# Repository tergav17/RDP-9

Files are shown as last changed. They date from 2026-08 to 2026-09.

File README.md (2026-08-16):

# RDP-9

## Project Description

This project aims to build an ISA-compatible clone of the DEC PDP-9 system using primarily technology from the late 1970s - early 1980s period. I did this to ensure my design followed the same constraints that later genuine minicomputer systems were built with, while being able to significantly reduce the size and complexity compared to an actual PDP-9. The specifics are as follows

- Use only 74-series logic and other similar TTL logic level parts that would be available around the later 1970s timeframe. The exception to this is RAM, which I plan to use more “modern” SRAM chips instead of torturing myself with dynamic RAM.
- No FPGAs, PALs, GALs, microcontrollers, etc in the main processor path. The only exception to this is using standard 27C style ROM chips to hold the microcode.
- Usage of a period correct microcontroller or microprocessor for the disk / drum subsystem. Using another simpler processor to control complex devices like disks was done frequently on other minicomputer designs, so I’ll be doing it here too.

My end goal is to build a system that is capable of running most of the interesting software of the period. This includes DECsys, ADSS, DOS-15, and UNIX V0. To do this, the system will need:

- Full compatibility with the PDP-9 instruction set. This includes EAE instructions and extended memory
- The ability to hook up to a real or emulated paper tape punch / reader.
- The ability to hook up to a real or emulated ASR-33 teletype or similar serial terminal
- 8" floppy drive interface in place of DECtape. Software will require patching but it's better than trying to emulate DECtape
- IDE hard drive support using RB09/RF09 interface 

## Theory of Operation

Due to the complexity involved with the architecture of the DEC PDP-9, the system is split into two subsystems:

The first subsystem is the processor itself. It has a full 18-bit datapath with 15-bit address bus, and is implemented entirely using TTL logic.

The second subsystem is the I/O bus. This is directly controlled by the processor itself and is capable of servicing the following operations:

- Device interrupts
- IOT transactions
- Add-to-memory operations
- Data channel transfers
- DMA transfers
- READ-IN operation

### Device Interrupts

Device interrupts simply tell the processor to begin an interrupt operation. When an interrupt is accepted, the I/O bus will be notified of the action
and is responsible for turning off the "Program Interrupt" flag. If this does not happen, interrupts will continuously loop. 

#### Steps:

1. Interrupt is accepted. MA is completely zeroed and the "INTERRUPT_DETECT" pulse is asserted for this clock cycle.

2. PC is stored in MB, OB

3. The logical OR of MB and OB is place in CORE at MA. The crossbar will add the LINK and MEMM flags

4. MA + 1 is placed in the PC. Extend is enabled to ensure that bank 0 is selected. The next fetch will ignore device requests

### IOT Transactions

IOT transactions allow data to be transferred to or from the accumulator. IOTs also allow for skips to be requested. Every IOT is treated by the CPU
as a Read-Modify-Write operation. By using the "EXTRN" signal, devices can notify the processor to read from the I/O bus instead of the writeback register.
When the I/O bus is being sampled, the "IOT_SKIP" signal can be asserted to tell the processor to perform an addition increment of the program counter.

A wait signal is sampled at the beginning of the IOT as well. This can be used to add cycles to the writeback phase of the IOT if the device needs it.

#### Steps:

1. IOT transaction begins. Device address is placed on the I/O address bus. AC (or 0 if the flag is set) is written to the WRTBK register.

2. Signal "IOT_PULSE" is asserted.

3. Signal "IOT_PULSE" remains asserted. External input is sampled into MB. Signal "EXTRN" must be asserted to take value from device bus.

4. IF "IOT_WAIT" is asserted, goto step 3 in place. No IOT signals are asserted. Interally, the CPU is performing the logical OR and writeback of potential provided data.

5. No IOT signals are asserted. Internally, the CPU will perform the skip here if it has been requested. The next fetch cycle will ignore interrupts and device requests.

### Device Requests

The final three transaction types (Add-to-memory, data-channels, and DMA transfers all share the "device request" pathway.

#### Steps:

1. Signal "REQ_ADDR_PHASE" and "DEV_REQ_GRANT" asserted and held. External value written to MA.

2. If DMA is selected, core is read at MA and written to WRTBK with next as step 8. Otherwise core is read at MA and written to MB, OB. "REQ_ADDR_PHASE" held

3. Value in MB, OB incremented and written back to core at MA and OB. "REQ_ADDR_PHASE" held

4. Value in MA incremented. If add to memory selected, Jump to fetch without device request logic. "INCREMENT_ZERO_PUSLE" will be generated if needed. "REQ_ADDR_PHASE" held

5. Core is read at MA and written to MB, OB.

6. Value in MB, OB incremented and written back to core at MA and MA

7. Core is read at MA and written to WRTBK

8. External value written to core at MA. "DEV_REQ_GRANT" reset. Jump to fetch without device request logic

### READ-IN Operation

The read-in is used to transfer a set series of words into memory from one of the I/O devices. Only one I/O device can be be allowed to respond to READ-IN
at any one time. When a READ-IN transaction is active, the CPU will stall until the designated device signals that it is ready. The device will either signal
the CPU to commence another READ-IN cycle, or to terminate the READ-IN after any given transfer.

#### Steps:

1. SWR is moved into PC

2. "READ_IN_PULSE" is asserted, step will loop till either "IOT_WAIT" or "IOT_SKIP" are asserted.

3. "READ_IN_PULSE" remains asserted. EXTRN is moved into core at PC. Continue having the constant value asserted.

4. "READ_IN_PULSE" reset. If "IOT_SKIP" is asserted, jump to CONT logic. Otherwise move PC + 1 into PC

5. Null phase, "READ_IN_PULSE" remains reset.

6. Null phase, "READ_IN_PULSE" remains reset. Jump to step 2 on completion

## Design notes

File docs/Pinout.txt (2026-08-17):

/* Front Panel */

RDP-9A-FPR-0	Register Front Panel Segment (MB, AC, MQ, SWR)
PRD-9A-FPA-0	Address Front Panel Segment (Flags, MA, PC, CTRL Switches)

/* Backplane */

RDP-9A-BKP-0	CPU + I/O Backplane

/* CPU Cards */

RDP-9A-CTL-0	Microcode Control Card
RDP-9A-REG-0	Register File Card
RDP-9A-ALU-0	ALU Card
RDP-9A-MEM-0	Memory / Addressing Card

/* I/O Cards */

RDP-9A-TTC-0	TTY / Clock / Flags Card
RDP-9A-PRB-0	Paper tape / RB Emulator Card

/* CPU Backplane Pinout */

SIGNAL			COUNT	DESCRIPTION				PULL_UP		SOURCE	DONE
D				18		Data Bus							N/A		X
A				15		Address Bus							N/A		X
STEP_ZERO		1		STEP Register Zero					REG		X
*PI_ENABLE		1		Interrupt Enable		X			BKP		X
*MEMM_ENABLE	1		Ext Memory Enable		X			BKP		X
*PROT_ENABLE	1		Protection Enable 		X			BKP		X
*DMA_REQ		1		DMA Request				X			BKP		X
*CHAN_REQ		1		Data Channel Request	X			BKP		X
*DEV_REQ		1		Device request			X			BKP		X
*INT_REQ		1		Interrupt request		X			BKP		X
*IOT_SKIP		1		IOT Skip				X			BKP		X
*IOT_WAIT		1		IOT Wait				X			BKP		X
*REST_PEND		1		Restore Pending			X			BKP		X
*IOT_SKIP_L		1		IOT Skip Latched					ALU		X
FLAG_ZERO		1		OB Zero Flag						ALU		X
FLAG_SIGN		1		OB Sign Flag						ALU		X
FLAG_LINK		1		Link Flag							ALU		X
FLAG_LINK_INIT	1		Link Init Flag						ALU		X
FLAG_AC_SIGN	1		AC Sign Flag						ALU		X
BUS_SELECT		3		Data Bus Selector					CTL		X
*SELECT_AC		1		Bus Select AC						CTL		X
*SELECT_STEP	1		Bus Select STEP						CTL		X
*SELECT_MQ		1		Bus Select MQ						CTL		X
*SELECT_CROSS	1		Bus Select Crossbar					CTL		X
*SELECT_ALU		1		Bus Select ALU						CTL		X
*SELECT_CORE	1		Bus Select Core						CTL		X
*SELECT_SWR		1		Bus Select SWR						CTL		X
*SELECT_EXTRN	1		Bus Select External					CTL		X
*LATCH_IR		1		Latch IR Register					CTL		X
*LATCH_MA		1		Latch MA Register					CTL		X
*LATCH_PC		1		Latch PC Register					CTL		X
*LATCH_AC		1		Latch AC Register					CTL		X
*LATCH_STEP		1		Latch STEP Register					CTL		X
*LATCH_MQ		1		Latch MQ Register					CTL		X
*LATCH_MB		1		Latch MB Register					CTL		X
*LATCH_WRTBK	1		Latch WRTBK Register				CTL		X
*LATCH_OB		1		Latch OB Register					CTL		X
*WRITE_CORE		1		Write to Core						CTL		X
SELECT_PCMA		1		Select PC / MA						CTL		X
HALT			1		Halt Indicator						CTL		X
ADDR_MODE		2		Address Register Mode				CTL		X
CTL_CONST		1		Control Constant Value				CTL		X
*IOT_PULSE		1		IOT Pulse							CTL		X
*DRQ_GRANT		1		Device Request Grant				CTL		X
REQ_ADDR		1		IO Request Address					CTL		X
*JMP_I_DETECT	1		JMP I Detect						CTL		X
*INT_DETECT		1		Interrupt Detect					CTL		X
*READ_IN_PULSE	1		Read In Pulse						CTL		X
ALUO			3		ALU Operation						CTL		X
LINKS			2		Link Select							CTL		X
ALU_SHIFT		1		ALU Select Shifter					CTL		X
ALU_ONES		1		ALU Select Ones Comp				CTL		X
MA_AUTO_INX		1		MA Auto Index Flag					MEM		X
NEXT_BANK0		2		Next Memory Bank					MEM		X
CLK				1		Clock								BKP
FP				4		Front Panel Status					FTP
*CAF			1		Clear All Flags						BKP
*RESET			1		CPU RESET							BKP
 
			Control Connector

GND				A01 C01		+5V
N/C				A02 C02		N/C
*PI_ENABLE		A03 C03		STEP_ZERO
*MEMM_ENABLE	A04 C04		FLAG_ZERO
*PROT_ENABLE	A05 C05		FLAG_SIGN
*DMA_REQ		A06 C06		FLAG_LINK
*CHAN_REQ		A07 C07		FLAG_LINK_INIT
*DEV_REQ		A08 C08		FLAG_AC_SIGN
*INT_REQ		A09 C09		BUS_SELECT0
*IOT_SKIP		A10 C10		BUS_SELECT1
*IOT_WAIT		A11 C11		BUS_SELECT2
*IOT_SKIP_L		A12 C12		*SELECT_AC
*LATCH_IR		A13 C13		*SELECT_STEP
*LATCH_MA		A14 C14		*SELECT_MQ
*LATCH_PC		A15 C15		*SELECT_CROSS
*LATCH_AC		A16 C16		*SELECT_ALU
*LATCH_STEP		A17 C17		*SELECT_CORE
*LATCH_MQ		A18 C18		*SELECT_SWR
*LATCH_MB		A19 C19		*SELECT_EXTRN
*LATCH_WRTBK	A20 C20		*IOT_PULSE
*LATCH_OB		A21 C21		*DRQ_GRANT
*WRITE_CORE		A22 C22		REQ_ADDR
SELECT_PCMA		A23 C23		*JMP_I_DETECT
ALUO0			A24 C24		*INT_DETECT
ALUO1			A25 C25		*READ_IN_PULSE
ALUO2			A26 C26		HALT
LINKS0			A27 C27		ADDR_MODE0
LINKS1			A28 C28		ADDR_MODE1
ALU_SHIFT		A29 C29		CTL_CONST
ALU_ONES		A30 C30		EXTRA0
N/C				A31 C31		+12V
+5V				A32 C32		GND

			Data Connector
			
GND				A01 C01		+5V
N/C				A02 C02		N/C
D0				A03 C03		A0
D1				A04 C04		A1
D2				A05 C05		A2
D3				A06 C06		A3
D4				A07 C07		A4
D5				A08 C08		A5
D6				A09 C09		A6
D7				A10 C10		A7
D8				A11 C11		A8
D9				A12 C12		A9
D10				A13 C13		A10
D11				A14 C14		A11
D12				A15 C15		A12
D13				A16 C16		A13
D14				A17 C17		A14
D15				A18 C18		SC0
D16				A19 C19		SC1
D17				A20 C20		SC2
*RESET			A21 C21		SC3
*CAF			A22 C22		SC4
CLK				A23 C23		SC5
EXTRA1			A24 C24		EXTRA2
EXTRA3			A25 C25		EXTRA4
EXTRA5			A26 C26		EXTRA6
NEXT_BANK0		A27 C27		NEXT_BANK1
*REST_PEND		A28 C28		MA_AUTO_INX
FP0				A29 C29		FP1
FP2				A30 C30		FP3
N/C				A31 C31		+12V
+5V				A32 C32		GND

/* IO Backplane Pinout */

SIGNAL			COUNT	DESCRIPTION				PULL_UP		SOURCE	DONE
ID				18		I/O Data Bus						N/A		X
A_DEVICE		6		Device ID							BKP		X
A_SUBDEV		2		Sub-Device ID						BKP		X
A_PULSE			3		I/O Pulse							BKP		X
REQ_ADDR		1		Request Address						BKP		X
*IORS_FLAG		4		User-Defined IORS		X			N/A		X
*PTR_FLAG		1		Paper Tape Reader Flag	X			PRB		X
*PTP_FLAG		1		Paper Tape Punch Flag	X			PRB		X
*PTR_TAPE		1		Read Tape Detect		X			PRB		X
*PTP_TAPE		1		Punch Tape Detect		X			PRB		X
*PI_ENABLE		1		Interrupt Enabled		X			FLG		X
*MEMM_ENABLE	1		Ext Memory Enabled		X			FLG		X
*REST_PEND		1		Restore Pending			X			FLG		X
*INT_REQ		1		Interrupt Request		X			N/A		X
*DMA_REQ		1		DMA Request				X			N/A		X
*CHAN_REQ		1		Channel Request			X			N/A		X
*EXTERNAL		1		External Data			X			N/A		X
*IOT_SKIP		1		IOT Skip Request		X			N/A		X
*IOT_WAIT		1		IOT Wait Request		X			N/A		X
*DRQ_GRANT		1		Data Request Grant					BKP		X
*INT_DETECT		1		Interrupt Detect					BKP		X
*JMP_I_DETECT	1		JMP I Detect						BKP		X
*IOT_PULSE		1		IOT Pulse							BKP		X
*READ_IN_PULSE	1		Read In Pulse						BKP		X
*READ_IN_CLEAR	1		Read In Clear						BKP		X
*INCREMENT_ZERO	1		Increment Zero						BKP		X
CLK				1		Clock								BKP		X
*CAF			1		Clear All Flags						BKP		X
*CAF_REQ		1		Clear All Flags Request	X			N/A		X
*RESET			1		CPU Reset							BKP		X

			  I/O Connector

GND				A01 C01		+5V
N/C				A02 C02		*IOT_SKIP
ID0				A03 C03		A_DEVICE0
ID1				A04 C04		A_DEVICE1
ID2				A05 C05		A_DEVICE2
ID3				A06 C06		A_DEVICE3
ID4				A07 C07		A_DEVICE4
ID5				A08 C08		A_DEVICE5
ID6				A09 C09		A_SUBDEV0
ID7				A10 C10		A_SUBDEV1
ID8				A11 C11		A_PULSE0
ID9				A12 C12		A_PULSE1
ID10			A13 C13		A_PULSE2
ID11			A14 C14		*IORS_FLAG0
ID12			A15 C15		*IORS_FLAG1
ID13			A16 C16		*IORS_FLAG2
ID14			A17 C17		*IORS_FLAG3
ID15			A18 C18		*PTR_FLAG
ID16			A19 C19		*PTP_FLAG
ID17			A20 C20		*PTR_TAPE
*RESET			A21 C21		*PTP_TAPE
*CAF			A22 C22		*PI_ENABLE
CLK				A23 C23		*MEMM_ENABLE
REQ_ADDR		A24 C24		*REST_PEND
*DRQ_GRANT		A25 C25		*INT_REQ
*INT_DETECT		A26 C26		*DMA_REQ
*JMP_I_DETECT	A27 C27		*CHAN_REQ
*IOT_PULSE		A28 C28		*EXTERNAL
*READ_IN_PULSE	A29 C29		*CAF_REQ
*READ_IN_CLEAR	A30 C30		*INCREMENT_ZERO
*IOT_WAIT		A31 C31		+12V
+5V				A32 C32		GND

TODO:
DRQ_GRANT
IOT_PULSE
JMP_I_DETECT
INT_DETECT
READ_IN_PULSE

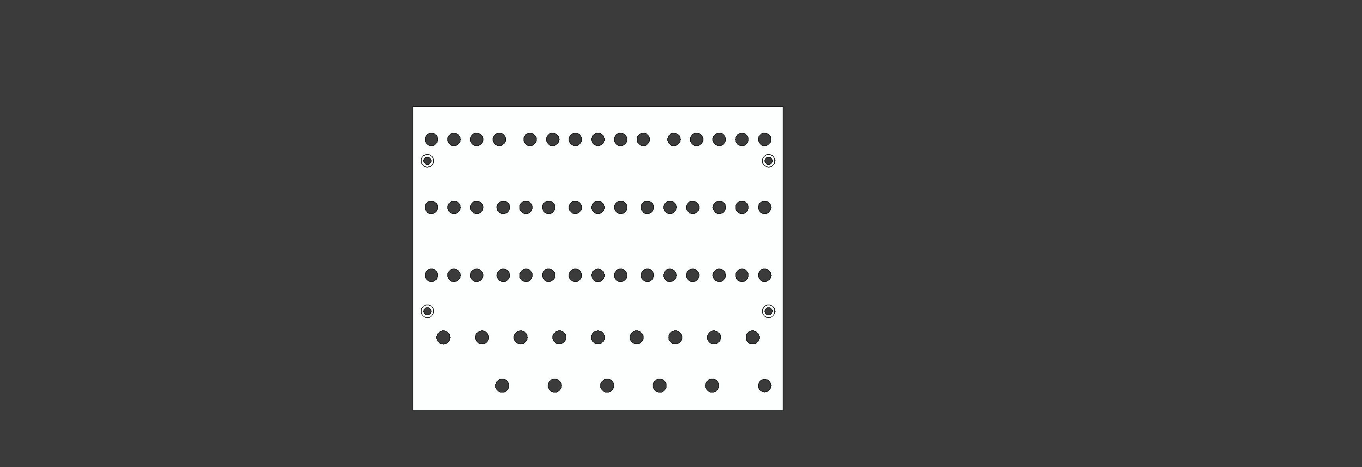
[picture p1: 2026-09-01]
freecad/Front Panels/Artwork/Address Panel.png

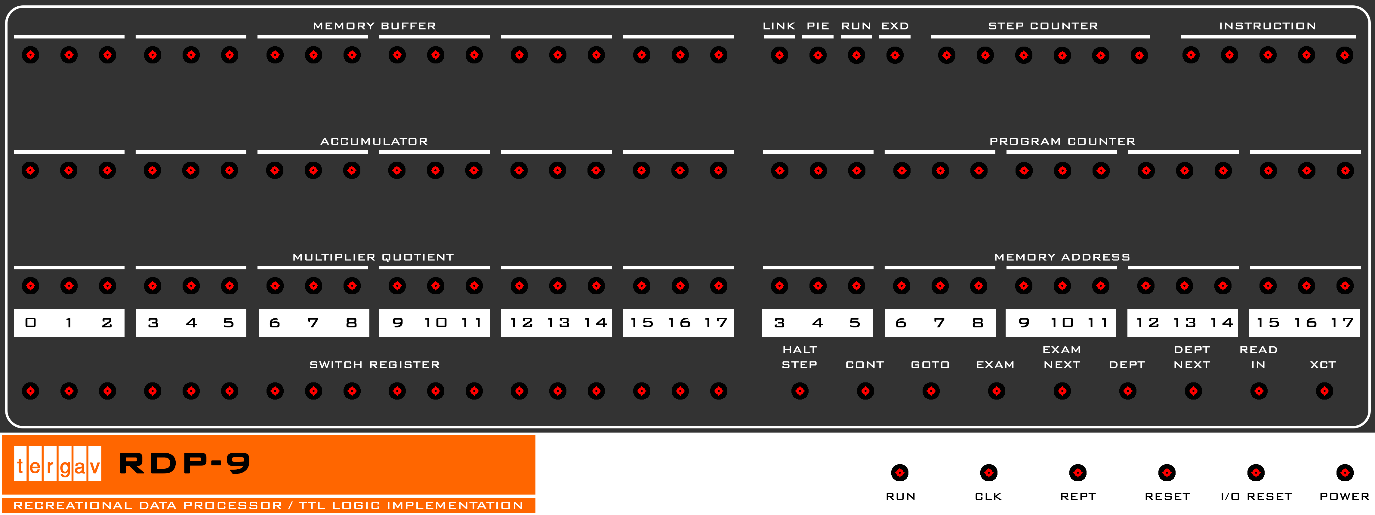
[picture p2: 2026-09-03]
freecad/Front Panels/Artwork/Front Panel Art.png

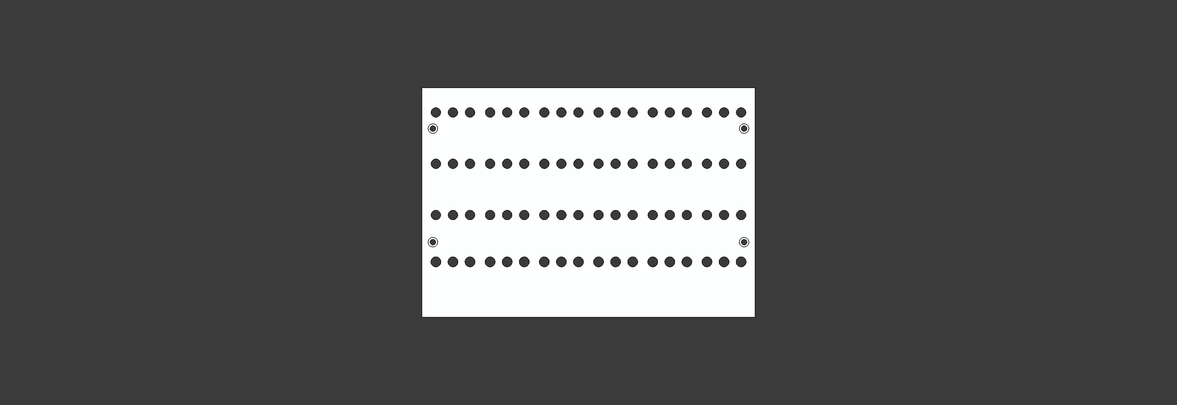
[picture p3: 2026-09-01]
freecad/Front Panels/Artwork/Data Panel.png

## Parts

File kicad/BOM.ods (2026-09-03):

Part | Quantity | Footprint | Link | Received?
Capacitor 10nf | 1 |  | https://www.aliexpress.us/item/3256804202811504.html | Yes
Capacitor 0.1uF | 188 |  | https://www.aliexpress.us/item/2251832762745366.html | Yes
Capacitor 1uF Polarized | 4 |  | https://www.aliexpress.us/item/3256811542313899.html | Yes
Capacitor 10uF | 1 |  | https://www.aliexpress.us/item/3256811448609794.html | Yes
Capacitor 100uf Polarized | 8 |  | https://www.aliexpress.us/item/3256811625053645.html | Yes
DIN41612 02x32 Male Horizontal | 14 |  | https://www.aliexpress.us/item/3256802176673542.html | Yes
DIN41612 02x32 Female Vertical | 14 |  | https://www.aliexpress.us/item/3256802176673542.html | Yes
IDC Header 02x05 Horizontal Male | 2 |  | https://www.aliexpress.us/item/3256810262867888.html
IDC Header 02x06 Horizontal Male | 1 |  | https://www.aliexpress.us/item/3256810262867888.html
IDC Header 02x25 Vertical Male | 4 |  | https://www.aliexpress.us/item/3256810262867888.html
IDC Ribbon 02x25 Female | 4 |  | https://www.aliexpress.us/item/3256810531981806.html | Yes
01x04 Horizontal Header 2.54mm Pitch | 1
01x06 Horizontal Header 2.54mm Pitch | 2
01x02 Vertical Header 2.54mm Pitch | 6
01x03 Vertical Header 2.54mm Pitch | 4
01x04 Vertical Header 2.54mm Pitch | 1
DIP Switch x8 | 4 |  | https://www.aliexpress.us/item/3256809280768040.html | Yes
MTS 102 SPDT Latching | 25 |  |  | Yes
MTS 112 SPDT Momentary | 9 |  | https://www.aliexpress.us/item/2255799991661437.html | Yes
Resistor Network 330R SIP6 | 20 |  | https://www.aliexpress.us/item/3256812262968478.html | Yes
Resistor Network 4.7K SIP9 | 4 |  | https://www.aliexpress.us/item/3256812262968478.html | Yes
Resistor 330R | 1 |  |  | Yes
Resistor 1K | 2 |  |  | Yes
Resistor 4.7K | 136 |  |  | Yes
LED 5mm | 100 |  |  | Yes
74LS273 | 1 | DIP-20 | https://www.aliexpress.us/item/2251832857965208.html | Yes
74LS377 | 42 | DIP-20 | https://www.aliexpress.us/item/3256802490446944.html | Yes
74LS253 | 28 | DIP-16 | https://www.aliexpress.us/item/3256805592998309.html | Yes
74F382 | 5 | DIP-20 | https://www.utsource.net/sch/74f382.html | Yes
74LS283 | 9 | DIP-16 | https://www.aliexpress.us/item/2251832835197311.html | Yes
74LS240 | 3 | DIP-20 | https://www.aliexpress.us/item/3256812092390454.html | Yes
74LS244 | 21 | DIP-20 | https://www.aliexpress.us/item/3256808917743982.html | Yes
74LS245 | 6 | DIP-20 | https://www.aliexpress.us/item/3256808917743982.html | Yes
74LS86 | 2 | DIP-14 | https://www.aliexpress.us/item/3256811913323978.html | Yes
74LS08 | 7 | DIP-14 | https://www.aliexpress.us/item/3256811913323978.html | Yes
74LS32 | 14 | DIP-14 | https://www.aliexpress.us/item/3256811913323978.html | Yes
74LS00 | 2 | DIP-14 | https://www.aliexpress.us/item/3256811913323978.html | Yes
74LS02 | 3 | DIP-14 | https://www.aliexpress.us/item/3256811913323978.html | Yes
74LS04 | 4 | DIP-14 | https://www.aliexpress.us/item/3256811913323978.html | Yes
74LS06 | 1 | DIP-14 | https://www.aliexpress.us/item/3256812083374376.html | Yes
74LS27 | 3 | DIP-14 | https://www.aliexpress.us/item/3256811913323978.html | Yes
74LS11 | 1 | DIP-14 | https://www.aliexpress.us/item/3256811913323978.html | Yes
74LS257 | 8 | DIP-16 | https://www.aliexpress.us/item/3256804429030947.html | Yes
74LS74 | 9 | DIP-14 | https://www.aliexpress.us/item/3256811913323978.html | Yes
74LS148 | 1 | DIP-16 | https://www.aliexpress.us/item/3256810311064991.html | Yes
74LS138 | 3 | DIP-16 | https://www.aliexpress.us/item/3256810311064991.html | Yes
74LS139 | 1 | DIP-16 | https://www.aliexpress.us/item/2255800643853462.html | Yes
74LS147 | 1 | DIP-16 | https://www.aliexpress.us/item/3256812087819825.html | Yes
74LS151 | 1 | DIP-16 | https://www.aliexpress.us/item/3256810311064991.html | Yes
74LS169 | 6 | DIP-16 | https://www.utsource.net/sch/74f169.html | Yes
27C64 | 5 | DIP-28 | https://www.aliexpress.us/item/3256807269022078.html | Yes
NE555P | 1 | DIP-8 | https://www.aliexpress.us/item/3256810224731924.html | Yes
CY62256 | 3 | DIP-28 | https://www.aliexpress.us/item/2251832811595122.html | Yes
TR1863 | 2 | DIP-40 | https://www.utsource.net/itm/p/9495420.html | Yes
MAX232 | 1 | DIP-16 | https://www.aliexpress.us/item/3256809295289757.html | Yes
2.4576 Mhz Oscillator | 1 | DIP-14 | https://www.aliexpress.us/item/3256809096220004.html | Yes
4 Mhz Oscillator | 1 | DIP-14 | https://www.aliexpress.us/item/2251832678775648.html | Yes
2 Mhz Oscillator | 1 | DIP-14 | https://www.aliexpress.us/item/3256807425018077.html | Yes
1 Mhz Oscillator | 1 | DIP-14 | https://www.aliexpress.us/item/3256807425018077.html | Yes
DIP-8 Socket | 1 |  |  | Yes
DIP-14 Socket | 50 |  |  | Yes
DIP-16 Socket | 59 |  |  | Yes
DIP-20 Socket | 78 |  |  | Yes
DIP-28 Socket | 6 |  |  | Yes
DIP-40 Socket | 2 |  |  | Yes

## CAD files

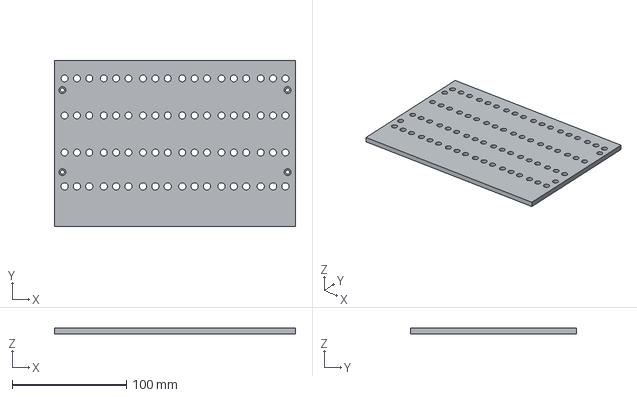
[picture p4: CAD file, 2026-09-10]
freecad/Front Panels/Data Front Panel Mount-Part.step
210.7 x 145.0 x 5.00 mm

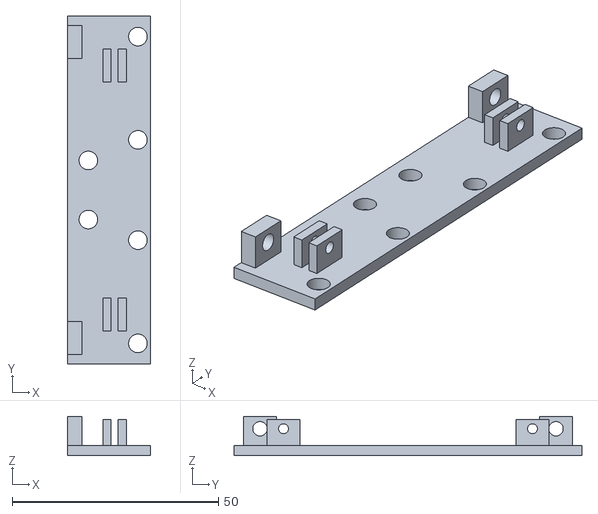
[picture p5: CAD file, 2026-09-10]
freecad/Front Panels/STL/Front Panel Bracket-Part.stl
20.0 x 84.3 x 9.50

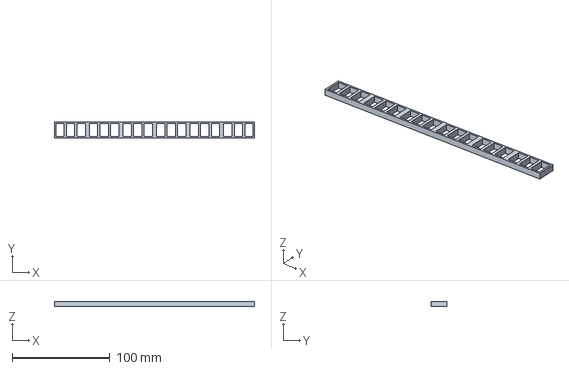
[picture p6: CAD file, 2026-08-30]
freecad/Switch Guides/DSG.FCStd
204.4 x 16.1 x 5.00 mm

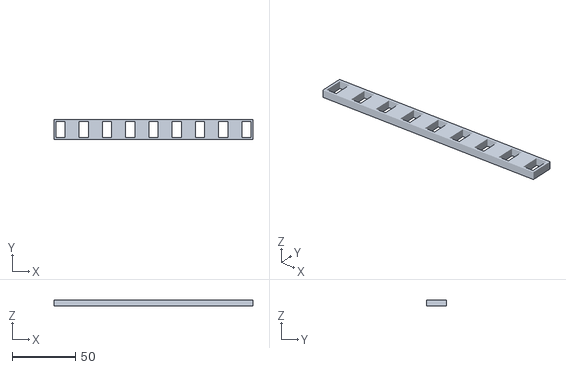
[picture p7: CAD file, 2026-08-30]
freecad/Switch Guides/STL/ASG-Part.stl
157.6 x 15.9 x 5.00

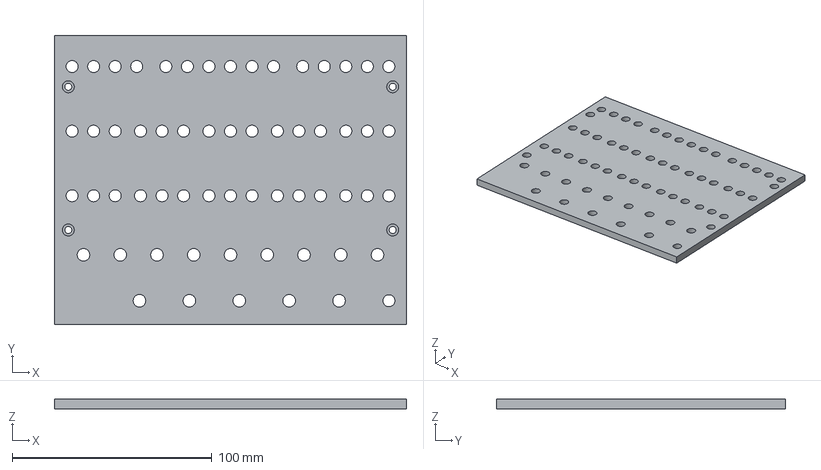
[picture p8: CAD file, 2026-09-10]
freecad/Front Panels/Address Front Panel Mount-Part.step
176.4 x 145.0 x 5.00 mm

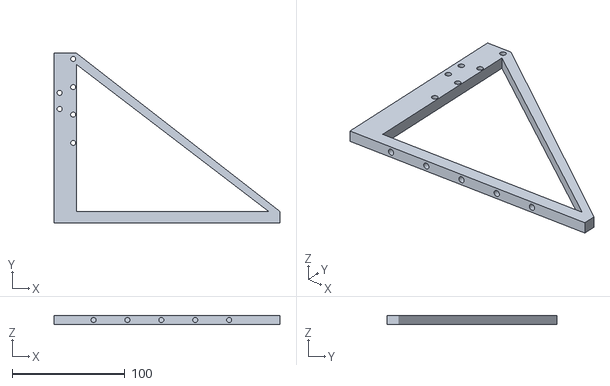
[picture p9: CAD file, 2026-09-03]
freecad/Front Panels/STL/Front Panel Holder-Part.stl
200.0 x 150.0 x 8.00

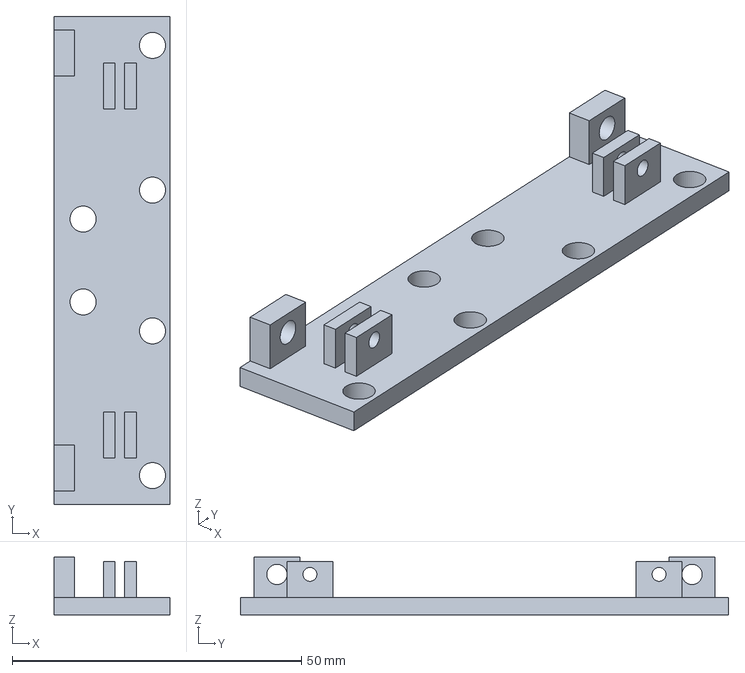
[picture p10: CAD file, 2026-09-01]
freecad/Front Panels/Front Panel Bracket.FCStd
20.0 x 84.3 x 10.0 mm

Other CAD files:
freecad/Switch Guides/ASG.FCStd
freecad/Switch Guides/STL/DSG-Part.stl
freecad/Front Panels/Address Front Panel Mount.FCStd
freecad/Front Panels/Front Panel Holder.FCStd
freecad/Front Panels/Data Front Panel Mount.FCStd
freecad/Front Panels/STL/Address Front Panel Mount-Part.stl
freecad/Front Panels/STL/Data Front Panel Mount-Part.stl

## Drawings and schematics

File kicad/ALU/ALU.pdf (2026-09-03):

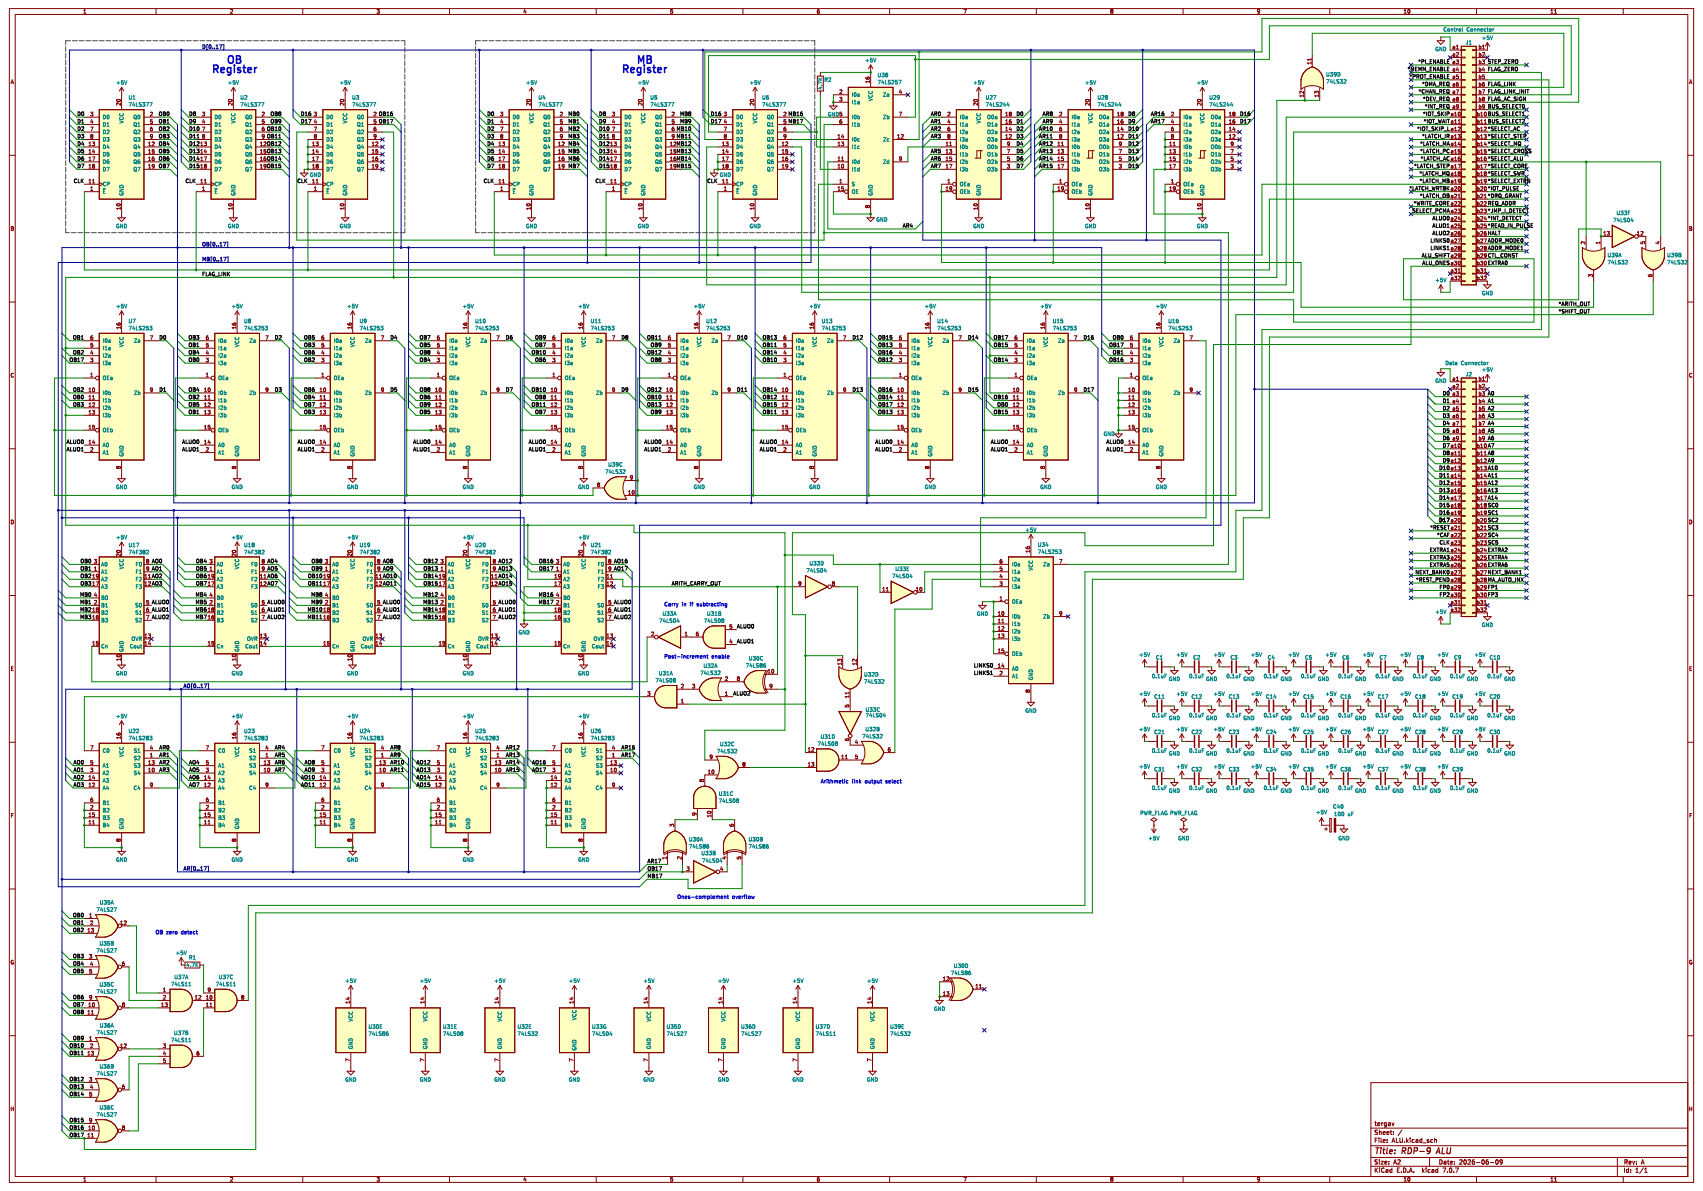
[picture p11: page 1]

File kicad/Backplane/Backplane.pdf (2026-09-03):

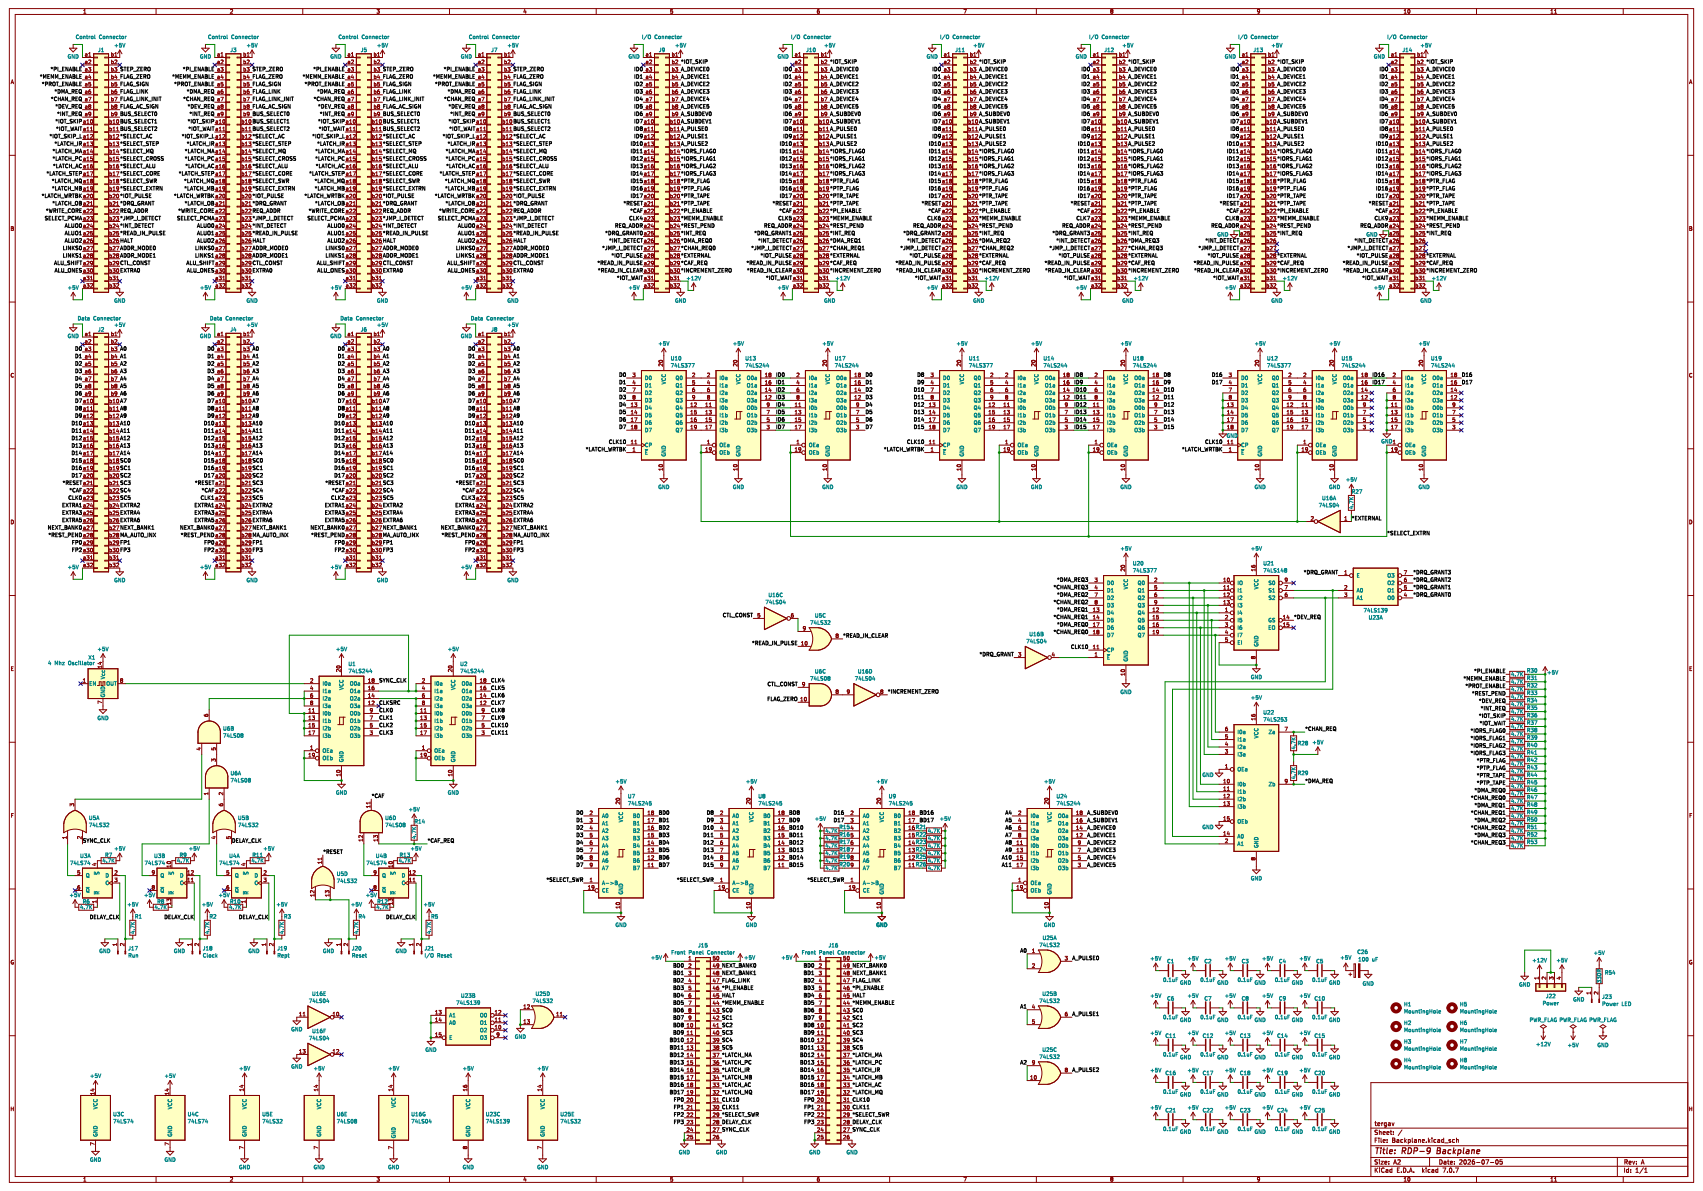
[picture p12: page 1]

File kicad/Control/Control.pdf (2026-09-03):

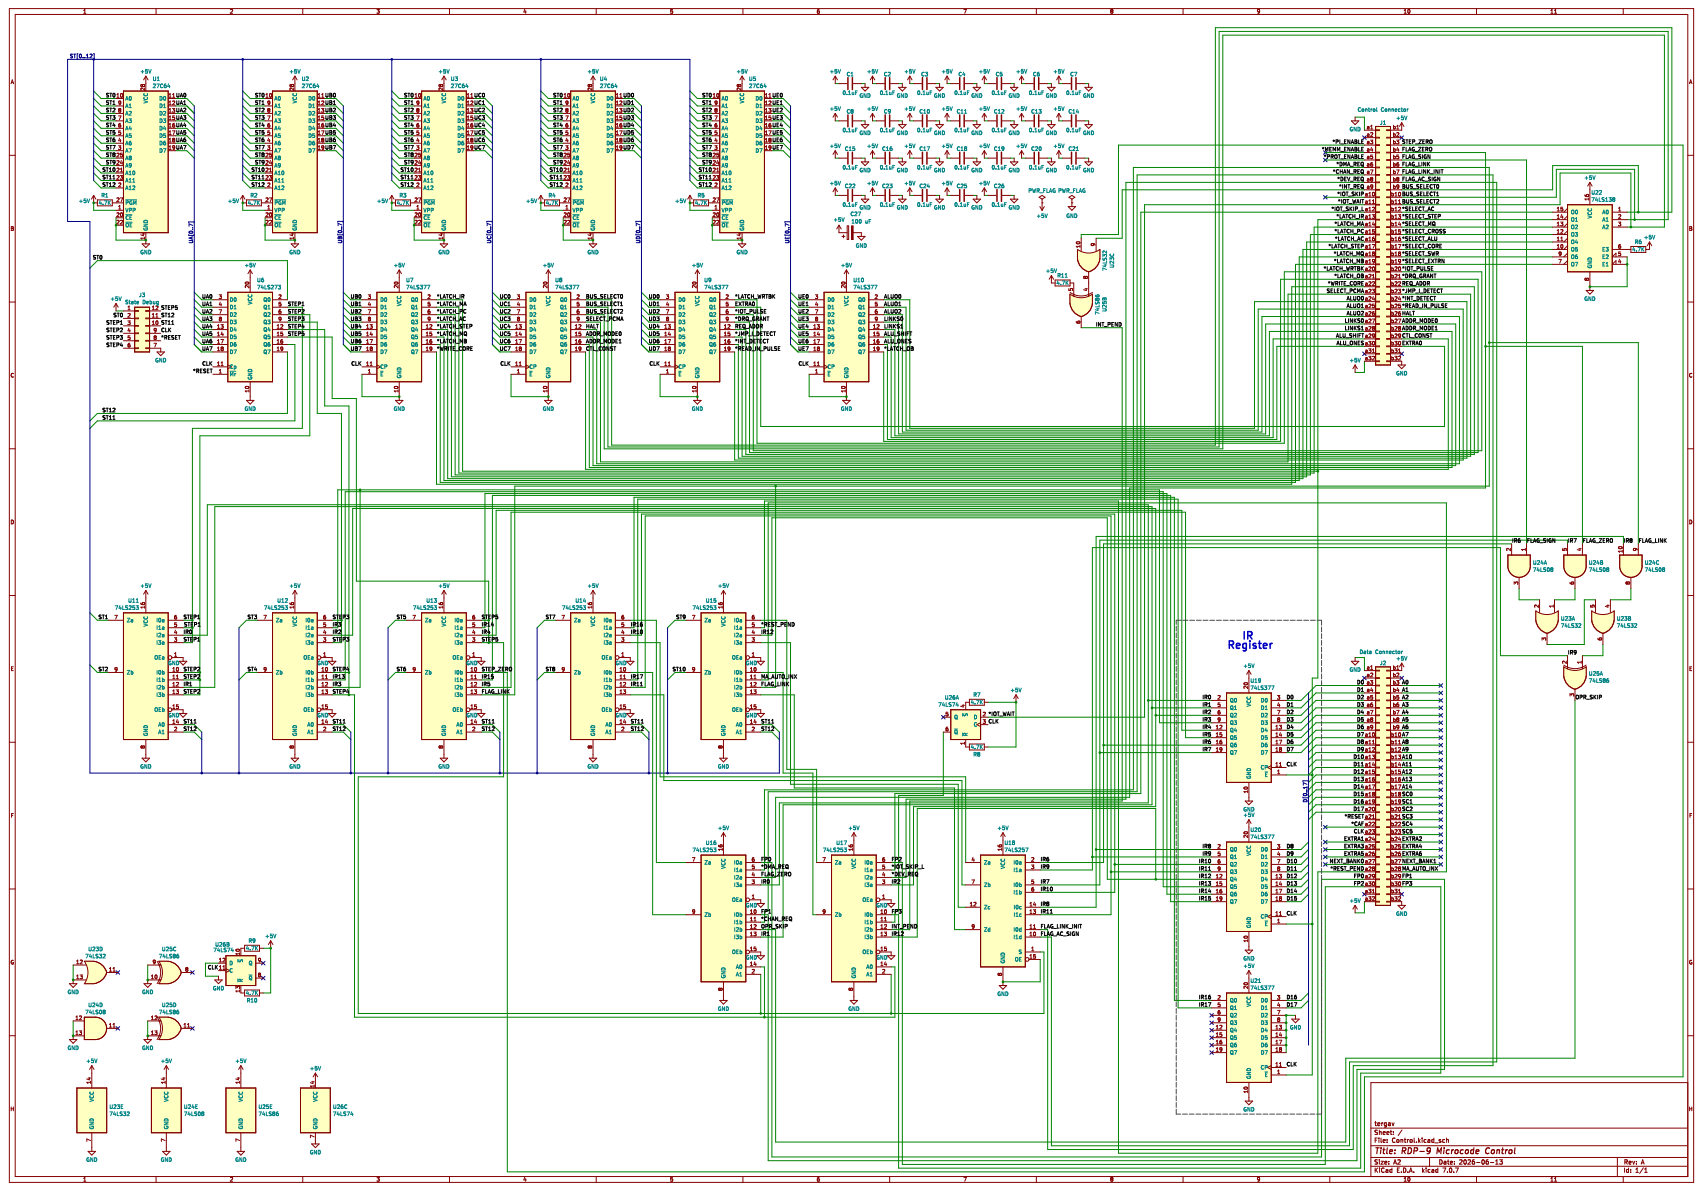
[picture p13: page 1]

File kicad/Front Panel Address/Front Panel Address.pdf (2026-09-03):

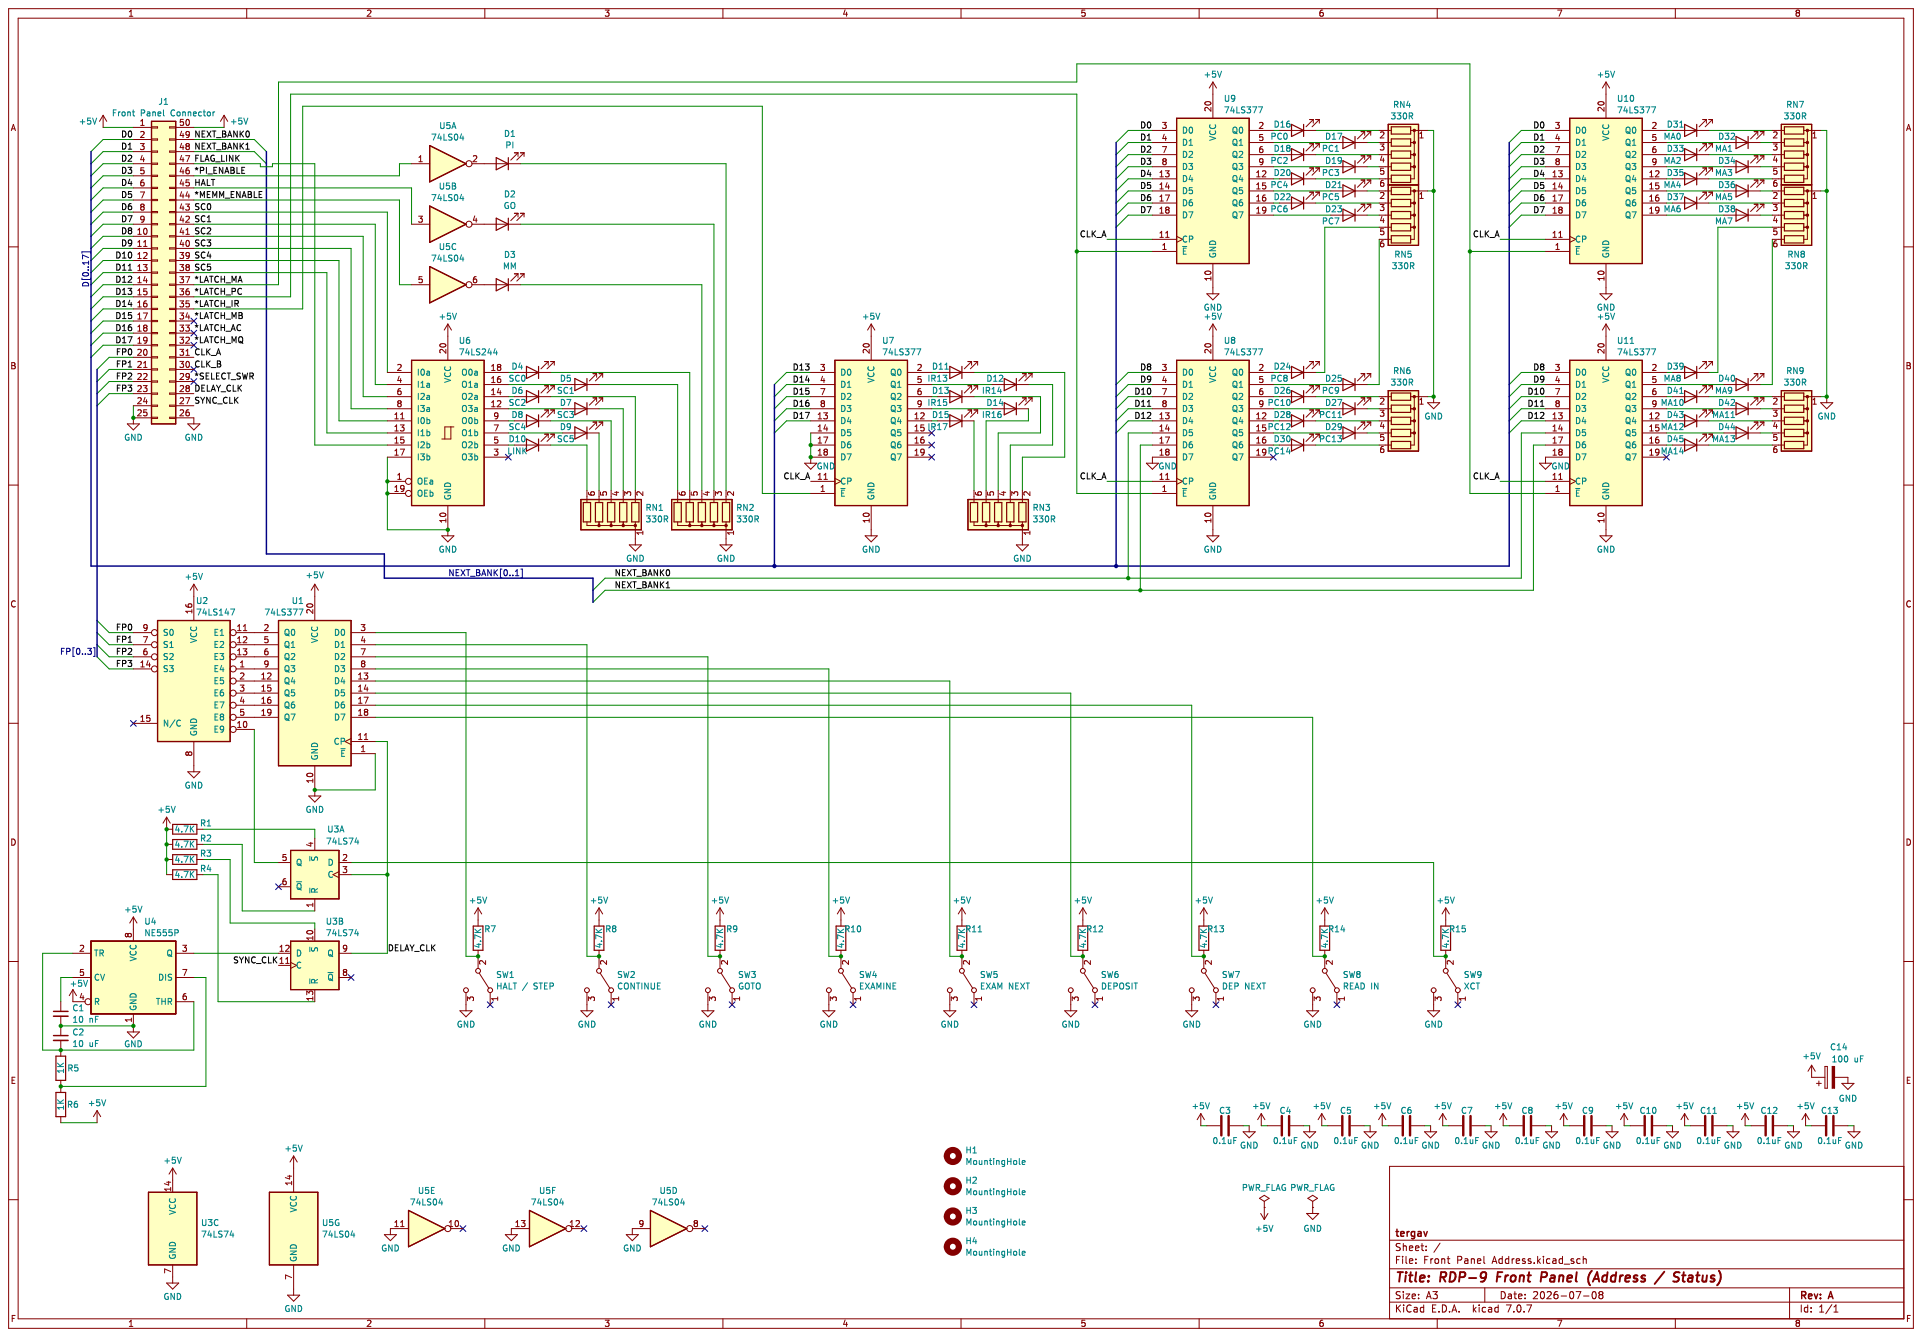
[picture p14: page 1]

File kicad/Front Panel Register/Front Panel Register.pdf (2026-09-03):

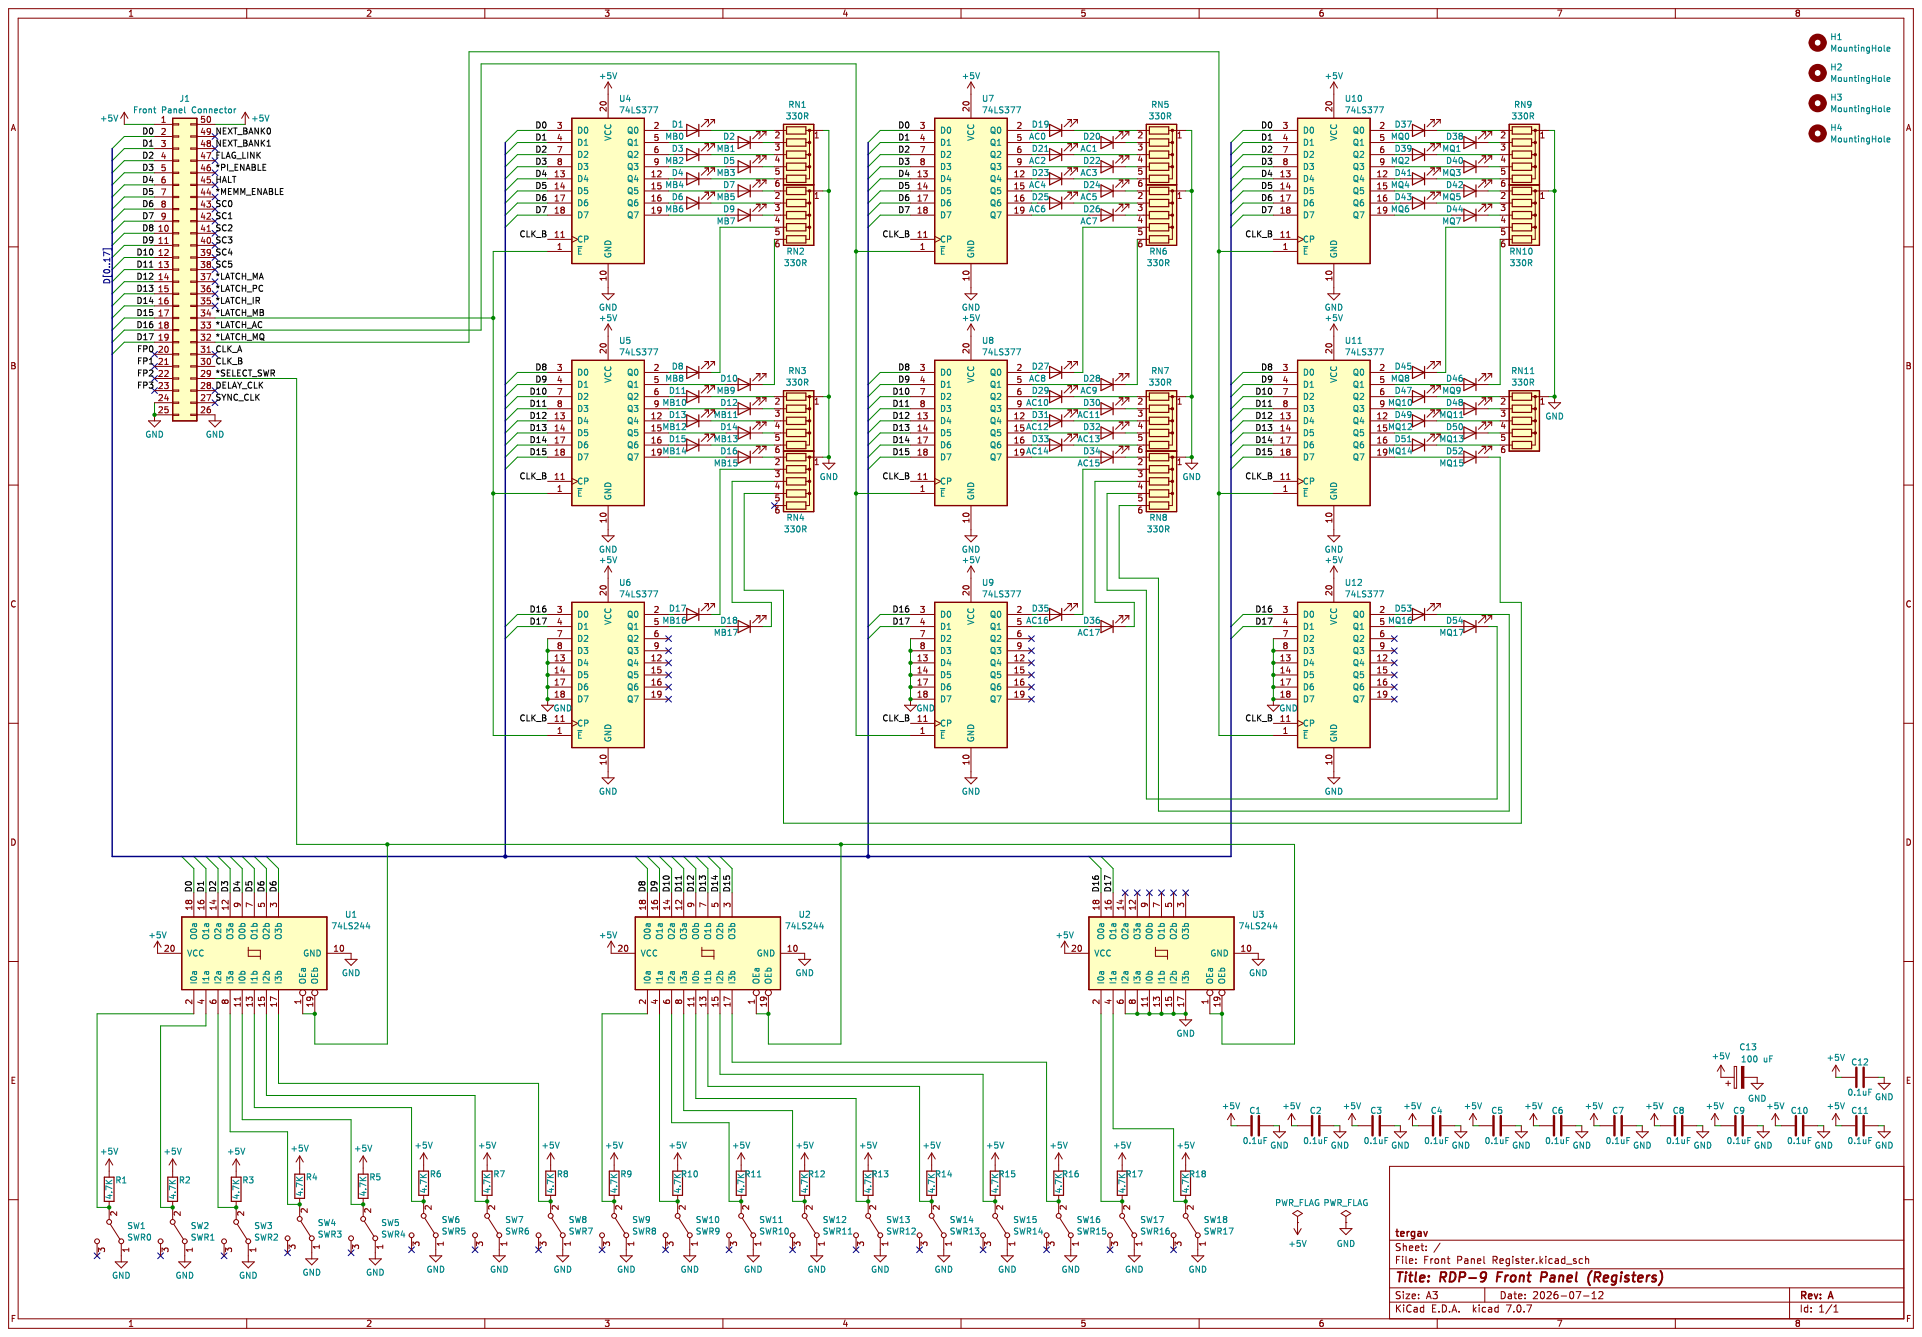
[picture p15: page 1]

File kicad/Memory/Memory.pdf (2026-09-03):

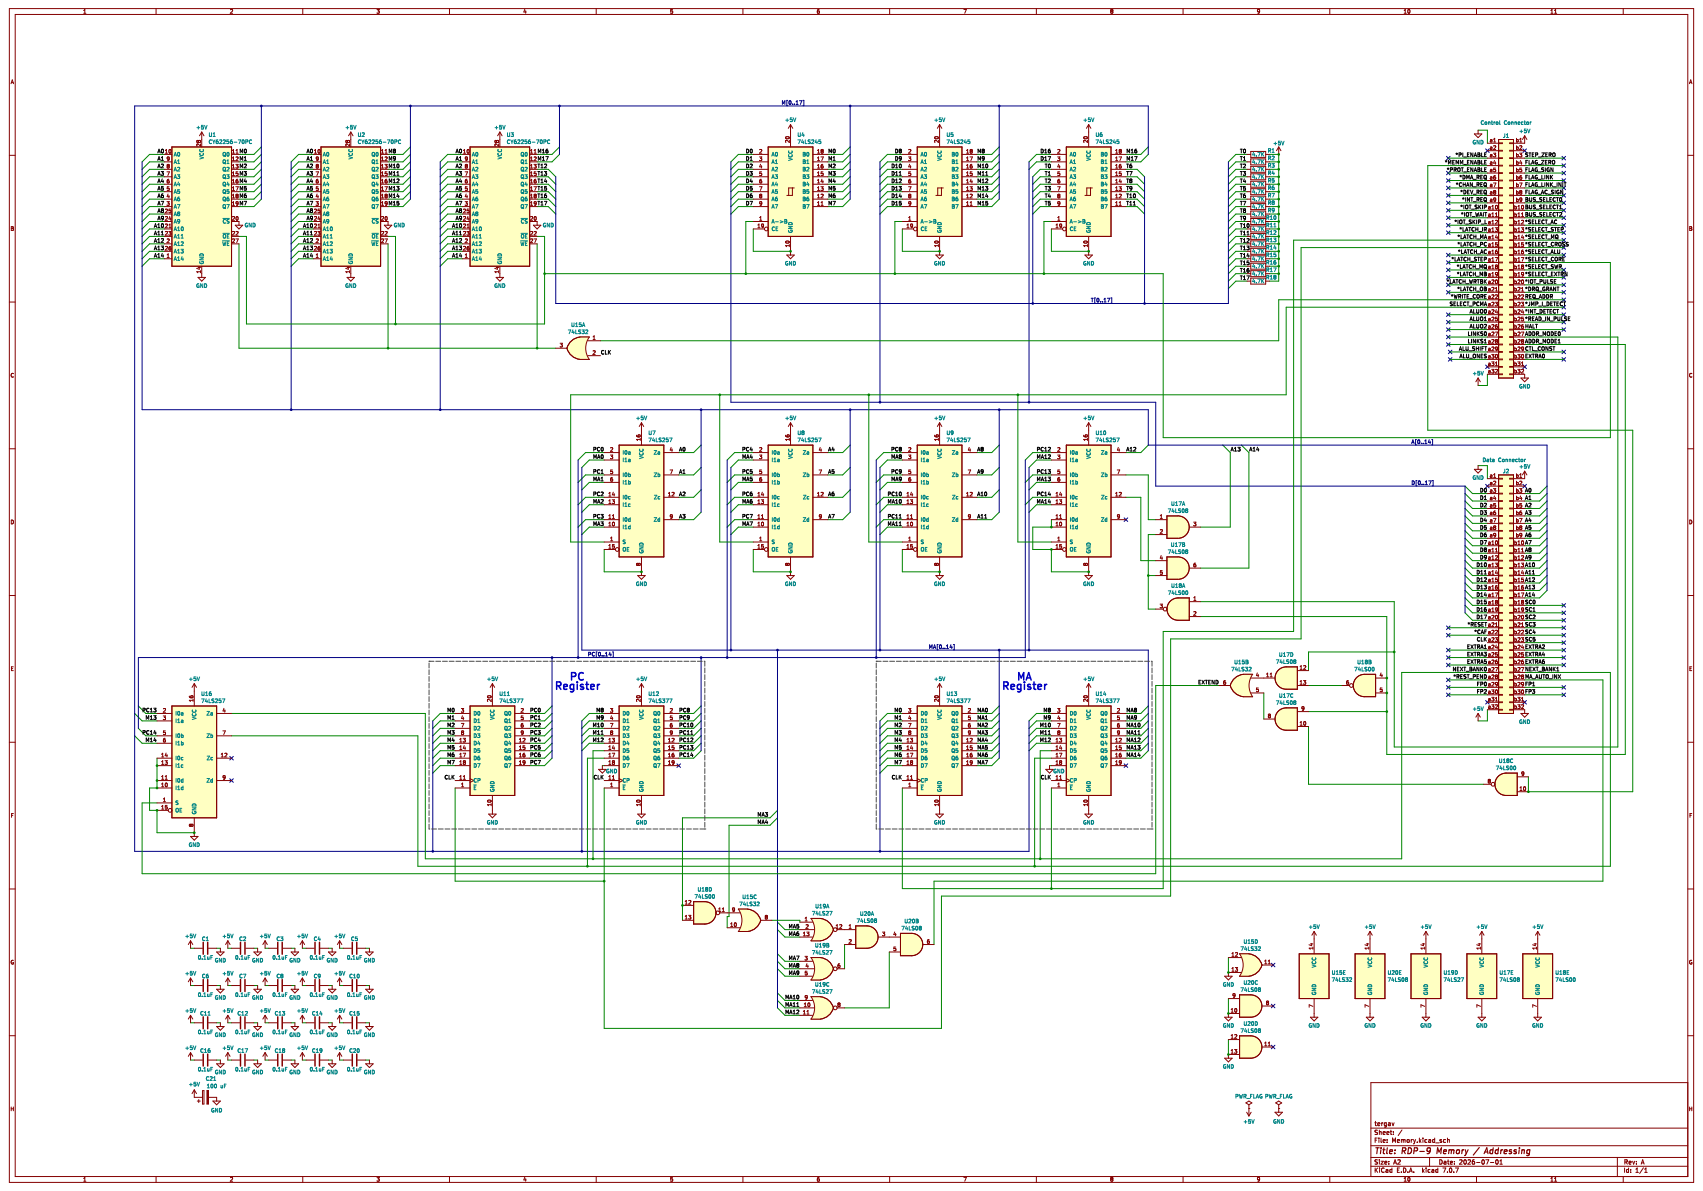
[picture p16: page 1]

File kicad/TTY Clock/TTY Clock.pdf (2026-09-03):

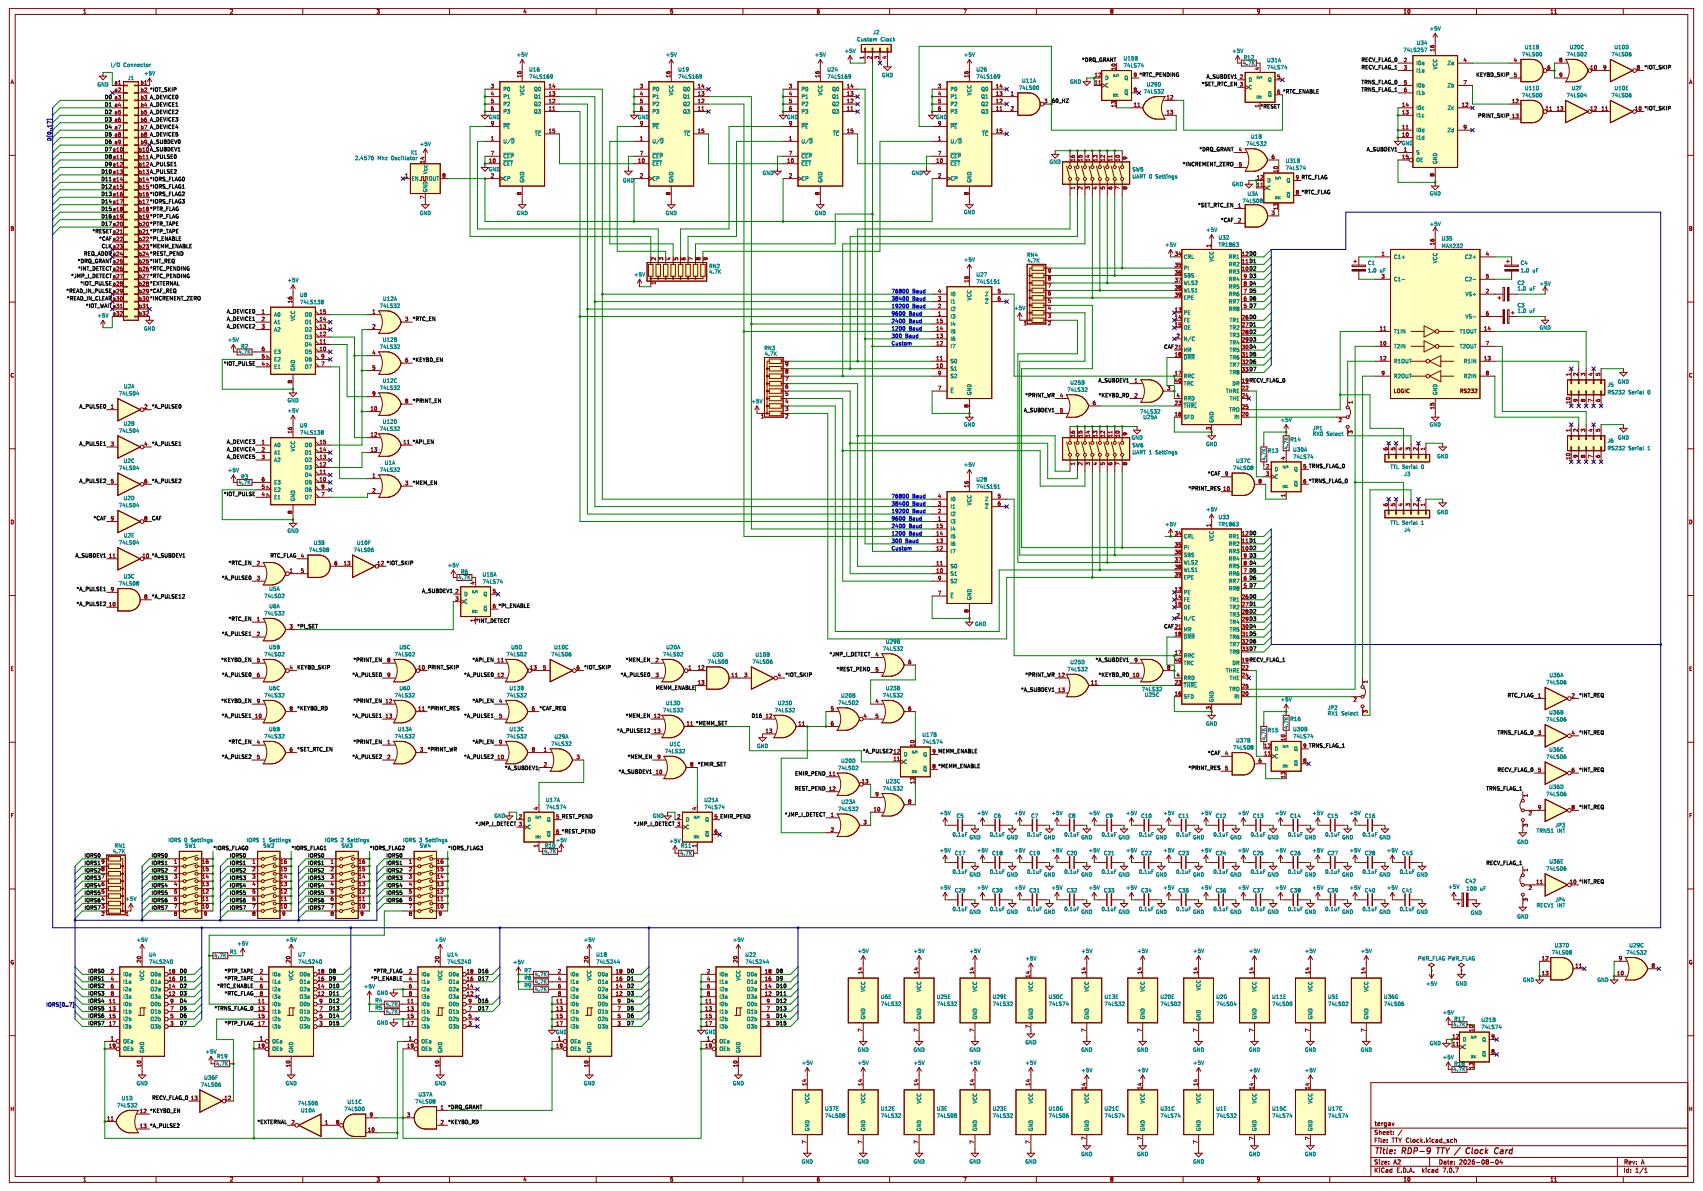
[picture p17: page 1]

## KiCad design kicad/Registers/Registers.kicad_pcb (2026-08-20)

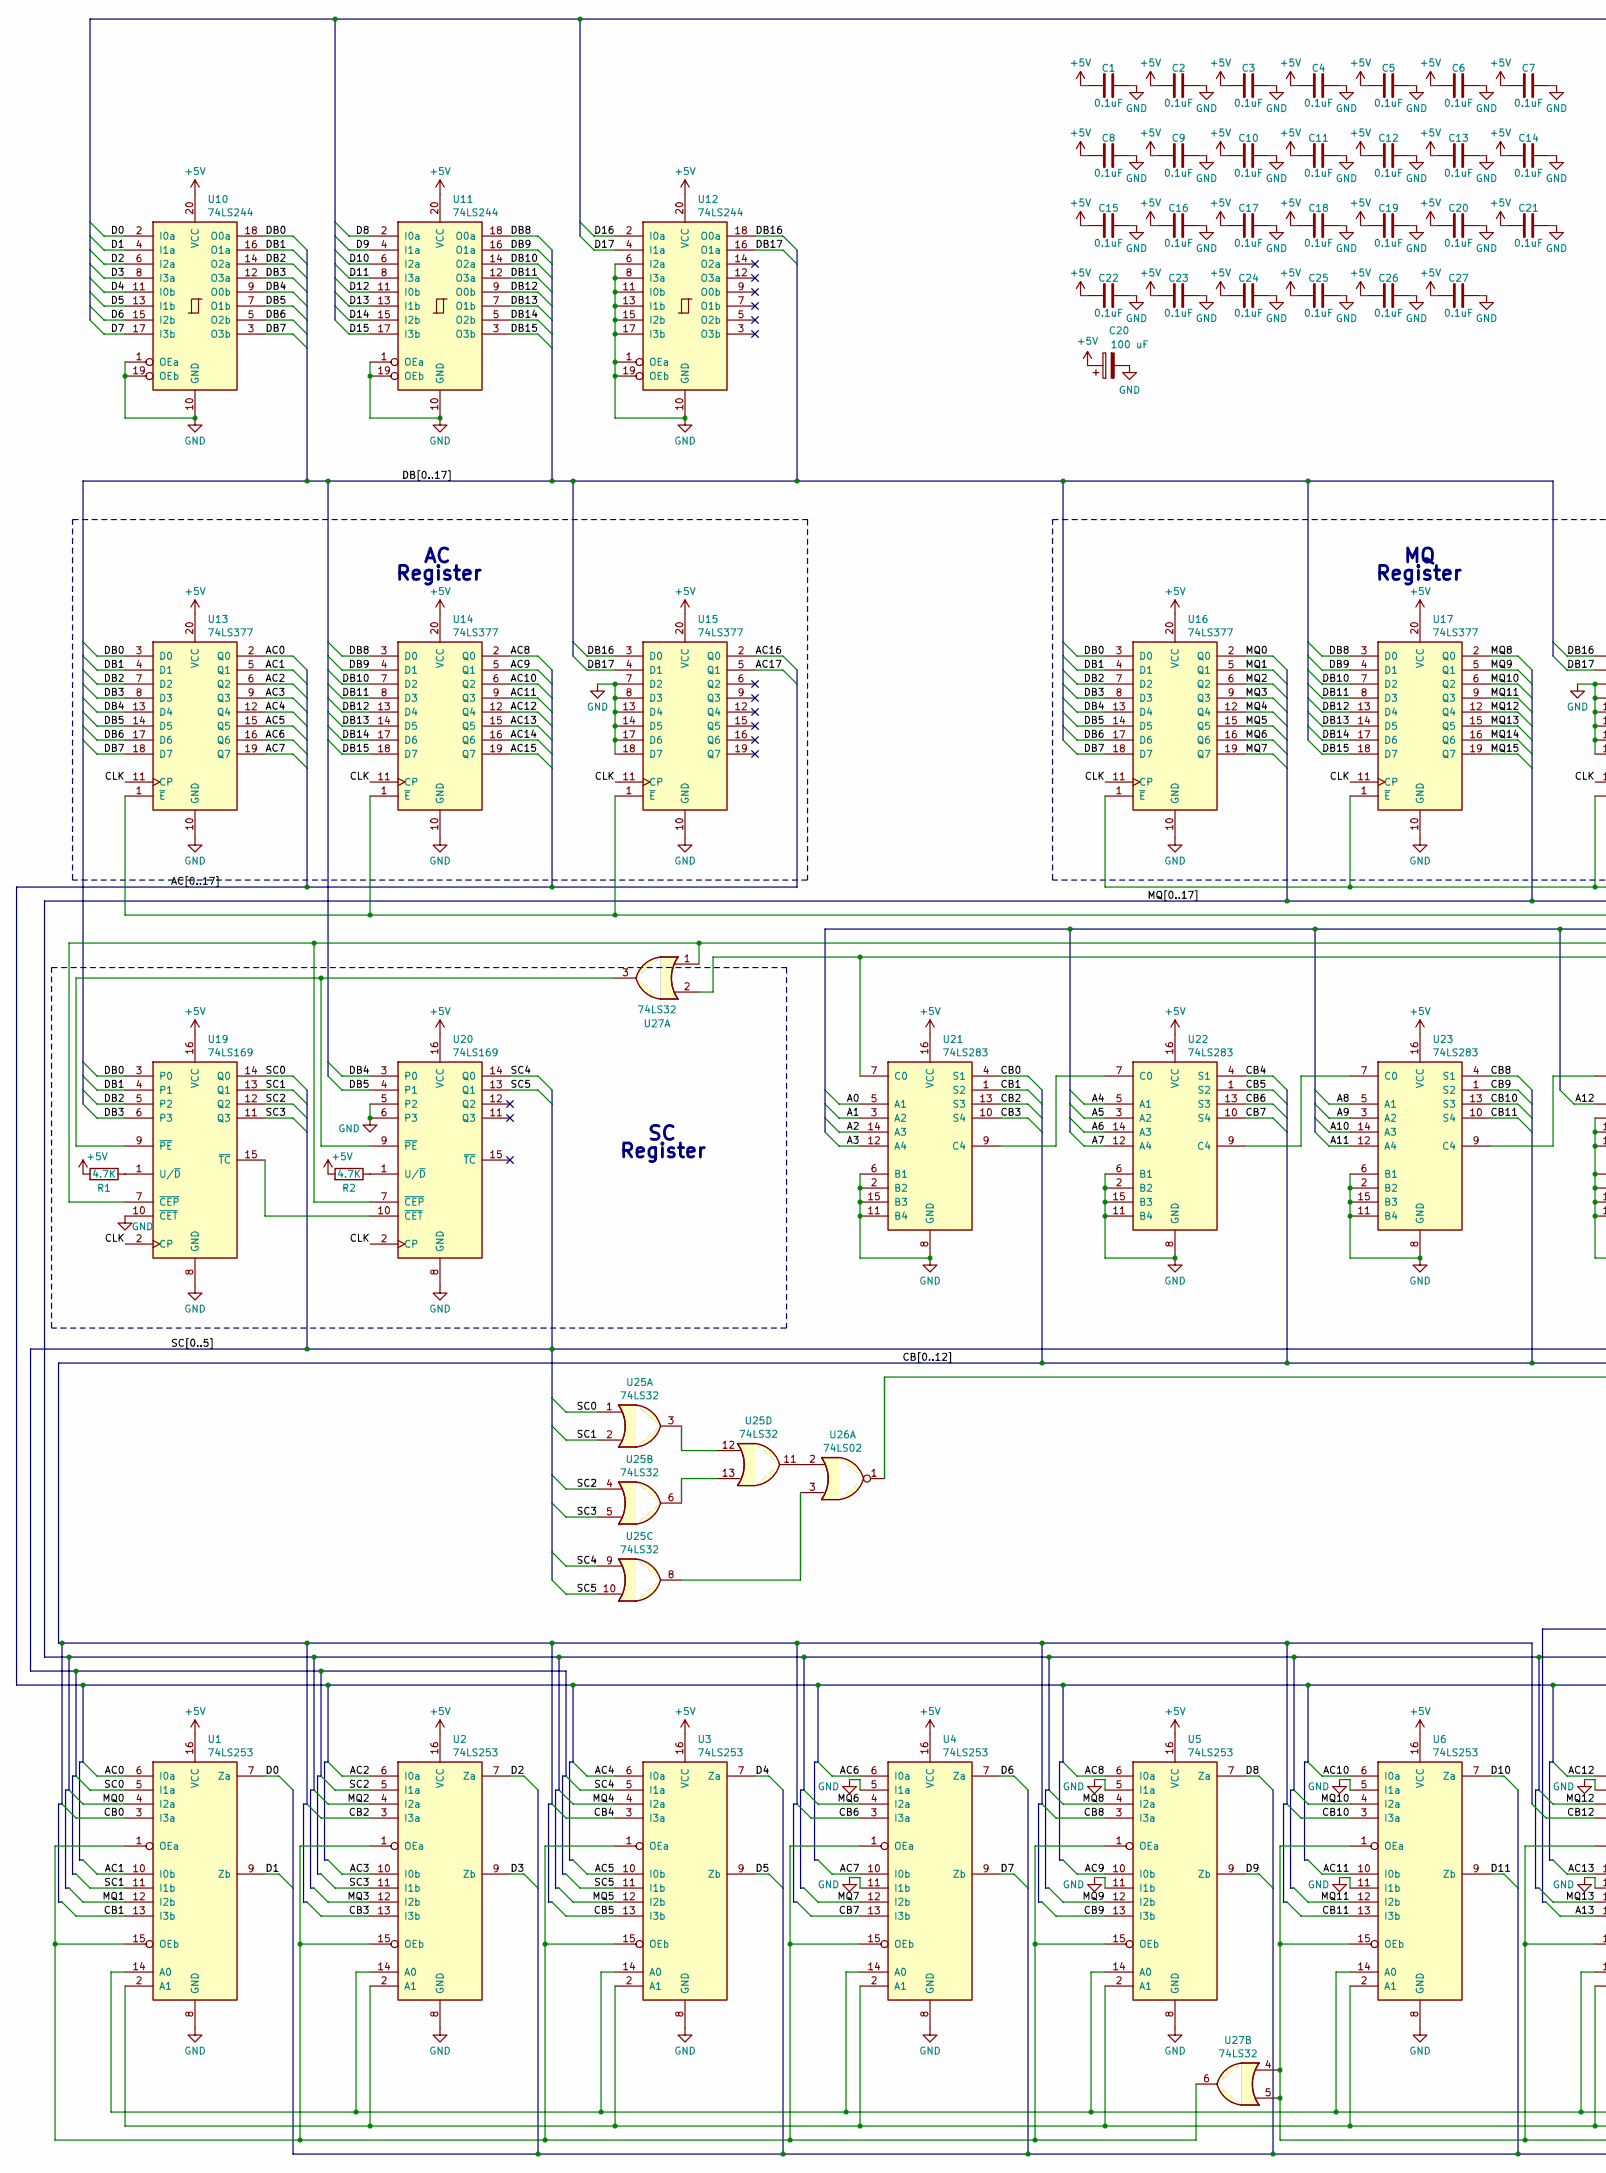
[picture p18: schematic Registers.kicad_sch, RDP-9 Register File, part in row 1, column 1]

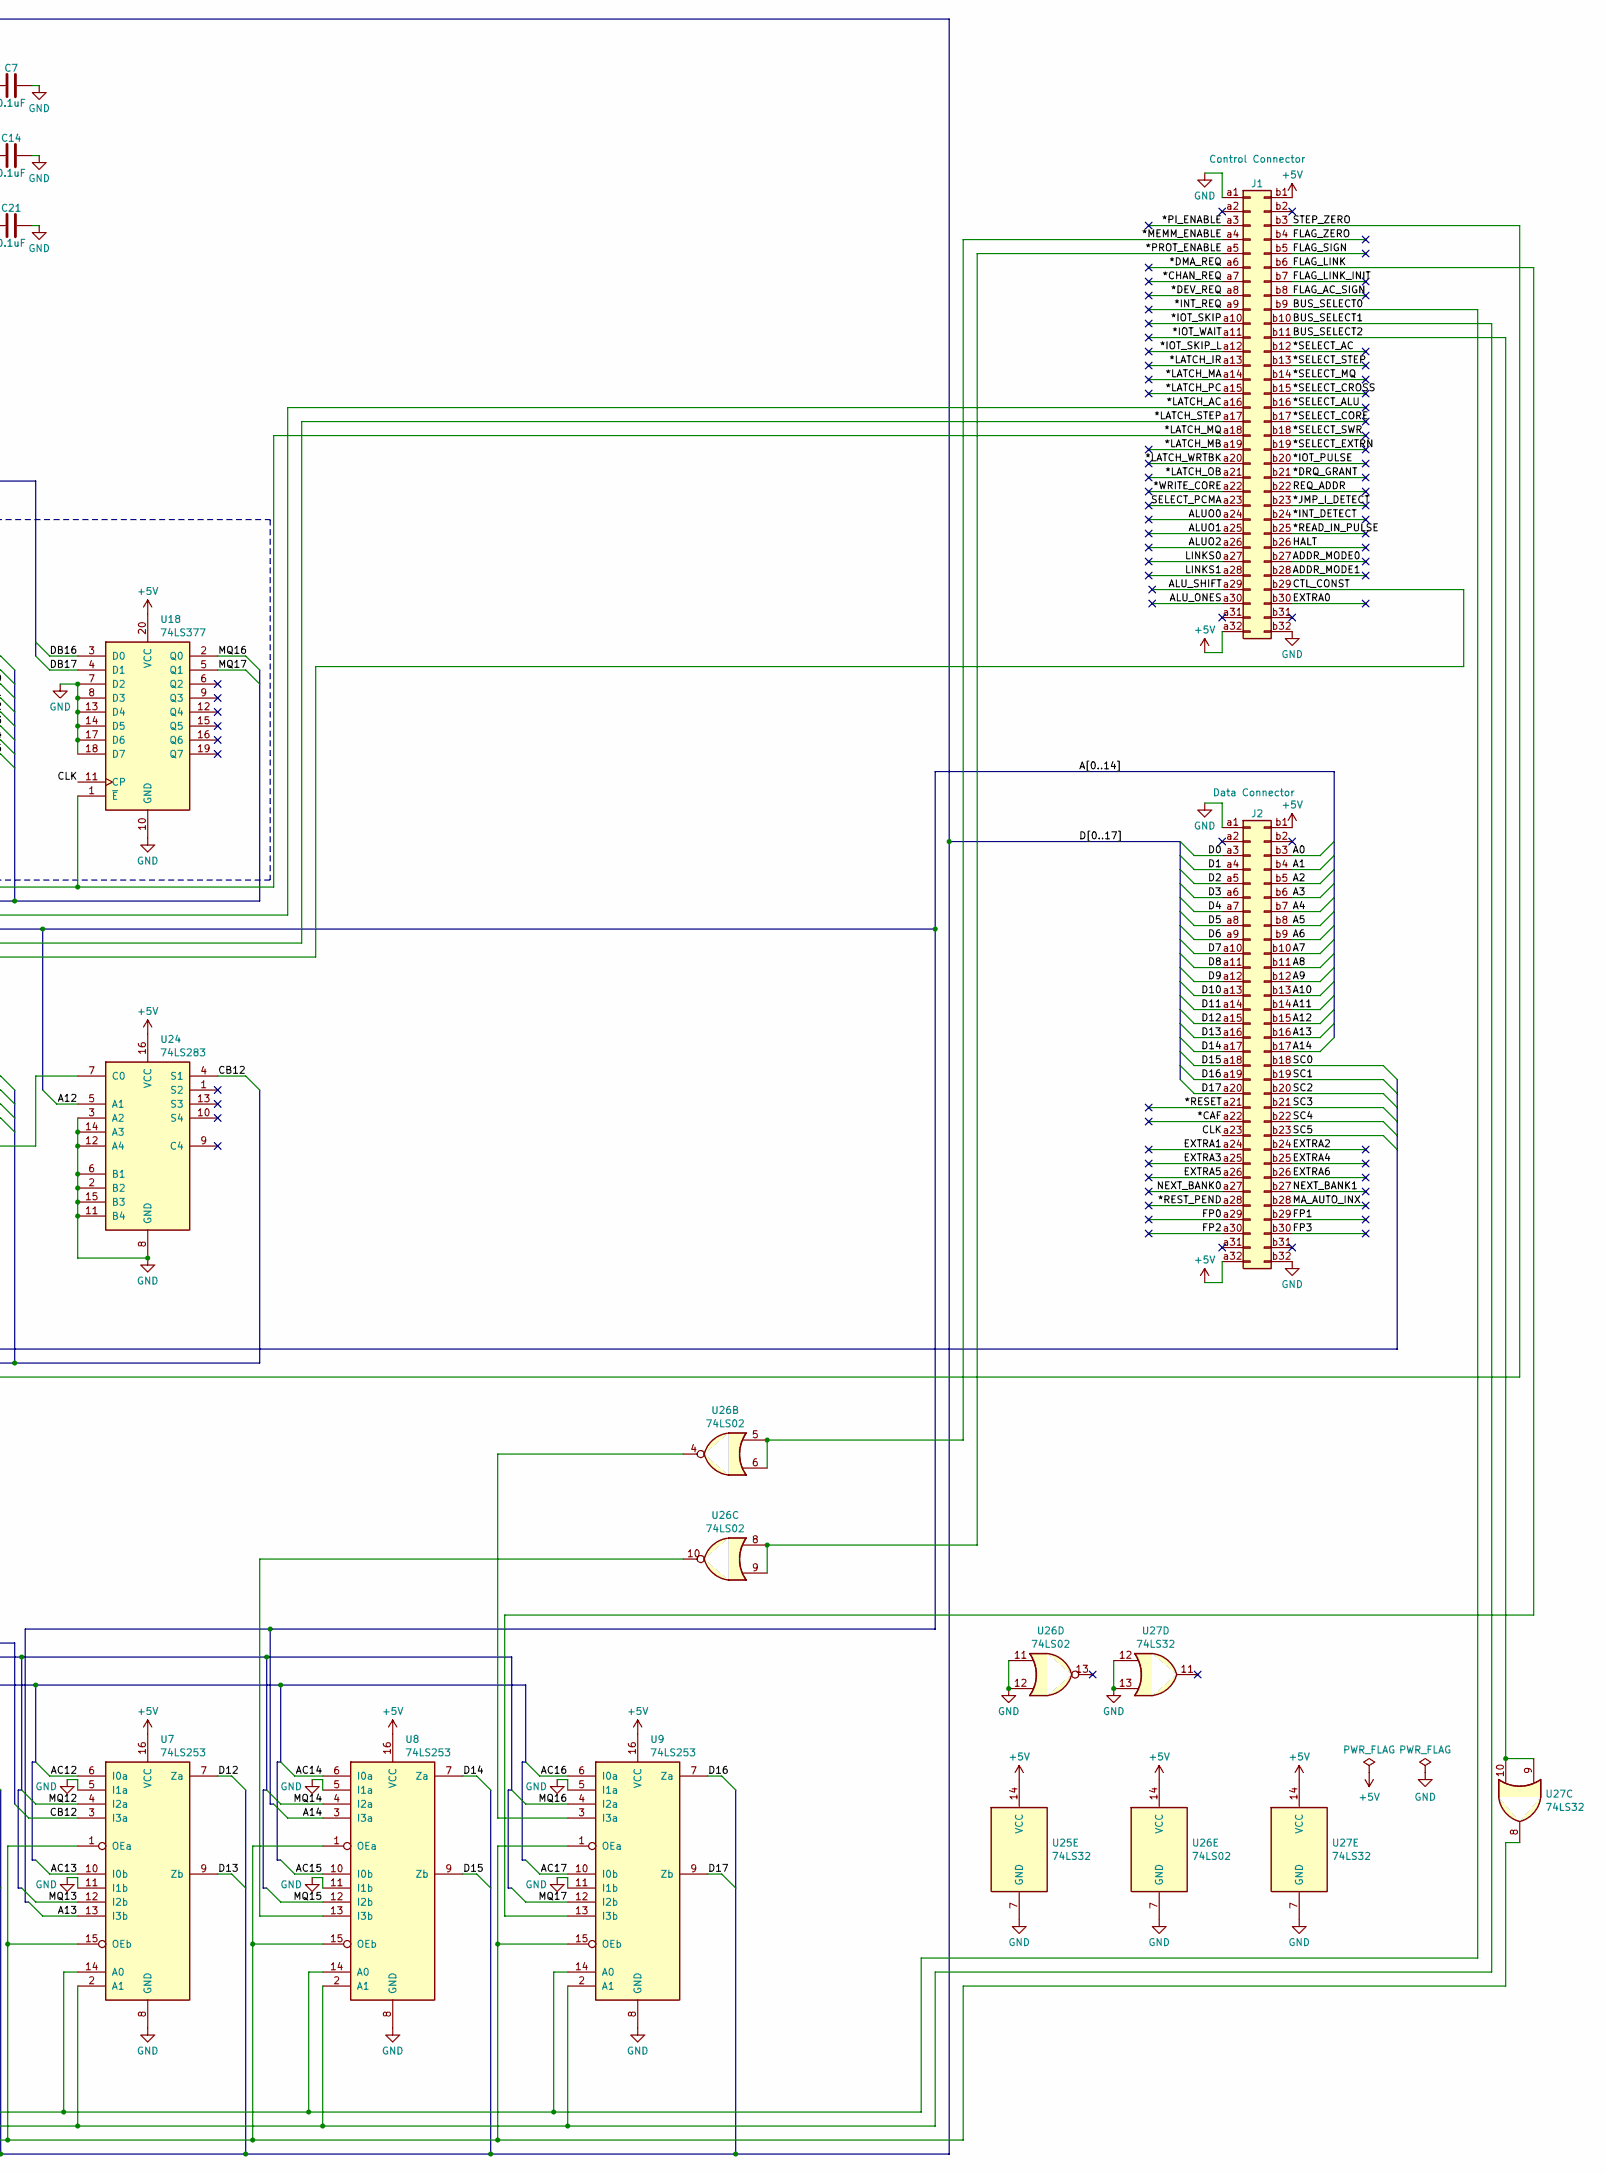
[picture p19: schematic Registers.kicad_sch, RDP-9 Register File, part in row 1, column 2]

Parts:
C1, C2, C3, C4, C5, C6, C7, C8, C9, C10, C11, C12, C13, C14, C15, C16, C17, C18, C19, C21, C22, C23, C24, C25, C26, C27: 0.1uF; C_Disc_D5.0mm_W2.5mm_P5.00mm
C20: 100 uF; CP_Radial_D6.3mm_P2.50mm
J1: Control Connector; DIN41612_B_2x32_Male_Horizontal_THT
J2: Data Connector; DIN41612_B_2x32_Male_Horizontal_THT
R1, R2: 4.7K; R_Axial_DIN0207_L6.3mm_D2.5mm_P7.62mm_Horizontal
U1, U2, U3, U4, U5, U6, U7, U8, U9: 74LS253; DIP-16_W7.62mm
U10, U11, U12: 74LS244; DIP-20_W7.62mm
U13, U14, U15, U16, U17, U18: 74LS377; DIP-20_W7.62mm
U19, U20: 74LS169; DIP-16_W7.62mm
U21, U22, U23, U24: 74LS283; DIP-16_W7.62mm
U25, U27: 74LS32; DIP-14_W7.62mm
U26: 74LS02; DIP-14_W7.62mm

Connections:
+5V: C1.1, C2.1, C3.1, C4.1, C5.1, C6.1, C7.1, C8.1, C9.1, C10.1, C11.1, C12.1, C13.1, C14.1, C15.1, C16.1, C17.1, C18.1, C19.1, C20.1, C21.1, C22.1, C23.1, C24.1, C25.1, C26.1, C27.1, J1.a32, J1.b1, J2.a32, J2.b1, R1.2, R2.2, U1.16 (VCC), U2.16 (VCC), U3.16 (VCC), U4.16 (VCC), U5.16 (VCC), U6.16 (VCC), U7.16 (VCC), U8.16 (VCC), U9.16 (VCC), U10.20 (VCC), U11.20 (VCC), U12.20 (VCC), U13.20 (VCC), U14.20 (VCC), U15.20 (VCC), U16.20 (VCC), U17.20 (VCC), U18.20 (VCC), U19.16 (VCC), U20.16 (VCC), U21.16 (VCC), U22.16 (VCC), U23.16 (VCC), U24.16 (VCC), U25.14 (VCC), U26.14 (VCC), U27.14 (VCC); also elsewhere on the board
/*CAF: J2.a22
/*CHAN_REQ: J1.a7
/*DEV_REQ: J1.a8
/*DMA_REQ: J1.a6
/*DRQ_GRANT: J1.b21
/*INT_DETECT: J1.b24
/*INT_REQ: J1.a9
/*IOT_PULSE: J1.b20
/*IOT_SKIP: J1.a10
/*IOT_SKIP_L: J1.a12
/*IOT_WAIT: J1.a11
/*JMP_I_DETECT: J1.b23
/*LATCH_AC: J1.a16, U13.1 (~E), U14.1 (~E), U15.1 (~E)
/*LATCH_IR: J1.a13
/*LATCH_MA: J1.a14
/*LATCH_MB: J1.a19
/*LATCH_MQ: J1.a18, U16.1 (~E), U17.1 (~E), U18.1 (~E)
/*LATCH_OB: J1.a21
/*LATCH_PC: J1.a15
/*LATCH_STEP: J1.a17, U19.7 (~CEP), U20.7 (~CEP), U27.1
/*LATCH_WRTBK: J1.a20
/*MEMM_ENABLE: J1.a4, U26.5, U26.6
/*PI_ENABLE: J1.a3
/*PROT_ENABLE: J1.a5, U26.8, U26.9
/*READ_IN_PULSE: J1.b25
/*RESET: J2.a21
/*REST_PEND: J2.a28
/*SELECT_AC: J1.b12
/*SELECT_ALU: J1.b16
/*SELECT_CORE: J1.b17
/*SELECT_CROSS: J1.b15
/*SELECT_EXTRN: J1.b19
/*SELECT_MQ: J1.b14
/*SELECT_STEP: J1.b13
/*SELECT_SWR: J1.b18
/*WRITE_CORE: J1.a22
/A0: J2.b3, U21.5 (A1)
/A1: J2.b4, U21.3 (A2)
/A2: J2.b5, U21.14 (A3)
/A3: J2.b6, U21.12 (A4)
/A4: J2.b7, U22.5 (A1)
/A5: J2.b8, U22.3 (A2)
/A6: J2.b9, U22.14 (A3)
/A7: J2.b10, U22.12 (A4)
/A8: J2.b11, U23.5 (A1)
/A9: J2.b12, U23.3 (A2)
/A10: J2.b13, U23.14 (A3)
/A11: J2.b14, U23.12 (A4)
/A12: J2.b15, U24.5 (A1)
/A13: J2.b16, U7.13 (I3b)
/A14: J2.b17, U8.3 (I3a)
/AC0: U1.6 (I0a), U13.2 (Q0)
/AC1: U1.10 (I0b), U13.5 (Q1)
/AC2: U2.6 (I0a), U13.6 (Q2)
/AC3: U2.10 (I0b), U13.9 (Q3)
/AC4: U3.6 (I0a), U13.12 (Q4)
/AC5: U3.10 (I0b), U13.15 (Q5)
/AC6: U4.6 (I0a), U13.16 (Q6)
/AC7: U4.10 (I0b), U13.19 (Q7)
/AC8: U5.6 (I0a), U14.2 (Q0)
/AC9: U5.10 (I0b), U14.5 (Q1)
/AC10: U6.6 (I0a), U14.6 (Q2)
/AC11: U6.10 (I0b), U14.9 (Q3)
/AC12: U7.6 (I0a), U14.12 (Q4)
/AC13: U7.10 (I0b), U14.15 (Q5)
/AC14: U8.6 (I0a), U14.16 (Q6)
/AC15: U8.10 (I0b), U14.19 (Q7)
/AC16: U9.6 (I0a), U15.2 (Q0)
/AC17: U9.10 (I0b), U15.5 (Q1)
/ADDR_MODE0: J1.b27
/ADDR_MODE1: J1.b28
/ALUO0: J1.a24
/ALUO1: J1.a25
/ALUO2: J1.a26
/ALU_ONES: J1.a30
/ALU_SHIFT: J1.a29
/BUS_SELECT0: J1.b9, U1.14 (A0), U2.14 (A0), U3.14 (A0), U4.14 (A0), U5.14 (A0), U6.14 (A0), U7.14 (A0), U8.14 (A0), U9.14 (A0)
/BUS_SELECT1: J1.b10, U1.2 (A1), U2.2 (A1), U3.2 (A1), U4.2 (A1), U5.2 (A1), U6.2 (A1), U7.2 (A1), U8.2 (A1), U9.2 (A1)
/BUS_SELECT2: J1.b11, U27.9, U27.10
/CB0: U1.3 (I3a), U21.4 (S1)
/CB1: U1.13 (I3b), U21.1 (S2)
/CB2: U2.3 (I3a), U21.13 (S3)
/CB3: U2.13 (I3b), U21.10 (S4)
/CB4: U3.3 (I3a), U22.4 (S1)
/CB5: U3.13 (I3b), U22.1 (S2)
/CB6: U4.3 (I3a), U22.13 (S3)
/CB7: U4.13 (I3b), U22.10 (S4)
/CB8: U5.3 (I3a), U23.4 (S1)
/CB9: U5.13 (I3b), U23.1 (S2)
/CB10: U6.3 (I3a), U23.13 (S3)
/CB11: U6.13 (I3b), U23.10 (S4)
/CB12: U7.3 (I3a), U24.4 (S1)
/CLK: J2.a23, U13.11 (CP), U14.11 (CP), U15.11 (CP), U16.11 (CP), U17.11 (CP), U18.11 (CP), U19.2 (CP), U20.2 (CP)
/CTL_CONST: J1.b29, U21.7 (C0), U27.2
/D0: J2.a3, U1.7 (Za), U10.2 (I0a)
/D1: J2.a4, U1.9 (Zb), U10.4 (I1a)
/D2: J2.a5, U2.7 (Za), U10.6 (I2a)
/D3: J2.a6, U2.9 (Zb), U10.8 (I3a)
/D4: J2.a7, U3.7 (Za), U10.11 (I0b)
/D5: J2.a8, U3.9 (Zb), U10.13 (I1b)
/D6: J2.a9, U4.7 (Za), U10.15 (I2b)
/D7: J2.a10, U4.9 (Zb), U10.17 (I3b)
/D8: J2.a11, U5.7 (Za), U11.2 (I0a)
/D9: J2.a12, U5.9 (Zb), U11.4 (I1a)
/D10: J2.a13, U6.7 (Za), U11.6 (I2a)
/D11: J2.a14, U6.9 (Zb), U11.8 (I3a)
/D12: J2.a15, U7.7 (Za), U11.11 (I0b)
/D13: J2.a16, U7.9 (Zb), U11.13 (I1b)
/D14: J2.a17, U8.7 (Za), U11.15 (I2b)
/D15: J2.a18, U8.9 (Zb), U11.17 (I3b)
/D16: J2.a19, U9.7 (Za), U12.2 (I0a)
/D17: J2.a20, U9.9 (Zb), U12.4 (I1a)
/DB0: U10.18 (O0a), U13.3 (D0), U16.3 (D0), U19.3 (P0)
/DB1: U10.16 (O1a), U13.4 (D1), U16.4 (D1), U19.4 (P1)
/DB2: U10.14 (O2a), U13.7 (D2), U16.7 (D2), U19.5 (P2)
/DB3: U10.12 (O3a), U13.8 (D3), U16.8 (D3), U19.6 (P3)
/DB4: U10.9 (O0b), U13.13 (D4), U16.13 (D4), U20.3 (P0)
/DB5: U10.7 (O1b), U13.14 (D5), U16.14 (D5), U20.4 (P1)
/DB6: U10.5 (O2b), U13.17 (D6), U16.17 (D6)
/DB7: U10.3 (O3b), U13.18 (D7), U16.18 (D7)
/DB8: U11.18 (O0a), U14.3 (D0), U17.3 (D0)
/DB9: U11.16 (O1a), U14.4 (D1), U17.4 (D1)
/DB10: U11.14 (O2a), U14.7 (D2), U17.7 (D2)
/DB11: U11.12 (O3a), U14.8 (D3), U17.8 (D3)
/DB12: U11.9 (O0b), U14.13 (D4), U17.13 (D4)
/DB13: U11.7 (O1b), U14.14 (D5), U17.14 (D5)
/DB14: U11.5 (O2b), U14.17 (D6), U17.17 (D6)
/DB15: U11.3 (O3b), U14.18 (D7), U17.18 (D7)
/DB16: U12.18 (O0a), U15.3 (D0), U18.3 (D0)
/DB17: U12.16 (O1a), U15.4 (D1), U18.4 (D1)
/EXTRA0: J1.b30
/EXTRA1: J2.a24
/EXTRA2: J2.b24
/EXTRA3: J2.a25
/EXTRA4: J2.b25
/EXTRA5: J2.a26
/EXTRA6: J2.b26
/FLAG_AC_SIGN: J1.b8
/FLAG_LINK: J1.b6, U9.13 (I3b)
/FLAG_LINK_INIT: J1.b7
/FLAG_SIGN: J1.b5
/FLAG_ZERO: J1.b4
/FP0: J2.a29
/FP1: J2.b29
/FP2: J2.a30
/FP3: J2.b30
/HALT: J1.b26
/LINKS0: J1.a27
/LINKS1: J1.a28
/MA_AUTO_INX: J2.b28
/MQ0: U1.4 (I2a), U16.2 (Q0)
/MQ1: U1.12 (I2b), U16.5 (Q1)
/MQ2: U2.4 (I2a), U16.6 (Q2)
/MQ3: U2.12 (I2b), U16.9 (Q3)
/MQ4: U3.4 (I2a), U16.12 (Q4)
/MQ5: U3.12 (I2b), U16.15 (Q5)
/MQ6: U4.4 (I2a), U16.16 (Q6)
/MQ7: U4.12 (I2b), U16.19 (Q7)
/MQ8: U5.4 (I2a), U17.2 (Q0)
/MQ9: U5.12 (I2b), U17.5 (Q1)
/MQ10: U6.4 (I2a), U17.6 (Q2)
/MQ11: U6.12 (I2b), U17.9 (Q3)
/MQ12: U7.4 (I2a), U17.12 (Q4)
/MQ13: U7.12 (I2b), U17.15 (Q5)
/MQ14: U8.4 (I2a), U17.16 (Q6)
/MQ15: U8.12 (I2b), U17.19 (Q7)
/MQ16: U9.4 (I2a), U18.2 (Q0)
/MQ17: U9.12 (I2b), U18.5 (Q1)
/NEXT_BANK0: J2.a27
/NEXT_BANK1: J2.b27
/REQ_ADDR: J1.b22
/SC0: J2.b18, U1.5 (I1a), U19.14 (Q0), U25.1
/SC1: J2.b19, U1.11 (I1b), U19.13 (Q1), U25.2
/SC2: J2.b20, U2.5 (I1a), U19.12 (Q2), U25.4
/SC3: J2.b21, U2.11 (I1b), U19.11 (Q3), U25.5
/SC4: J2.b22, U3.5 (I1a), U20.14 (Q0), U25.9
/SC5: J2.b23, U3.11 (I1b), U20.13 (Q1), U25.10
/SELECT_PCMA: J1.a23
/STEP_ZERO: J1.b3, U26.1
GND: C1.2, C2.2, C3.2, C4.2, C5.2, C6.2, C7.2, C8.2, C9.2, C10.2, C11.2, C12.2, C13.2, C14.2, C15.2, C16.2, C17.2, C18.2, C19.2, C20.2, C21.2, C22.2, C23.2, C24.2, C25.2, C26.2, C27.2, J1.a1, J1.b32, J2.a1, J2.b32, U1.8 (GND), U2.8 (GND), U3.8 (GND), U4.5 (I1a), U4.8 (GND), U4.11 (I1b), U5.5 (I1a), U5.8 (GND), U5.11 (I1b), U6.5 (I1a), U6.8 (GND), U6.11 (I1b), U7.5 (I1a), U7.8 (GND), U7.11 (I1b), U8.5 (I1a), U8.8 (GND), U8.11 (I1b), U9.5 (I1a), U9.8 (GND), U9.11 (I1b), U10.1 (OEa), U10.10 (GND), U10.19 (OEb), U11.1 (OEa), U11.10 (GND), U11.19 (OEb), U12.1 (OEa), U12.6 (I2a), U12.8 (I3a), U12.10 (GND), U12.11 (I0b), U12.13 (I1b), U12.15 (I2b), U12.17 (I3b), U12.19 (OEb), U13.10 (GND), U14.10 (GND), U15.7 (D2), U15.8 (D3), U15.10 (GND), U15.13 (D4), U15.14 (D5), U15.17 (D6), U15.18 (D7), U16.10 (GND), U17.10 (GND), U18.7 (D2), U18.8 (D3), U18.10 (GND), U18.13 (D4), U18.14 (D5), U18.17 (D6), U18.18 (D7), U19.8 (GND), U19.10 (~CET), U20.5 (P2), U20.6 (P3), U20.8 (GND), U21.2 (B2), U21.6 (B1), U21.8 (GND), U21.11 (B4), U21.15 (B3), U22.2 (B2), U22.6 (B1), U22.8 (GND), U22.11 (B4), U22.15 (B3), U23.2 (B2), U23.6 (B1), U23.8 (GND), U23.11 (B4), U23.15 (B3), U24.2 (B2), U24.3 (A2), U24.6 (B1), U24.8 (GND), U24.11 (B4), U24.12 (A4), U24.14 (A3), U24.15 (B3), U25.7 (GND), U26.7 (GND), U26.11, U26.12, U27.7 (GND), U27.12, U27.13; also elsewhere on the board
unnamed: U1.1 (OEa), U1.15 (OEb), U2.1 (OEa), U2.15 (OEb), U3.1 (OEa), U3.15 (OEb), U4.1 (OEa), U4.15 (OEb), U5.1 (OEa), U5.15 (OEb), U27.6
unnamed: U6.1 (OEa), U6.15 (OEb), U7.1 (OEa), U7.15 (OEb), U8.1 (OEa), U8.15 (OEb), U9.1 (OEa), U9.15 (OEb), U27.4, U27.5, U27.8
unnamed: U8.13 (I3b), U26.10
unnamed: U9.3 (I3a), U26.4
unnamed: R1.1, U19.1 (U/~D)
unnamed: U19.9 (~PE), U20.9 (~PE), U27.3
unnamed: U19.15 (~TC), U20.10 (~CET)
unnamed: R2.1, U20.1 (U/~D)
unnamed: U21.9 (C4), U22.7 (C0)
unnamed: U22.9 (C4), U23.7 (C0)
unnamed: U23.9 (C4), U24.7 (C0)
unnamed: U25.8, U26.3
unnamed: U25.11, U26.2
unnamed: U25.3, U25.12
unnamed: U25.6, U25.13

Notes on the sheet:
Register

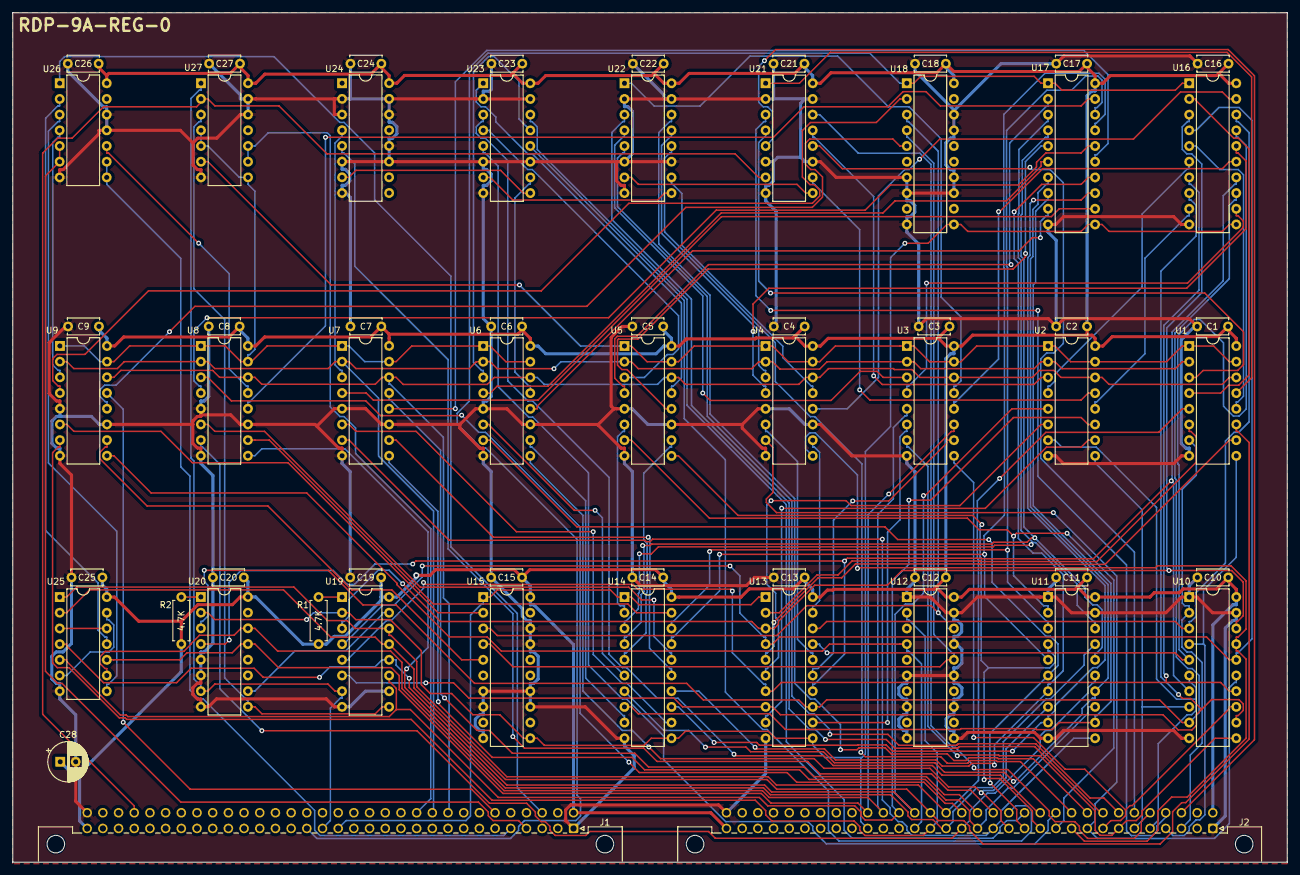
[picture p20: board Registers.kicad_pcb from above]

Board: 2 copper layers, 206.4 x 137.5 mm, 59 parts (0 on the bottom side), 135 nets.

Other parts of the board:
C28: 100 uF; CP_Radial_D6.3mm_P2.50mm

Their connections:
+5V: C28.1; also elsewhere on the board
GND: C28.2; also elsewhere on the board

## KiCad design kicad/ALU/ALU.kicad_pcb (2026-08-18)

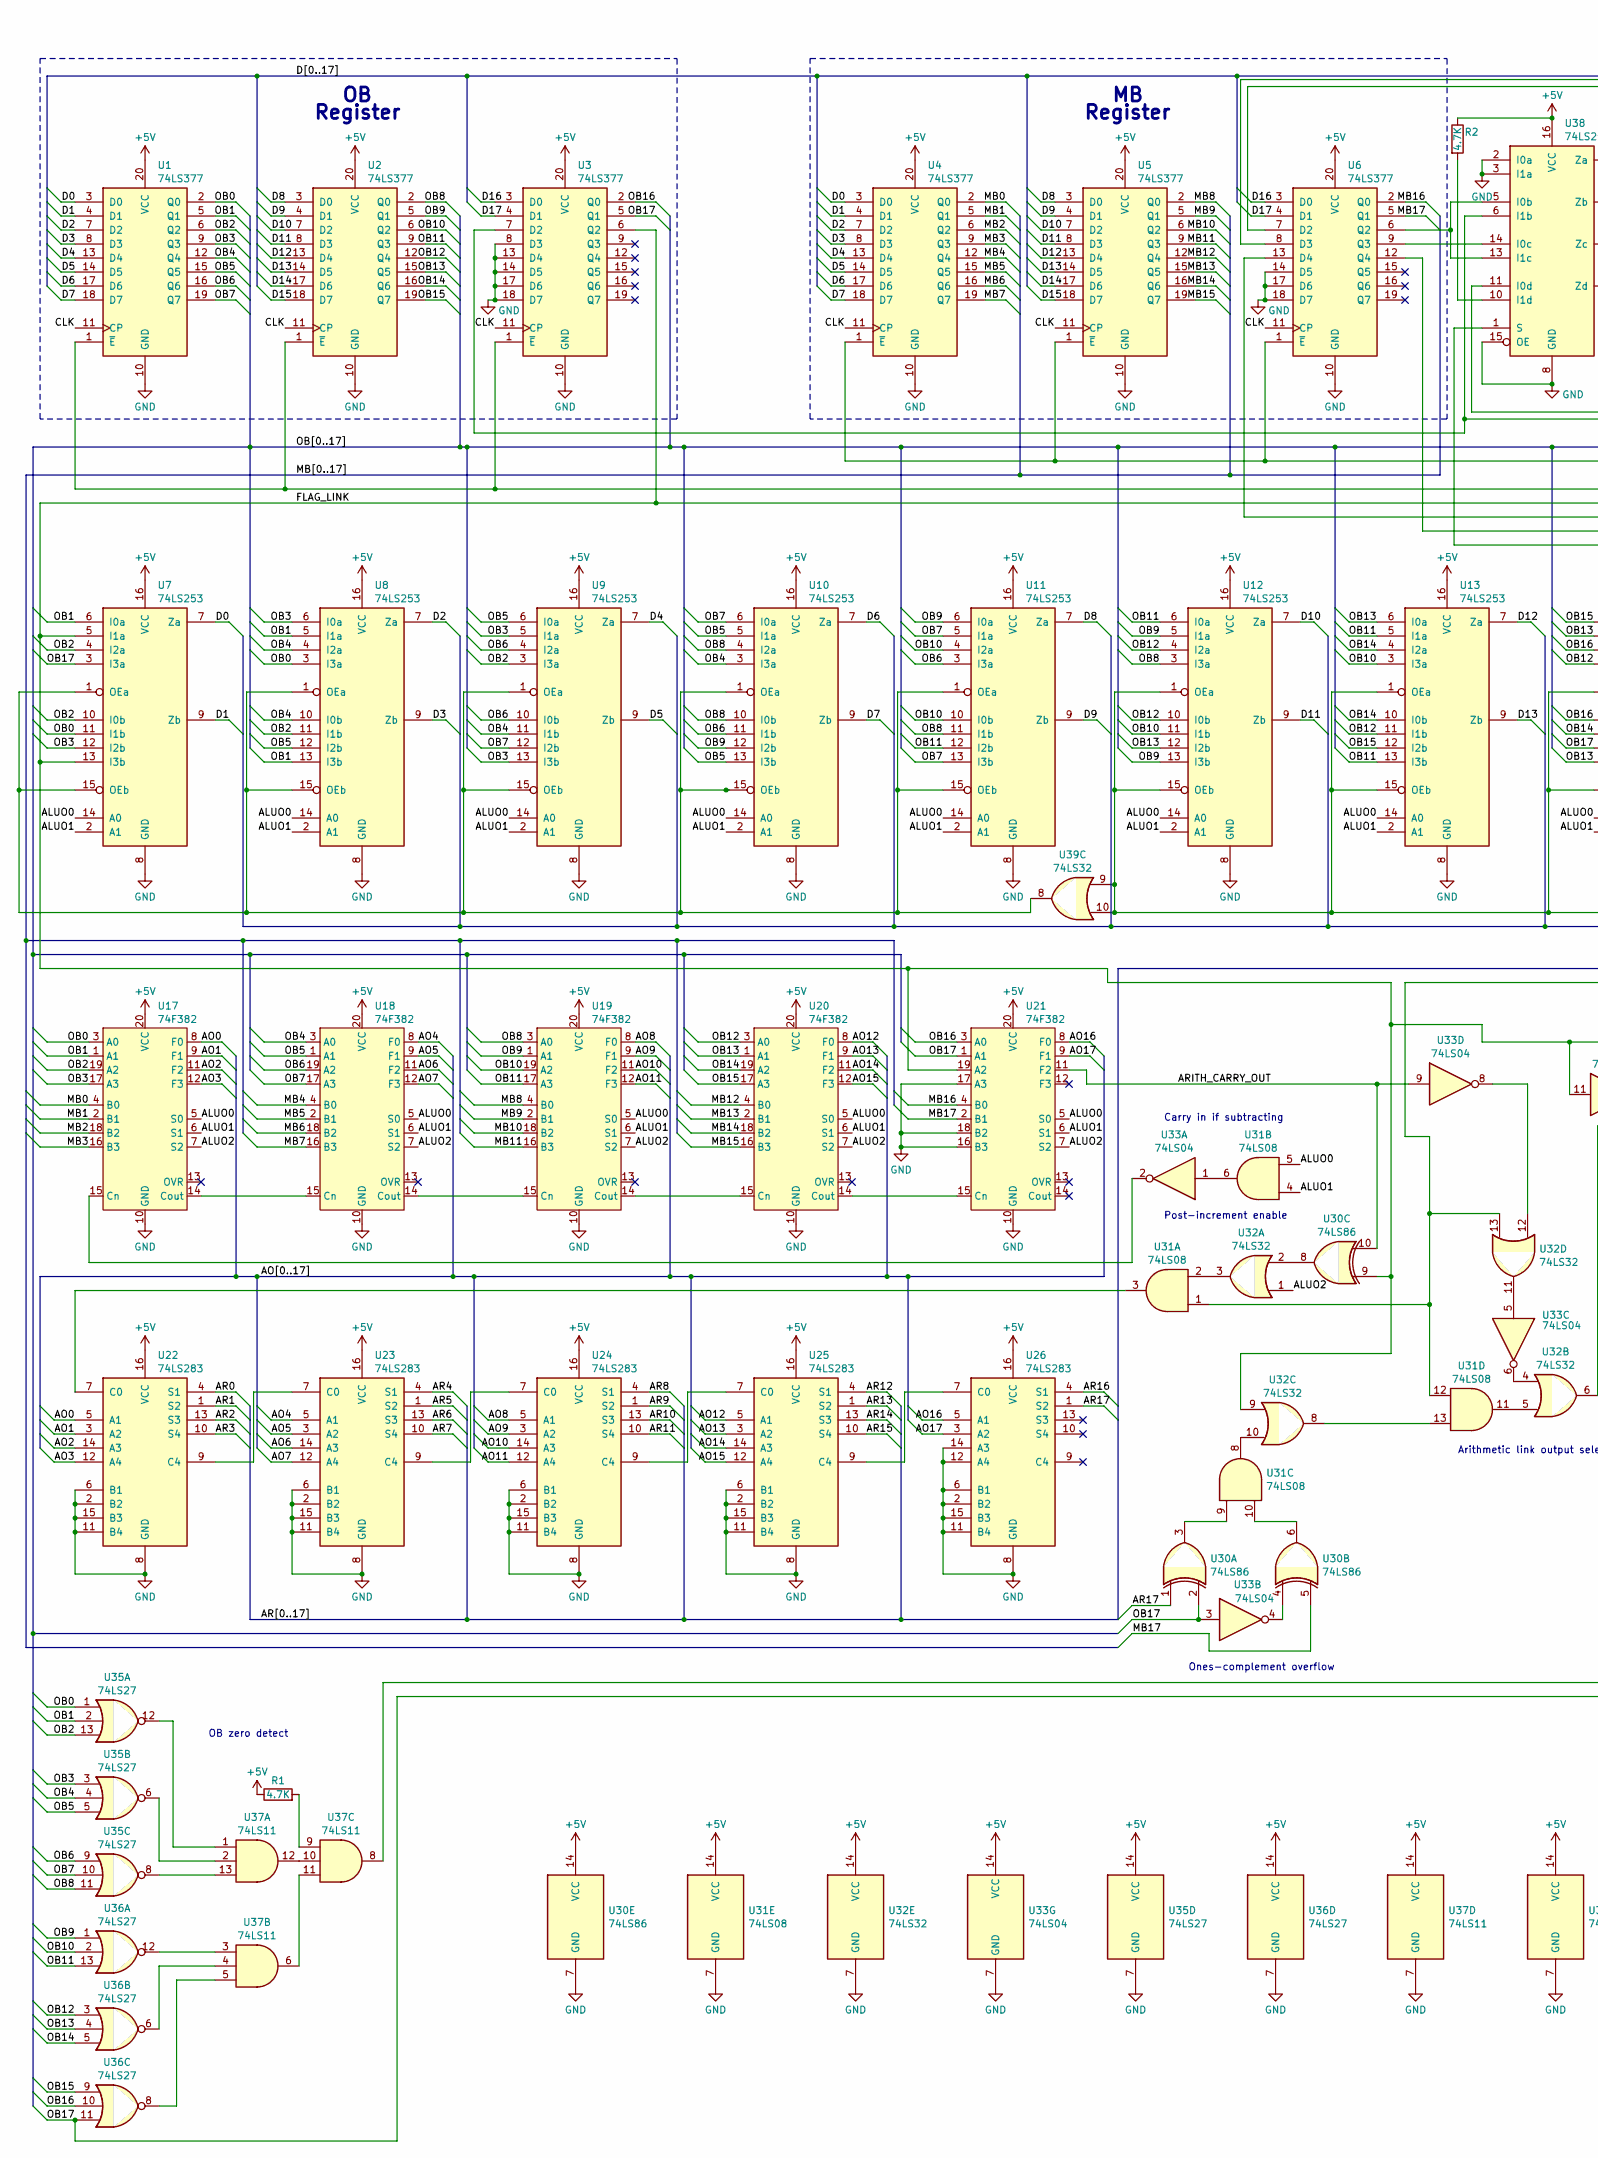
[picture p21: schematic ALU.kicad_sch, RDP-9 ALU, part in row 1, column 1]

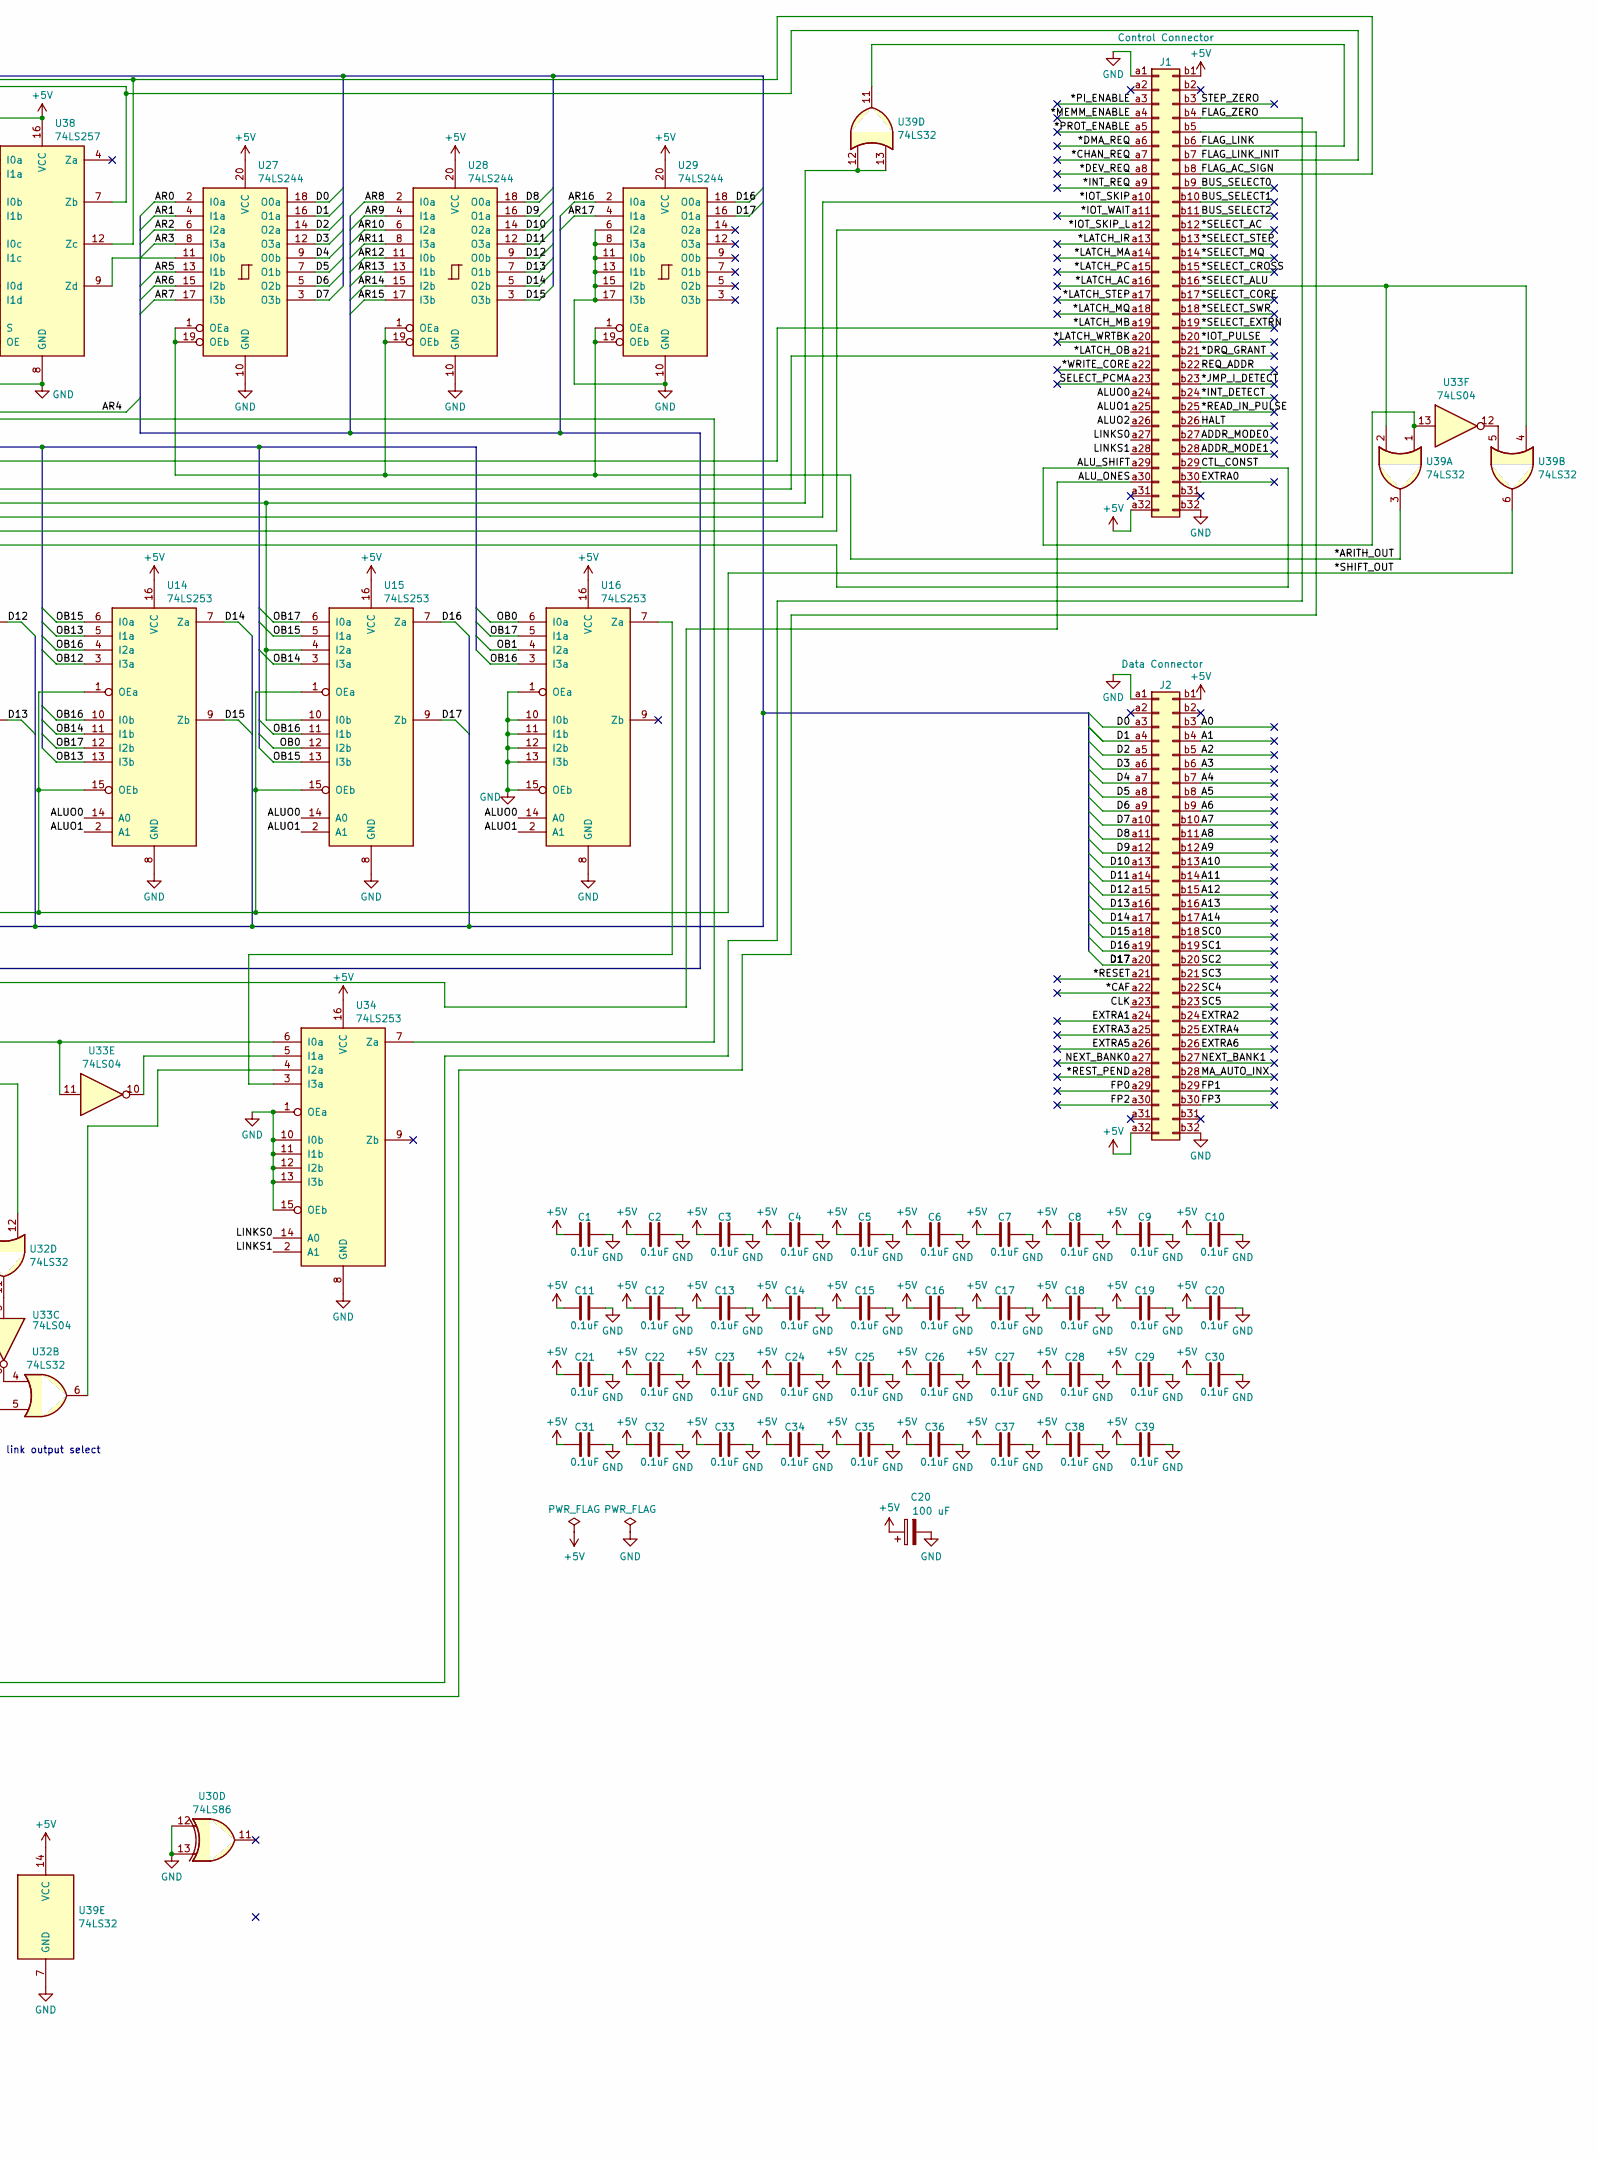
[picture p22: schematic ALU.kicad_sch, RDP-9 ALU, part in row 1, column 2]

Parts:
C1, C2, C3, C4, C5, C6, C7, C8, C9, C10, C11, C12, C13, C14, C15, C16, C17, C18, C19, C21, C22, C23, C24, C25, C26, C27, C28, C29, C30, C31, C32, C33, C34, C35, C36, C37, C38, C39: 0.1uF; C_Disc_D5.0mm_W2.5mm_P5.00mm
C20: 100 uF; CP_Radial_D6.3mm_P2.50mm
J1: Control Connector; DIN41612_B_2x32_Male_Horizontal_THT
J2: Data Connector; DIN41612_B_2x32_Male_Horizontal_THT
R1, R2: 4.7K; R_Axial_DIN0207_L6.3mm_D2.5mm_P7.62mm_Horizontal
U1, U2, U3, U4, U5, U6: 74LS377; DIP-20_W7.62mm
U7, U8, U9, U10, U11, U12, U13, U14, U15, U16, U34: 74LS253; DIP-16_W7.62mm
U17, U18, U19, U20, U21: 74F382; DIP-20_W7.62mm
U22, U23, U24, U25, U26: 74LS283; DIP-16_W7.62mm
U27, U28, U29: 74LS244; DIP-20_W7.62mm
U30: 74LS86; DIP-14_W7.62mm
U31: 74LS08; DIP-14_W7.62mm
U32, U39: 74LS32; DIP-14_W7.62mm
U33: 74LS04; DIP-14_W7.62mm
U35, U36: 74LS27; DIP-14_W7.62mm
U37: 74LS11; DIP-14_W7.62mm
U38: 74LS257; DIP-16_W7.62mm

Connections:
+5V: C1.1, C2.1, C3.1, C4.1, C5.1, C6.1, C7.1, C8.1, C9.1, C10.1, C11.1, C12.1, C13.1, C14.1, C15.1, C16.1, C17.1, C18.1, C19.1, C20.1, C21.1, C22.1, C23.1, C24.1, C25.1, C26.1, C27.1, C28.1, C29.1, C30.1, C31.1, C32.1, C33.1, C34.1, C35.1, C36.1, C37.1, C38.1, C39.1, J1.a32, J1.b1, J2.a32, J2.b1, R1.1, R2.1, U1.20 (VCC), U2.20 (VCC), U3.20 (VCC), U4.20 (VCC), U5.20 (VCC), U6.20 (VCC), U7.16 (VCC), U8.16 (VCC), U9.16 (VCC), U10.16 (VCC), U11.16 (VCC), U12.16 (VCC), U13.16 (VCC), U14.16 (VCC), U15.16 (VCC), U16.16 (VCC), U17.20 (VCC), U18.20 (VCC), U19.20 (VCC), U20.20 (VCC), U21.20 (VCC), U22.16 (VCC), U23.16 (VCC), U24.16 (VCC), U25.16 (VCC), U26.16 (VCC), U27.20 (VCC), U28.20 (VCC), U29.20 (VCC), U30.14 (VCC), U31.14 (VCC), U32.14 (VCC), U33.14 (VCC), U34.16 (VCC), U35.14 (VCC), U36.14 (VCC), U37.14 (VCC), U38.16 (VCC), U39.14 (VCC); also elsewhere on the board
/*ARITH_OUT: U27.1 (OEa), U27.19 (OEb), U28.1 (OEa), U28.19 (OEb), U29.1 (OEa), U29.19 (OEb), U39.3
/*CAF: J2.a22
/*CHAN_REQ: J1.a7
/*DEV_REQ: J1.a8
/*DMA_REQ: J1.a6
/*DRQ_GRANT: J1.b21
/*INT_DETECT: J1.b24
/*INT_REQ: J1.a9
/*IOT_PULSE: J1.b20
/*IOT_SKIP: J1.a10, U6.13 (D4)
/*IOT_SKIP_L: J1.a12, U6.12 (Q4)
/*IOT_WAIT: J1.a11
/*JMP_I_DETECT: J1.b23
/*LATCH_AC: J1.a16
/*LATCH_IR: J1.a13
/*LATCH_MA: J1.a14
/*LATCH_MB: J1.a19, U4.1 (~E), U5.1 (~E), U6.1 (~E)
/*LATCH_MQ: J1.a18
/*LATCH_OB: J1.a21, U1.1 (~E), U2.1 (~E), U3.1 (~E)
/*LATCH_PC: J1.a15
/*LATCH_STEP: J1.a17
/*LATCH_WRTBK: J1.a20
/*MEMM_ENABLE: J1.a4
/*PI_ENABLE: J1.a3
/*PROT_ENABLE: J1.a5
/*READ_IN_PULSE: J1.b25
/*RESET: J2.a21
/*REST_PEND: J2.a28
/*SELECT_AC: J1.b12
/*SELECT_ALU: J1.b16, U39.2, U39.4
/*SELECT_CORE: J1.b17
/*SELECT_CROSS: J1.b15
/*SELECT_EXTRN: J1.b19
/*SELECT_MQ: J1.b14
/*SELECT_STEP: J1.b13
/*SELECT_SWR: J1.b18
/*SHIFT_OUT: U12.1 (OEa), U12.15 (OEb), U13.1 (OEa), U13.15 (OEb), U14.1 (OEa), U14.15 (OEb), U15.1 (OEa), U15.15 (OEb), U39.6, U39.9, U39.10
/*WRITE_CORE: J1.a22
/A0: J2.b3
/A1: J2.b4
/A2: J2.b5
/A3: J2.b6
/A4: J2.b7
/A5: J2.b8
/A6: J2.b9
/A7: J2.b10
/A8: J2.b11
/A9: J2.b12
/A10: J2.b13
/A11: J2.b14
/A12: J2.b15
/A13: J2.b16
/A14: J2.b17
/ADDR_MODE0: J1.b27
/ADDR_MODE1: J1.b28
/ALUO0: J1.a24, U7.14 (A0), U8.14 (A0), U9.14 (A0), U10.14 (A0), U11.14 (A0), U12.14 (A0), U13.14 (A0), U14.14 (A0), U15.14 (A0), U16.14 (A0), U17.5 (S0), U18.5 (S0), U19.5 (S0), U20.5 (S0), U21.5 (S0), U31.5
/ALUO1: J1.a25, U7.2 (A1), U8.2 (A1), U9.2 (A1), U10.2 (A1), U11.2 (A1), U12.2 (A1), U13.2 (A1), U14.2 (A1), U15.2 (A1), U16.2 (A1), U17.6 (S1), U18.6 (S1), U19.6 (S1), U20.6 (S1), U21.6 (S1), U31.4
/ALUO2: J1.a26, U17.7 (S2), U18.7 (S2), U19.7 (S2), U20.7 (S2), U21.7 (S2), U32.1
/ALU_ONES: J1.a30, U31.1, U31.12, U32.13
/ALU_SHIFT: J1.a29, U33.13, U39.1
/AO0: U17.8 (F0), U22.5 (A1)
/AO1: U17.9 (F1), U22.3 (A2)
/AO2: U17.11 (F2), U22.14 (A3)
/AO3: U17.12 (F3), U22.12 (A4)
/AO4: U18.8 (F0), U23.5 (A1)
/AO5: U18.9 (F1), U23.3 (A2)
/AO6: U18.11 (F2), U23.14 (A3)
/AO7: U18.12 (F3), U23.12 (A4)
/AO8: U19.8 (F0), U24.5 (A1)
/AO9: U19.9 (F1), U24.3 (A2)
/AO10: U19.11 (F2), U24.14 (A3)
/AO11: U19.12 (F3), U24.12 (A4)
/AO12: U20.8 (F0), U25.5 (A1)
/AO13: U20.9 (F1), U25.3 (A2)
/AO14: U20.11 (F2), U25.14 (A3)
/AO15: U20.12 (F3), U25.12 (A4)
/AO16: U21.8 (F0), U26.5 (A1)
/AO17: U21.9 (F1), U26.3 (A2)
/AR0: U22.4 (S1), U27.2 (I0a)
/AR1: U22.1 (S2), U27.4 (I1a)
/AR2: U22.13 (S3), U27.6 (I2a)
/AR3: U22.10 (S4), U27.8 (I3a)
/AR4: U23.4 (S1), U38.11 (I0d)
/AR5: U23.1 (S2), U27.13 (I1b)
/AR6: U23.13 (S3), U27.15 (I2b)
/AR7: U23.10 (S4), U27.17 (I3b)
/AR8: U24.4 (S1), U28.2 (I0a)
/AR9: U24.1 (S2), U28.4 (I1a)
/AR10: U24.13 (S3), U28.6 (I2a)
/AR11: U24.10 (S4), U28.8 (I3a)
/AR12: U25.4 (S1), U28.11 (I0b)
/AR13: U25.1 (S2), U28.13 (I1b)
/AR14: U25.13 (S3), U28.15 (I2b)
/AR15: U25.10 (S4), U28.17 (I3b)
/AR16: U26.4 (S1), U29.2 (I0a)
/AR17: U26.1 (S2), U29.4 (I1a), U30.1
/ARITH_CARRY_OUT: U21.11 (F2), U30.10, U33.9
/BUS_SELECT0: J1.b9
/BUS_SELECT1: J1.b10
/BUS_SELECT2: J1.b11
/CLK: J2.a23, U1.11 (CP), U2.11 (CP), U3.11 (CP), U4.11 (CP), U5.11 (CP), U6.11 (CP)
/CTL_CONST: J1.b29, U38.1 (S)
/D0: J2.a3, U1.3 (D0), U4.3 (D0), U7.7 (Za), U27.18 (O0a)
/D1: J2.a4, U1.4 (D1), U4.4 (D1), U7.9 (Zb), U27.16 (O1a)
/D2: J2.a5, U1.7 (D2), U4.7 (D2), U8.7 (Za), U27.14 (O2a)
/D3: J2.a6, U1.8 (D3), U4.8 (D3), U8.9 (Zb), U27.12 (O3a)
/D4: J2.a7, U1.13 (D4), U4.13 (D4), U9.7 (Za), U27.9 (O0b)
/D5: J2.a8, U1.14 (D5), U4.14 (D5), U9.9 (Zb), U27.7 (O1b)
/D6: J2.a9, U1.17 (D6), U4.17 (D6), U10.7 (Za), U27.5 (O2b)
/D7: J2.a10, U1.18 (D7), U4.18 (D7), U10.9 (Zb), U27.3 (O3b)
/D8: J2.a11, U2.3 (D0), U5.3 (D0), U11.7 (Za), U28.18 (O0a)
/D9: J2.a12, U2.4 (D1), U5.4 (D1), U11.9 (Zb), U28.16 (O1a)
/D10: J2.a13, U2.7 (D2), U5.7 (D2), U12.7 (Za), U28.14 (O2a)
/D11: J2.a14, U2.8 (D3), U5.8 (D3), U12.9 (Zb), U28.12 (O3a)
/D12: J2.a15, U2.13 (D4), U5.13 (D4), U13.7 (Za), U28.9 (O0b)
/D13: J2.a16, U2.14 (D5), U5.14 (D5), U13.9 (Zb), U28.7 (O1b)
/D14: J2.a17, U2.17 (D6), U5.17 (D6), U14.7 (Za), U28.5 (O2b)
/D15: J2.a18, U2.18 (D7), U5.18 (D7), U14.9 (Zb), U28.3 (O3b)
/D16: J2.a19, U3.3 (D0), U6.3 (D0), U15.7 (Za), U29.18 (O0a)
/D17: J2.a20, U3.4 (D1), U6.4 (D1), U15.9 (Zb), U29.16 (O1a)
/EXTRA0: J1.b30
/EXTRA1: J2.a24
/EXTRA2: J2.b24
/EXTRA3: J2.a25
/EXTRA4: J2.b25
/EXTRA5: J2.a26
/EXTRA6: J2.b26
/FLAG_AC_SIGN: J1.b8, U6.8 (D3), U38.12 (Zc)
/FLAG_LINK: J1.b6, U3.6 (Q2), U7.5 (I1a), U7.13 (I3b), U15.4 (I2a), U15.10 (I0b), U21.19 (A2), U30.9, U32.9, U33.11, U34.6 (I0a), U39.11, U39.12, U39.13
/FLAG_LINK_INIT: J1.b7, U6.7 (D2), U38.7 (Zb)
/FLAG_ZERO: J1.b4, U37.8
/FP0: J2.a29
/FP1: J2.b29
/FP2: J2.a30
/FP3: J2.b30
/HALT: J1.b26
/LINKS0: J1.a27, U34.14 (A0)
/LINKS1: J1.a28, U34.2 (A1)
/MA_AUTO_INX: J2.b28
/MB0: U4.2 (Q0), U17.4 (B0)
/MB1: U4.5 (Q1), U17.2 (B1)
/MB2: U4.6 (Q2), U17.18 (B2)
/MB3: U4.9 (Q3), U17.16 (B3)
/MB4: U4.12 (Q4), U18.4 (B0)
/MB5: U4.15 (Q5), U18.2 (B1)
/MB6: U4.16 (Q6), U18.18 (B2)
/MB7: U4.19 (Q7), U18.16 (B3)
/MB8: U5.2 (Q0), U19.4 (B0)
/MB9: U5.5 (Q1), U19.2 (B1)
/MB10: U5.6 (Q2), U19.18 (B2)
/MB11: U5.9 (Q3), U19.16 (B3)
/MB12: U5.12 (Q4), U20.4 (B0)
/MB13: U5.15 (Q5), U20.2 (B1)
/MB14: U5.16 (Q6), U20.18 (B2)
/MB15: U5.19 (Q7), U20.16 (B3)
/MB16: U6.2 (Q0), U21.4 (B0)
/MB17: U6.5 (Q1), U21.2 (B1), U30.5
/NEXT_BANK0: J2.a27
/NEXT_BANK1: J2.b27
/OB0: U1.2 (Q0), U7.11 (I1b), U8.3 (I3a), U15.12 (I2b), U16.6 (I0a), U17.3 (A0), U35.1
/OB1: U1.5 (Q1), U7.6 (I0a), U8.5 (I1a), U8.13 (I3b), U16.4 (I2a), U17.1 (A1), U35.2
/OB2: U1.6 (Q2), U7.4 (I2a), U7.10 (I0b), U8.11 (I1b), U9.3 (I3a), U17.19 (A2), U35.13
/OB3: U1.9 (Q3), U7.12 (I2b), U8.6 (I0a), U9.5 (I1a), U9.13 (I3b), U17.17 (A3), U35.3
/OB4: U1.12 (Q4), U8.4 (I2a), U8.10 (I0b), U9.11 (I1b), U10.3 (I3a), U18.3 (A0), U35.4
/OB5: U1.15 (Q5), U8.12 (I2b), U9.6 (I0a), U10.5 (I1a), U10.13 (I3b), U18.1 (A1), U35.5
/OB6: U1.16 (Q6), U9.4 (I2a), U9.10 (I0b), U10.11 (I1b), U11.3 (I3a), U18.19 (A2), U35.9
/OB7: U1.19 (Q7), U9.12 (I2b), U10.6 (I0a), U11.5 (I1a), U11.13 (I3b), U18.17 (A3), U35.10
/OB8: U2.2 (Q0), U10.4 (I2a), U10.10 (I0b), U11.11 (I1b), U12.3 (I3a), U19.3 (A0), U35.11
/OB9: U2.5 (Q1), U10.12 (I2b), U11.6 (I0a), U12.5 (I1a), U12.13 (I3b), U19.1 (A1), U36.1
/OB10: U2.6 (Q2), U11.4 (I2a), U11.10 (I0b), U12.11 (I1b), U13.3 (I3a), U19.19 (A2), U36.2
/OB11: U2.9 (Q3), U11.12 (I2b), U12.6 (I0a), U13.5 (I1a), U13.13 (I3b), U19.17 (A3), U36.13
/OB12: U2.12 (Q4), U12.4 (I2a), U12.10 (I0b), U13.11 (I1b), U14.3 (I3a), U20.3 (A0), U36.3
/OB13: U2.15 (Q5), U12.12 (I2b), U13.6 (I0a), U14.5 (I1a), U14.13 (I3b), U20.1 (A1), U36.4
/OB14: U2.16 (Q6), U13.4 (I2a), U13.10 (I0b), U14.11 (I1b), U15.3 (I3a), U20.19 (A2), U36.5
/OB15: U2.19 (Q7), U13.12 (I2b), U14.6 (I0a), U15.5 (I1a), U15.13 (I3b), U20.17 (A3), U36.9
/OB16: U3.2 (Q0), U14.4 (I2a), U14.10 (I0b), U15.11 (I1b), U16.3 (I3a), U21.3 (A0), U36.10
/OB17: J1.b5, U3.5 (Q1), U7.3 (I3a), U14.12 (I2b), U15.6 (I0a), U16.5 (I1a), U21.1 (A1), U30.2, U33.3, U36.11
/REQ_ADDR: J1.b22
/SC0: J2.b18
/SC1: J2.b19
/SC2: J2.b20
/SC3: J2.b21
/SC4: J2.b22
/SC5: J2.b23
/SELECT_PCMA: J1.a23
/STEP_ZERO: J1.b3
GND: C1.2, C2.2, C3.2, C4.2, C5.2, C6.2, C7.2, C8.2, C9.2, C10.2, C11.2, C12.2, C13.2, C14.2, C15.2, C16.2, C17.2, C18.2, C19.2, C20.2, C21.2, C22.2, C23.2, C24.2, C25.2, C26.2, C27.2, C28.2, C29.2, C30.2, C31.2, C32.2, C33.2, C34.2, C35.2, C36.2, C37.2, C38.2, C39.2, J1.a1, J1.b32, J2.a1, J2.b32, U1.10 (GND), U2.10 (GND), U3.8 (D3), U3.10 (GND), U3.13 (D4), U3.14 (D5), U3.17 (D6), U3.18 (D7), U4.10 (GND), U5.10 (GND), U6.10 (GND), U6.14 (D5), U6.17 (D6), U6.18 (D7), U7.8 (GND), U8.8 (GND), U9.8 (GND), U10.8 (GND), U11.8 (GND), U12.8 (GND), U13.8 (GND), U14.8 (GND), U15.8 (GND), U16.1 (OEa), U16.8 (GND), U16.10 (I0b), U16.11 (I1b), U16.12 (I2b), U16.13 (I3b), U16.15 (OEb), U17.10 (GND), U18.10 (GND), U19.10 (GND), U20.10 (GND), U21.10 (GND), U21.16 (B3), U21.17 (A3), U21.18 (B2), U22.2 (B2), U22.6 (B1), U22.8 (GND), U22.11 (B4), U22.15 (B3), U23.2 (B2), U23.6 (B1), U23.8 (GND), U23.11 (B4), U23.15 (B3), U24.2 (B2), U24.6 (B1), U24.8 (GND), U24.11 (B4), U24.15 (B3), U25.2 (B2), U25.6 (B1), U25.8 (GND), U25.11 (B4), U25.15 (B3), U26.2 (B2), U26.6 (B1), U26.8 (GND), U26.11 (B4), U26.12 (A4), U26.14 (A3), U26.15 (B3), U27.10 (GND), U28.10 (GND), U29.6 (I2a), U29.8 (I3a), U29.10 (GND), U29.11 (I0b), U29.13 (I1b), U29.15 (I2b), U29.17 (I3b), U30.7 (GND), U30.12, U30.13, U31.7 (GND), U32.7 (GND), U33.7 (GND), U34.1 (OEa), U34.8 (GND), U34.10 (I0b), U34.11 (I1b), U34.12 (I2b), U34.13 (I3b), U34.15 (OEb), U35.7 (GND), U36.7 (GND), U37.7 (GND), U38.2 (I0a), U38.3 (I1a), U38.8 (GND), U38.15 (OE), U39.7 (GND); also elsewhere on the board
unnamed: R1.2, U37.9
unnamed: U3.7 (D2), U34.7 (Za), U38.6 (I1b)
unnamed: U7.1 (OEa), U7.15 (OEb), U8.1 (OEa), U8.15 (OEb), U9.1 (OEa), U9.15 (OEb), U10.1 (OEa), U10.15 (OEb), U11.1 (OEa), U11.15 (OEb), U39.8
unnamed: U16.7 (Za), U34.3 (I3a)
unnamed: U17.15 (Cn), U33.2
unnamed: U17.14 (Cout), U18.15 (Cn)
unnamed: U18.14 (Cout), U19.15 (Cn)
unnamed: U19.14 (Cout), U20.15 (Cn)
unnamed: U20.14 (Cout), U21.15 (Cn)
unnamed: U22.7 (C0), U31.3
unnamed: U22.9 (C4), U23.7 (C0)
unnamed: U23.9 (C4), U24.7 (C0)
unnamed: U24.9 (C4), U25.7 (C0)
unnamed: U25.9 (C4), U26.7 (C0)
unnamed: U27.11 (I0b), U38.9 (Zd)
unnamed: U30.3, U31.9
unnamed: U30.4, U33.4
unnamed: U30.6, U31.10
unnamed: U30.8, U32.2
unnamed: U31.2, U32.3
unnamed: U31.6, U33.1
unnamed: U31.8, U32.10
unnamed: U31.11, U32.5
unnamed: U31.13, U32.8
unnamed: U32.4, U33.6
unnamed: U32.11, U33.5
unnamed: U32.12, U33.8
unnamed: U33.12, U39.5
unnamed: U33.10, U34.5 (I1a)
unnamed: U32.6, U34.4 (I2a)
unnamed: U35.6, U37.2
unnamed: U35.8, U37.13
unnamed: U35.12, U37.1
unnamed: U36.6, U37.4
unnamed: U36.8, U37.5
unnamed: U36.12, U37.3
unnamed: U37.10, U37.12
unnamed: U37.6, U37.11
unnamed: U6.6 (Q2), U38.5 (I0b), U38.13 (I1c)
unnamed: U6.9 (Q3), U38.14 (I0c)
unnamed: R2.2, U38.10 (I1d)

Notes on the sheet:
Carry in if subtracting
Arithmetic link output select
Register
OB zero detect
Post-increment enable
Ones-complement overflow

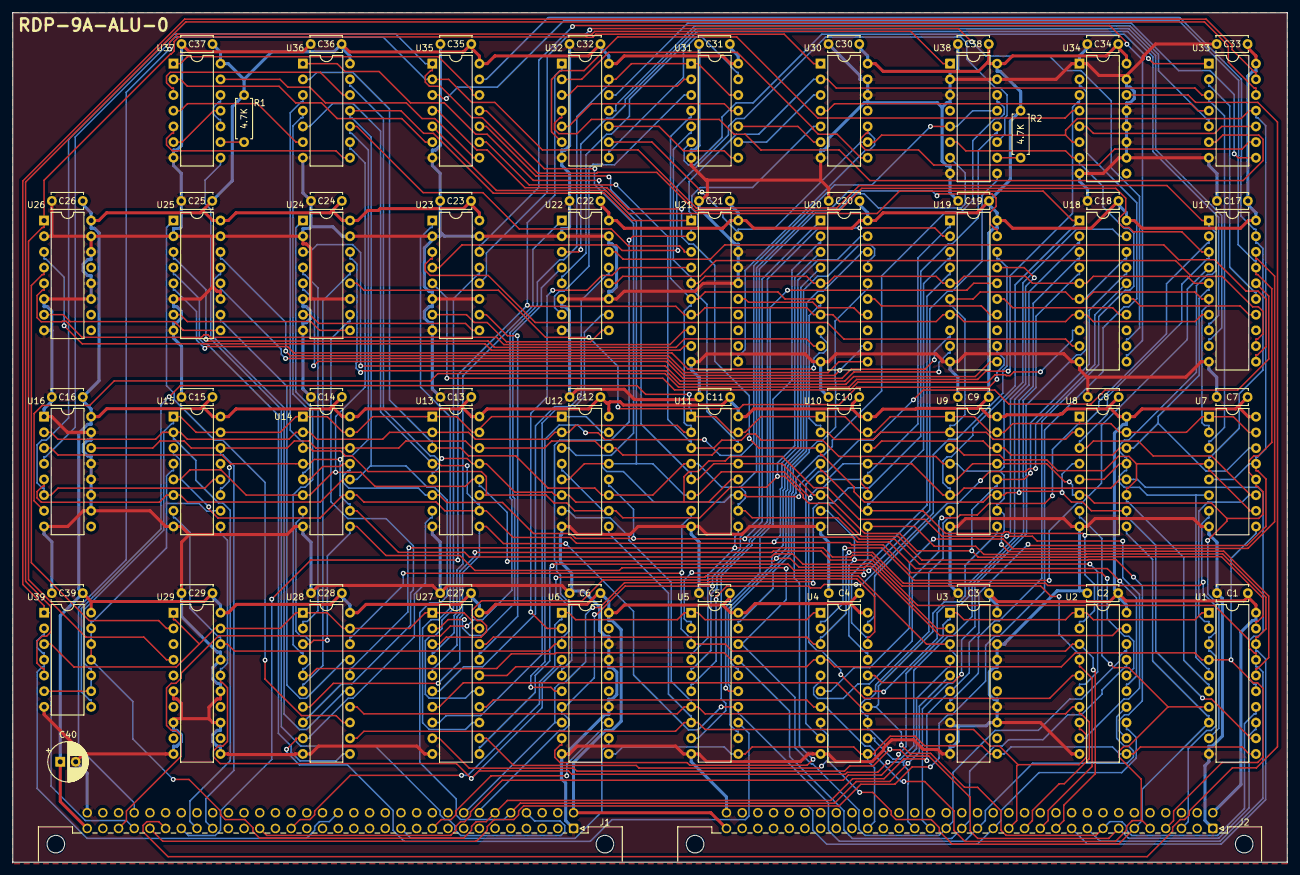
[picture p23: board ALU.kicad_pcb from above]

Board: 2 copper layers, 206.4 x 137.5 mm, 83 parts (0 on the bottom side), 154 nets.

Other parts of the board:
C40: 100 uF; CP_Radial_D6.3mm_P2.50mm

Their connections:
+5V: C40.1; also elsewhere on the board
GND: C40.2; also elsewhere on the board

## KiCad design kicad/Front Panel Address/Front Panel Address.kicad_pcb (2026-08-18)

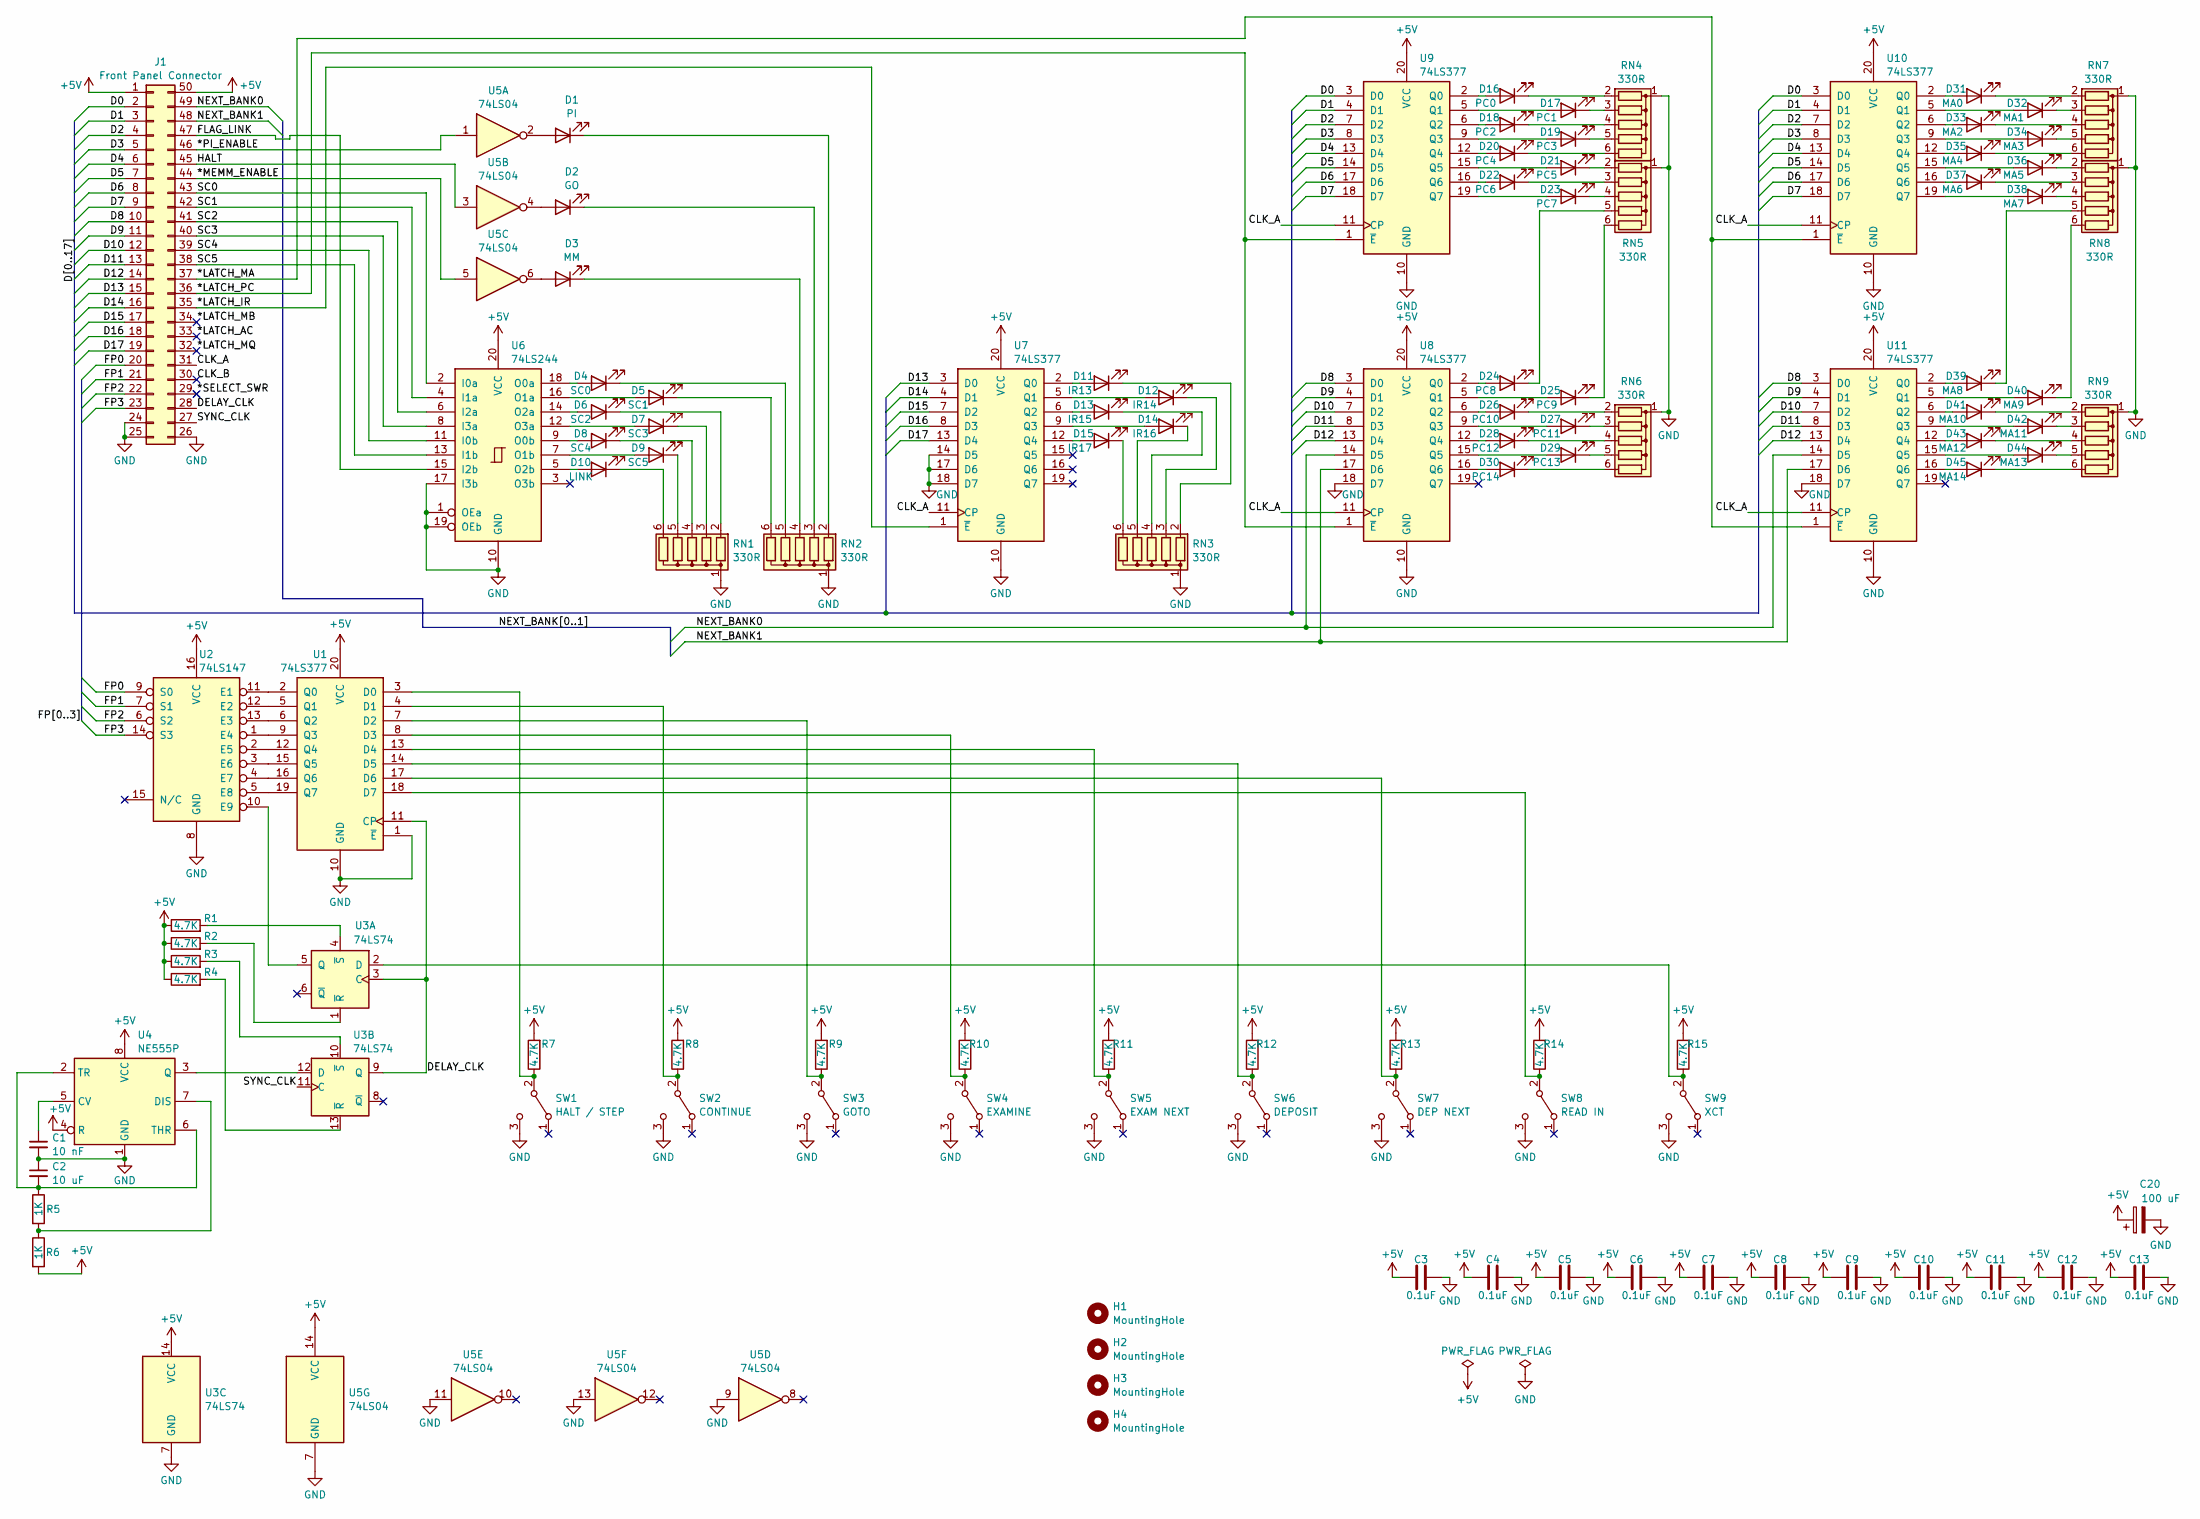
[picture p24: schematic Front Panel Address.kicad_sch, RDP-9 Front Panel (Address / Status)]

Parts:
C1: 10 nF; C_Disc_D5.0mm_W2.5mm_P5.00mm
C2: 10 uF; C_Disc_D5.0mm_W2.5mm_P5.00mm
C3, C4, C5, C6, C7, C8, C9, C10, C11, C12, C13: 0.1uF; C_Disc_D5.0mm_W2.5mm_P5.00mm
C20: 100 uF; CP_Radial_D6.3mm_P2.50mm
D1: PI; LED_D5.0mm
D2: GO; LED_D5.0mm
D3: MM; LED_D5.0mm
D4: SC0; LED_D5.0mm
D5: SC1; LED_D5.0mm
D6: SC2; LED_D5.0mm
D7: SC3; LED_D5.0mm
D8: SC4; LED_D5.0mm
D9: SC5; LED_D5.0mm
D10: LINK; LED_D5.0mm
D11: IR13; LED_D5.0mm
D12: IR14; LED_D5.0mm
D13: IR15; LED_D5.0mm
D14: IR16; LED_D5.0mm
D15: IR17; LED_D5.0mm
D16: PC0; LED_D5.0mm
D17: PC1; LED_D5.0mm
D18: PC2; LED_D5.0mm
D19: PC3; LED_D5.0mm
D20: PC4; LED_D5.0mm
D21: PC5; LED_D5.0mm
D22: PC6; LED_D5.0mm
D23: PC7; LED_D5.0mm
D24: PC8; LED_D5.0mm
D25: PC9; LED_D5.0mm
D26: PC10; LED_D5.0mm
D27: PC11; LED_D5.0mm
D28: PC12; LED_D5.0mm
D29: PC13; LED_D5.0mm
D30: PC14; LED_D5.0mm
D31: MA0; LED_D5.0mm
D32: MA1; LED_D5.0mm
D33: MA2; LED_D5.0mm
D34: MA3; LED_D5.0mm
D35: MA4; LED_D5.0mm
D36: MA5; LED_D5.0mm
D37: MA6; LED_D5.0mm
D38: MA7; LED_D5.0mm
D39: MA8; LED_D5.0mm
D40: MA9; LED_D5.0mm
D41: MA10; LED_D5.0mm
D42: MA11; LED_D5.0mm
D43: MA12; LED_D5.0mm
D44: MA13; LED_D5.0mm
D45: MA14; LED_D5.0mm
H1, H2, H3, H4: MountingHole; MountingHole_2.2mm_M2_Pad
J1: Front Panel Connector; IDC-Header_2x25_P2.54mm_Vertical
R1, R2, R3, R4, R7, R8, R9, R10, R11, R12, R13, R14, R15: 4.7K; R_Axial_DIN0207_L6.3mm_D2.5mm_P7.62mm_Horizontal
R5, R6: 1K; R_Axial_DIN0207_L6.3mm_D2.5mm_P7.62mm_Horizontal
RN1, RN2, RN3, RN4, RN5, RN6, RN7, RN8, RN9: 330R; R_Array_SIP6
SW1: HALT / STEP; MTS-102
SW2: CONTINUE; MTS-102
SW3: GOTO; MTS-102
SW4: EXAMINE; MTS-102
SW5: EXAM NEXT; MTS-102
SW6: DEPOSIT; MTS-102
SW7: DEP NEXT; MTS-102
SW8: READ IN; MTS-102
SW9: XCT; MTS-102
U1, U7, U8, U9, U10, U11: 74LS377; DIP-20_W7.62mm
U2: 74LS147; DIP-16_W7.62mm
U3: 74LS74; DIP-14_W7.62mm
U4: NE555P; DIP-8_W7.62mm
U5: 74LS04; DIP-14_W7.62mm
U6: 74LS244; DIP-20_W7.62mm

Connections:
+5V: C3.1, C4.1, C5.1, C6.1, C7.1, C8.1, C9.1, C10.1, C11.1, C12.1, C13.1, J1.1, J1.50, R1.1, R2.1, R3.1, R4.1, R6.2, R7.2, R8.2, R9.2, R10.2, R11.2, R12.2, R13.2, R14.2, R15.2, U1.20 (VCC), U2.16 (VCC), U3.14 (VCC), U4.4 (R), U4.8 (VCC), U5.14 (VCC), U6.20 (VCC), U7.20 (VCC), U8.20 (VCC), U9.20 (VCC), U10.20 (VCC), U11.20 (VCC); also elsewhere on the board
/*LATCH_AC: J1.33
/*LATCH_IR: J1.35, U7.1 (~E)
/*LATCH_MA: J1.37, U10.1 (~E), U11.1 (~E)
/*LATCH_MB: J1.34
/*LATCH_MQ: J1.32
/*LATCH_PC: J1.36, U8.1 (~E), U9.1 (~E)
/*MEMM_ENABLE: J1.44, U5.5
/*PI_ENABLE: J1.46, U5.1
/*SELECT_SWR: J1.29
/CLK_A: J1.31, U7.11 (CP), U8.11 (CP), U9.11 (CP), U10.11 (CP), U11.11 (CP)
/CLK_B: J1.30
/D0: J1.2, U9.3 (D0), U10.3 (D0)
/D1: J1.3, U9.4 (D1), U10.4 (D1)
/D2: J1.4, U9.7 (D2), U10.7 (D2)
/D3: J1.5, U9.8 (D3), U10.8 (D3)
/D4: J1.6, U9.13 (D4), U10.13 (D4)
/D5: J1.7, U9.14 (D5), U10.14 (D5)
/D6: J1.8, U9.17 (D6), U10.17 (D6)
/D7: J1.9, U9.18 (D7), U10.18 (D7)
/D8: J1.10, U8.3 (D0), U11.3 (D0)
/D9: J1.11, U8.4 (D1), U11.4 (D1)
/D10: J1.12, U8.7 (D2), U11.7 (D2)
/D11: J1.13, U8.8 (D3), U11.8 (D3)
/D12: J1.14, U8.13 (D4), U11.13 (D4)
/D13: J1.15, U7.3 (D0)
/D14: J1.16, U7.4 (D1)
/D15: J1.17, U7.7 (D2)
/D16: J1.18, U7.8 (D3)
/D17: J1.19, U7.13 (D4)
/DELAY_CLK: J1.28, U1.11 (CP), U3.3 (C), U3.9 (Q)
/FLAG_LINK: J1.47, U6.15 (I2b)
/FP0: J1.20, U2.9 (S0)
/FP1: J1.21, U2.7 (S1)
/FP2: J1.22, U2.6 (S2)
/FP3: J1.23, U2.14 (S3)
/HALT: J1.45, U5.3
/NEXT_BANK0: J1.49, U8.14 (D5), U11.14 (D5)
/NEXT_BANK1: J1.48, U8.17 (D6), U11.17 (D6)
/SC0: J1.43, U6.2 (I0a)
/SC1: J1.42, U6.4 (I1a)
/SC2: J1.41, U6.6 (I2a)
/SC3: J1.40, U6.8 (I3a)
/SC4: J1.39, U6.11 (I0b)
/SC5: J1.38, U6.13 (I1b)
/SYNC_CLK: J1.27, U3.11 (C)
GND: C1.2, C2.1, C3.2, C4.2, C5.2, C6.2, C7.2, C8.2, C9.2, C10.2, C11.2, C12.2, C13.2, J1.24, J1.25, J1.26, RN1.1 (common), RN2.1 (common), RN3.1 (common), RN4.1 (common), RN5.1 (common), RN6.1 (common), RN7.1 (common), RN8.1 (common), RN9.1 (common), SW1.3 (C), SW2.3 (C), SW3.3 (C), SW4.3 (C), SW5.3 (C), SW6.3 (C), SW7.3 (C), SW8.3 (C), SW9.3 (C), U1.1 (~E), U1.10 (GND), U2.8 (GND), U3.7 (GND), U4.1 (GND), U5.7 (GND), U5.9, U5.11, U5.13, U6.1 (OEa), U6.10 (GND), U6.17 (I3b), U6.19 (OEb), U7.10 (GND), U7.14 (D5), U7.17 (D6), U7.18 (D7), U8.10 (GND), U8.18 (D7), U9.10 (GND), U10.10 (GND), U11.10 (GND), U11.18 (D7); also elsewhere on the board
unnamed: D1.2 (A), U5.2
unnamed: D1.1 (K), RN2.2 (R1)
unnamed: D2.2 (A), U5.4
unnamed: D2.1 (K), RN2.3 (R2)
unnamed: D3.2 (A), U5.6
unnamed: D3.1 (K), RN2.4 (R3)
unnamed: D4.2 (A), U6.18 (O0a)
unnamed: D4.1 (K), RN2.5 (R4)
unnamed: D5.2 (A), U6.16 (O1a)
unnamed: D5.1 (K), RN2.6 (R5)
unnamed: D6.2 (A), U6.14 (O2a)
unnamed: D6.1 (K), RN1.2 (R1)
unnamed: D7.2 (A), U6.12 (O3a)
unnamed: D7.1 (K), RN1.3 (R2)
unnamed: D8.2 (A), U6.9 (O0b)
unnamed: D8.1 (K), RN1.4 (R3)
unnamed: D9.2 (A), U6.7 (O1b)
unnamed: D9.1 (K), RN1.5 (R4)
unnamed: D10.2 (A), U6.5 (O2b)
unnamed: D10.1 (K), RN1.6 (R5)
unnamed: D11.2 (A), U7.2 (Q0)
unnamed: D11.1 (K), RN3.2 (R1)
unnamed: D12.2 (A), U7.5 (Q1)
unnamed: D12.1 (K), RN3.3 (R2)
unnamed: D13.2 (A), U7.6 (Q2)
unnamed: D13.1 (K), RN3.4 (R3)
unnamed: D14.2 (A), U7.9 (Q3)
unnamed: D14.1 (K), RN3.5 (R4)
unnamed: D15.2 (A), U7.12 (Q4)
unnamed: D15.1 (K), RN3.6 (R5)
unnamed: D16.2 (A), U9.2 (Q0)
unnamed: D16.1 (K), RN4.2 (R1)
unnamed: D17.2 (A), U9.5 (Q1)
unnamed: D17.1 (K), RN4.3 (R2)
unnamed: D18.2 (A), U9.6 (Q2)
unnamed: D18.1 (K), RN4.4 (R3)
unnamed: D19.2 (A), U9.9 (Q3)
unnamed: D19.1 (K), RN4.5 (R4)
unnamed: D20.2 (A), U9.12 (Q4)
unnamed: D20.1 (K), RN4.6 (R5)
unnamed: D21.2 (A), U9.15 (Q5)
unnamed: D21.1 (K), RN5.2 (R1)
unnamed: D22.2 (A), U9.16 (Q6)
unnamed: D22.1 (K), RN5.3 (R2)
unnamed: D23.2 (A), U9.19 (Q7)
unnamed: D23.1 (K), RN5.4 (R3)
unnamed: D24.2 (A), U8.2 (Q0)
unnamed: D24.1 (K), RN5.5 (R4)
unnamed: D25.2 (A), U8.5 (Q1)
unnamed: D25.1 (K), RN5.6 (R5)
unnamed: D26.2 (A), U8.6 (Q2)
unnamed: D26.1 (K), RN6.2 (R1)
unnamed: D27.2 (A), U8.9 (Q3)
unnamed: D27.1 (K), RN6.3 (R2)
unnamed: D28.2 (A), U8.12 (Q4)
unnamed: D28.1 (K), RN6.4 (R3)
unnamed: D29.2 (A), U8.15 (Q5)
unnamed: D29.1 (K), RN6.5 (R4)
unnamed: D30.2 (A), U8.16 (Q6)
unnamed: D30.1 (K), RN6.6 (R5)
unnamed: D31.2 (A), U10.2 (Q0)
unnamed: D31.1 (K), RN7.2 (R1)
unnamed: D32.2 (A), U10.5 (Q1)
unnamed: D32.1 (K), RN7.3 (R2)
unnamed: D33.2 (A), U10.6 (Q2)
unnamed: D33.1 (K), RN7.4 (R3)
unnamed: D34.2 (A), U10.9 (Q3)
unnamed: D34.1 (K), RN7.5 (R4)
unnamed: D35.2 (A), U10.12 (Q4)
unnamed: D35.1 (K), RN7.6 (R5)
unnamed: D36.2 (A), U10.15 (Q5)
unnamed: D36.1 (K), RN8.2 (R1)
unnamed: D37.2 (A), U10.16 (Q6)
unnamed: D37.1 (K), RN8.3 (R2)
unnamed: D38.2 (A), U10.19 (Q7)
unnamed: D38.1 (K), RN8.4 (R3)
unnamed: D39.2 (A), U11.2 (Q0)
unnamed: D39.1 (K), RN8.5 (R4)
unnamed: D40.2 (A), U11.5 (Q1)
unnamed: D40.1 (K), RN8.6 (R5)
unnamed: D41.2 (A), U11.6 (Q2)
unnamed: D41.1 (K), RN9.2 (R1)
unnamed: D42.2 (A), U11.9 (Q3)
unnamed: D42.1 (K), RN9.3 (R2)
unnamed: D43.2 (A), U11.12 (Q4)
unnamed: D43.1 (K), RN9.4 (R3)
unnamed: D44.2 (A), U11.15 (Q5)
unnamed: D44.1 (K), RN9.5 (R4)
unnamed: D45.2 (A), U11.16 (Q6)
unnamed: D45.1 (K), RN9.6 (R5)
unnamed: R7.1, SW1.2 (B), U1.3 (D0)
unnamed: R8.1, SW2.2 (B), U1.4 (D1)
unnamed: R9.1, SW3.2 (B), U1.7 (D2)
unnamed: R10.1, SW4.2 (B), U1.8 (D3)
unnamed: R11.1, SW5.2 (B), U1.13 (D4)
unnamed: R12.1, SW6.2 (B), U1.14 (D5)
unnamed: R13.1, SW7.2 (B), U1.17 (D6)
unnamed: R14.1, SW8.2 (B), U1.18 (D7)
unnamed: R15.1, SW9.2 (B), U3.2 (D)
unnamed: U1.2 (Q0), U2.11 (E1)
unnamed: U1.5 (Q1), U2.12 (E2)
unnamed: U1.6 (Q2), U2.13 (E3)
unnamed: U1.9 (Q3), U2.1 (E4)
unnamed: U1.12 (Q4), U2.2 (E5)
unnamed: U1.15 (Q5), U2.3 (E6)
unnamed: U1.16 (Q6), U2.4 (E7)
unnamed: U1.19 (Q7), U2.5 (E8)
unnamed: U2.10 (E9), U3.5 (Q)
unnamed: R2.2, U3.1 (~R)
unnamed: R1.2, U3.4 (~S)
unnamed: U3.12 (D), U4.3 (Q)
unnamed: R4.2, U3.13 (~R)
unnamed: R3.2, U3.10 (~S)
unnamed: C1.1, U4.5 (CV)
unnamed: R5.2, R6.1, U4.7 (DIS)
unnamed: C2.2, R5.1, U4.2 (TR), U4.6 (THR)

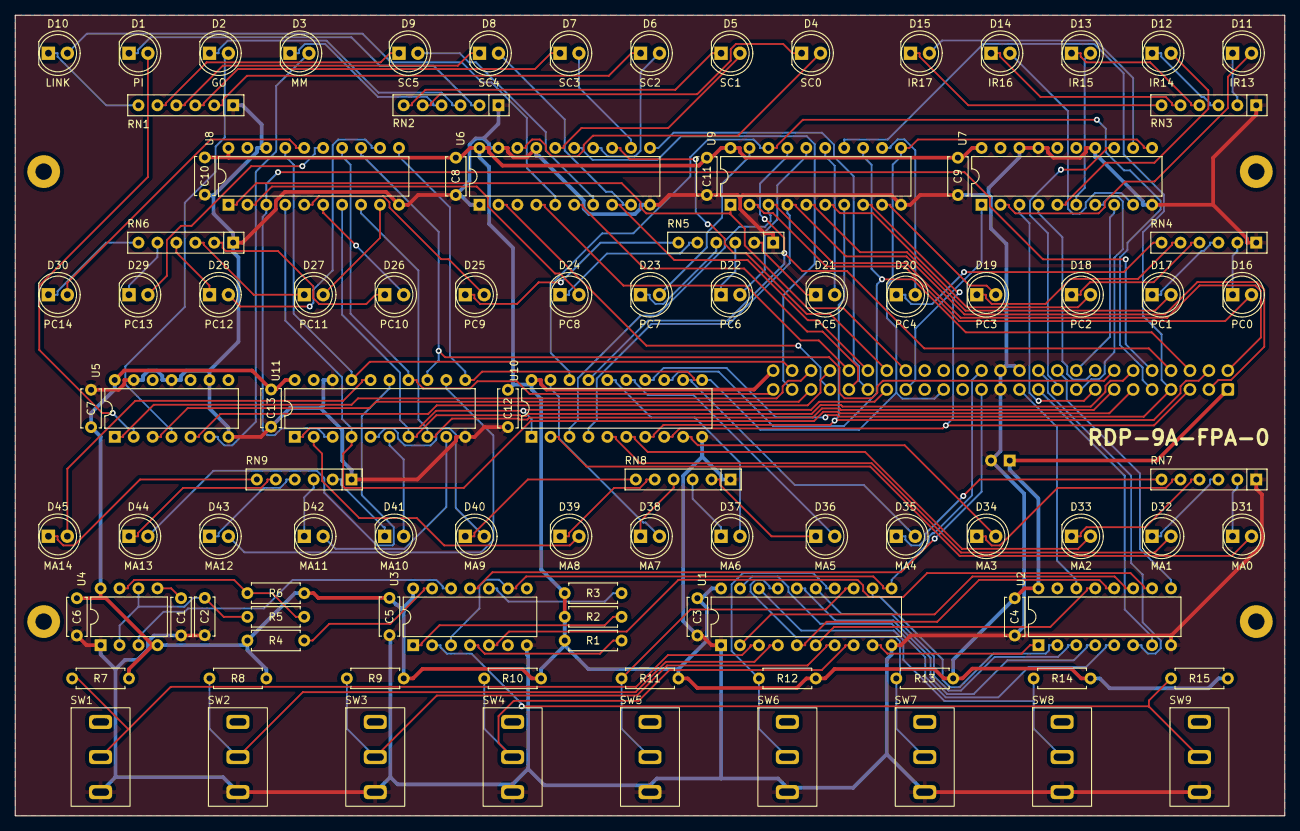
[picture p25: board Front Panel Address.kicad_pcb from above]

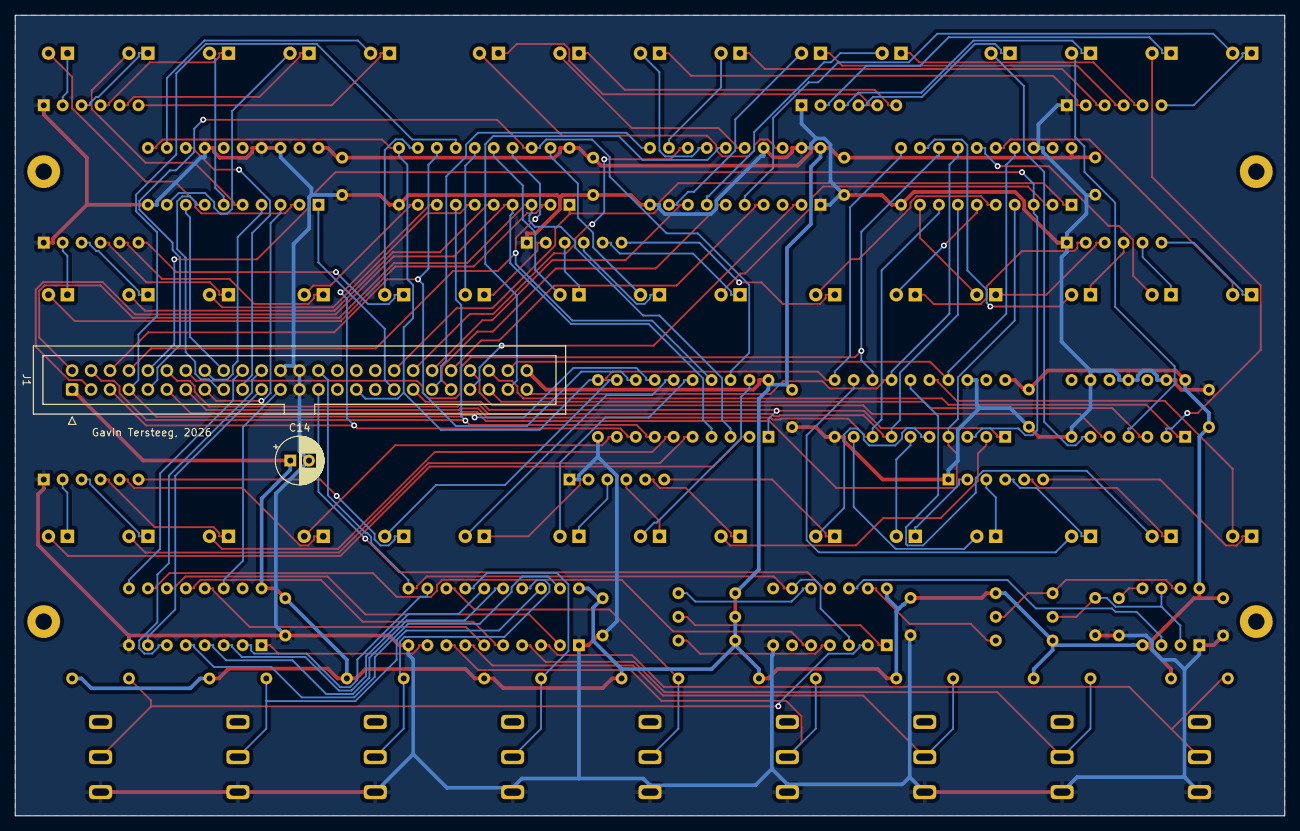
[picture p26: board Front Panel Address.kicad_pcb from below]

Board: 2 copper layers, 170.2 x 107.3 mm, 108 parts (2 on the bottom side), 158 nets.

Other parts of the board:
C14: 100 uF; CP_Radial_D6.3mm_P2.50mm

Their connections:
+5V: C14.1; also elsewhere on the board
GND: C14.2; also elsewhere on the board

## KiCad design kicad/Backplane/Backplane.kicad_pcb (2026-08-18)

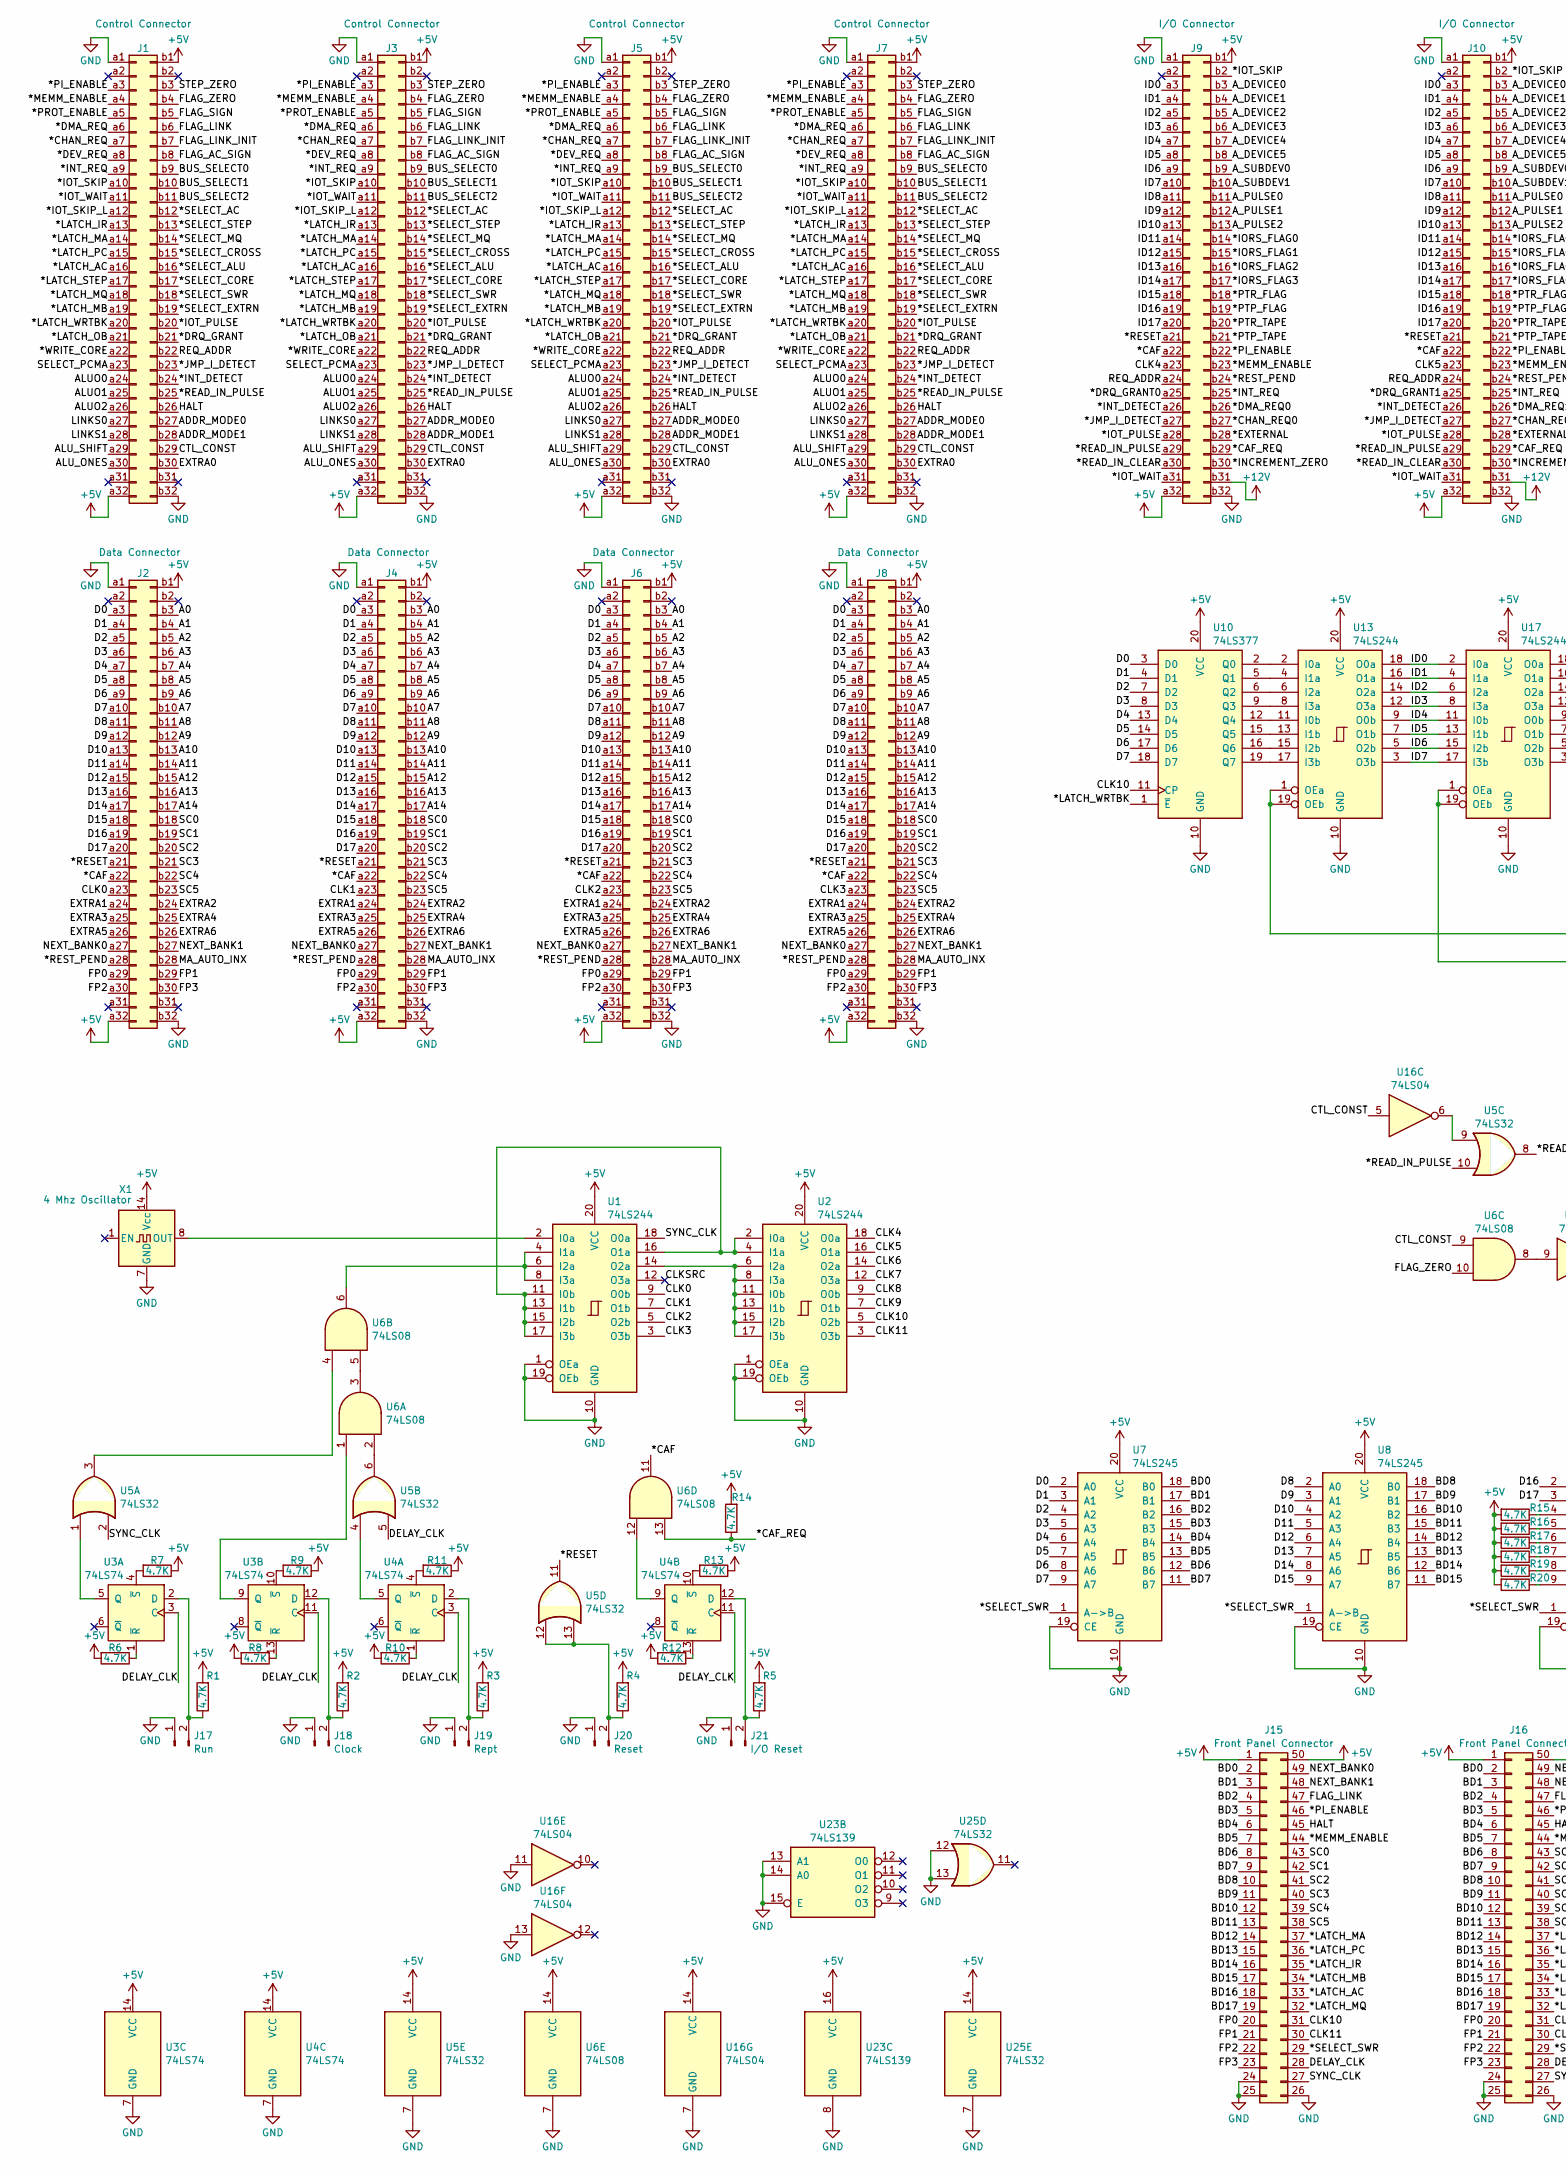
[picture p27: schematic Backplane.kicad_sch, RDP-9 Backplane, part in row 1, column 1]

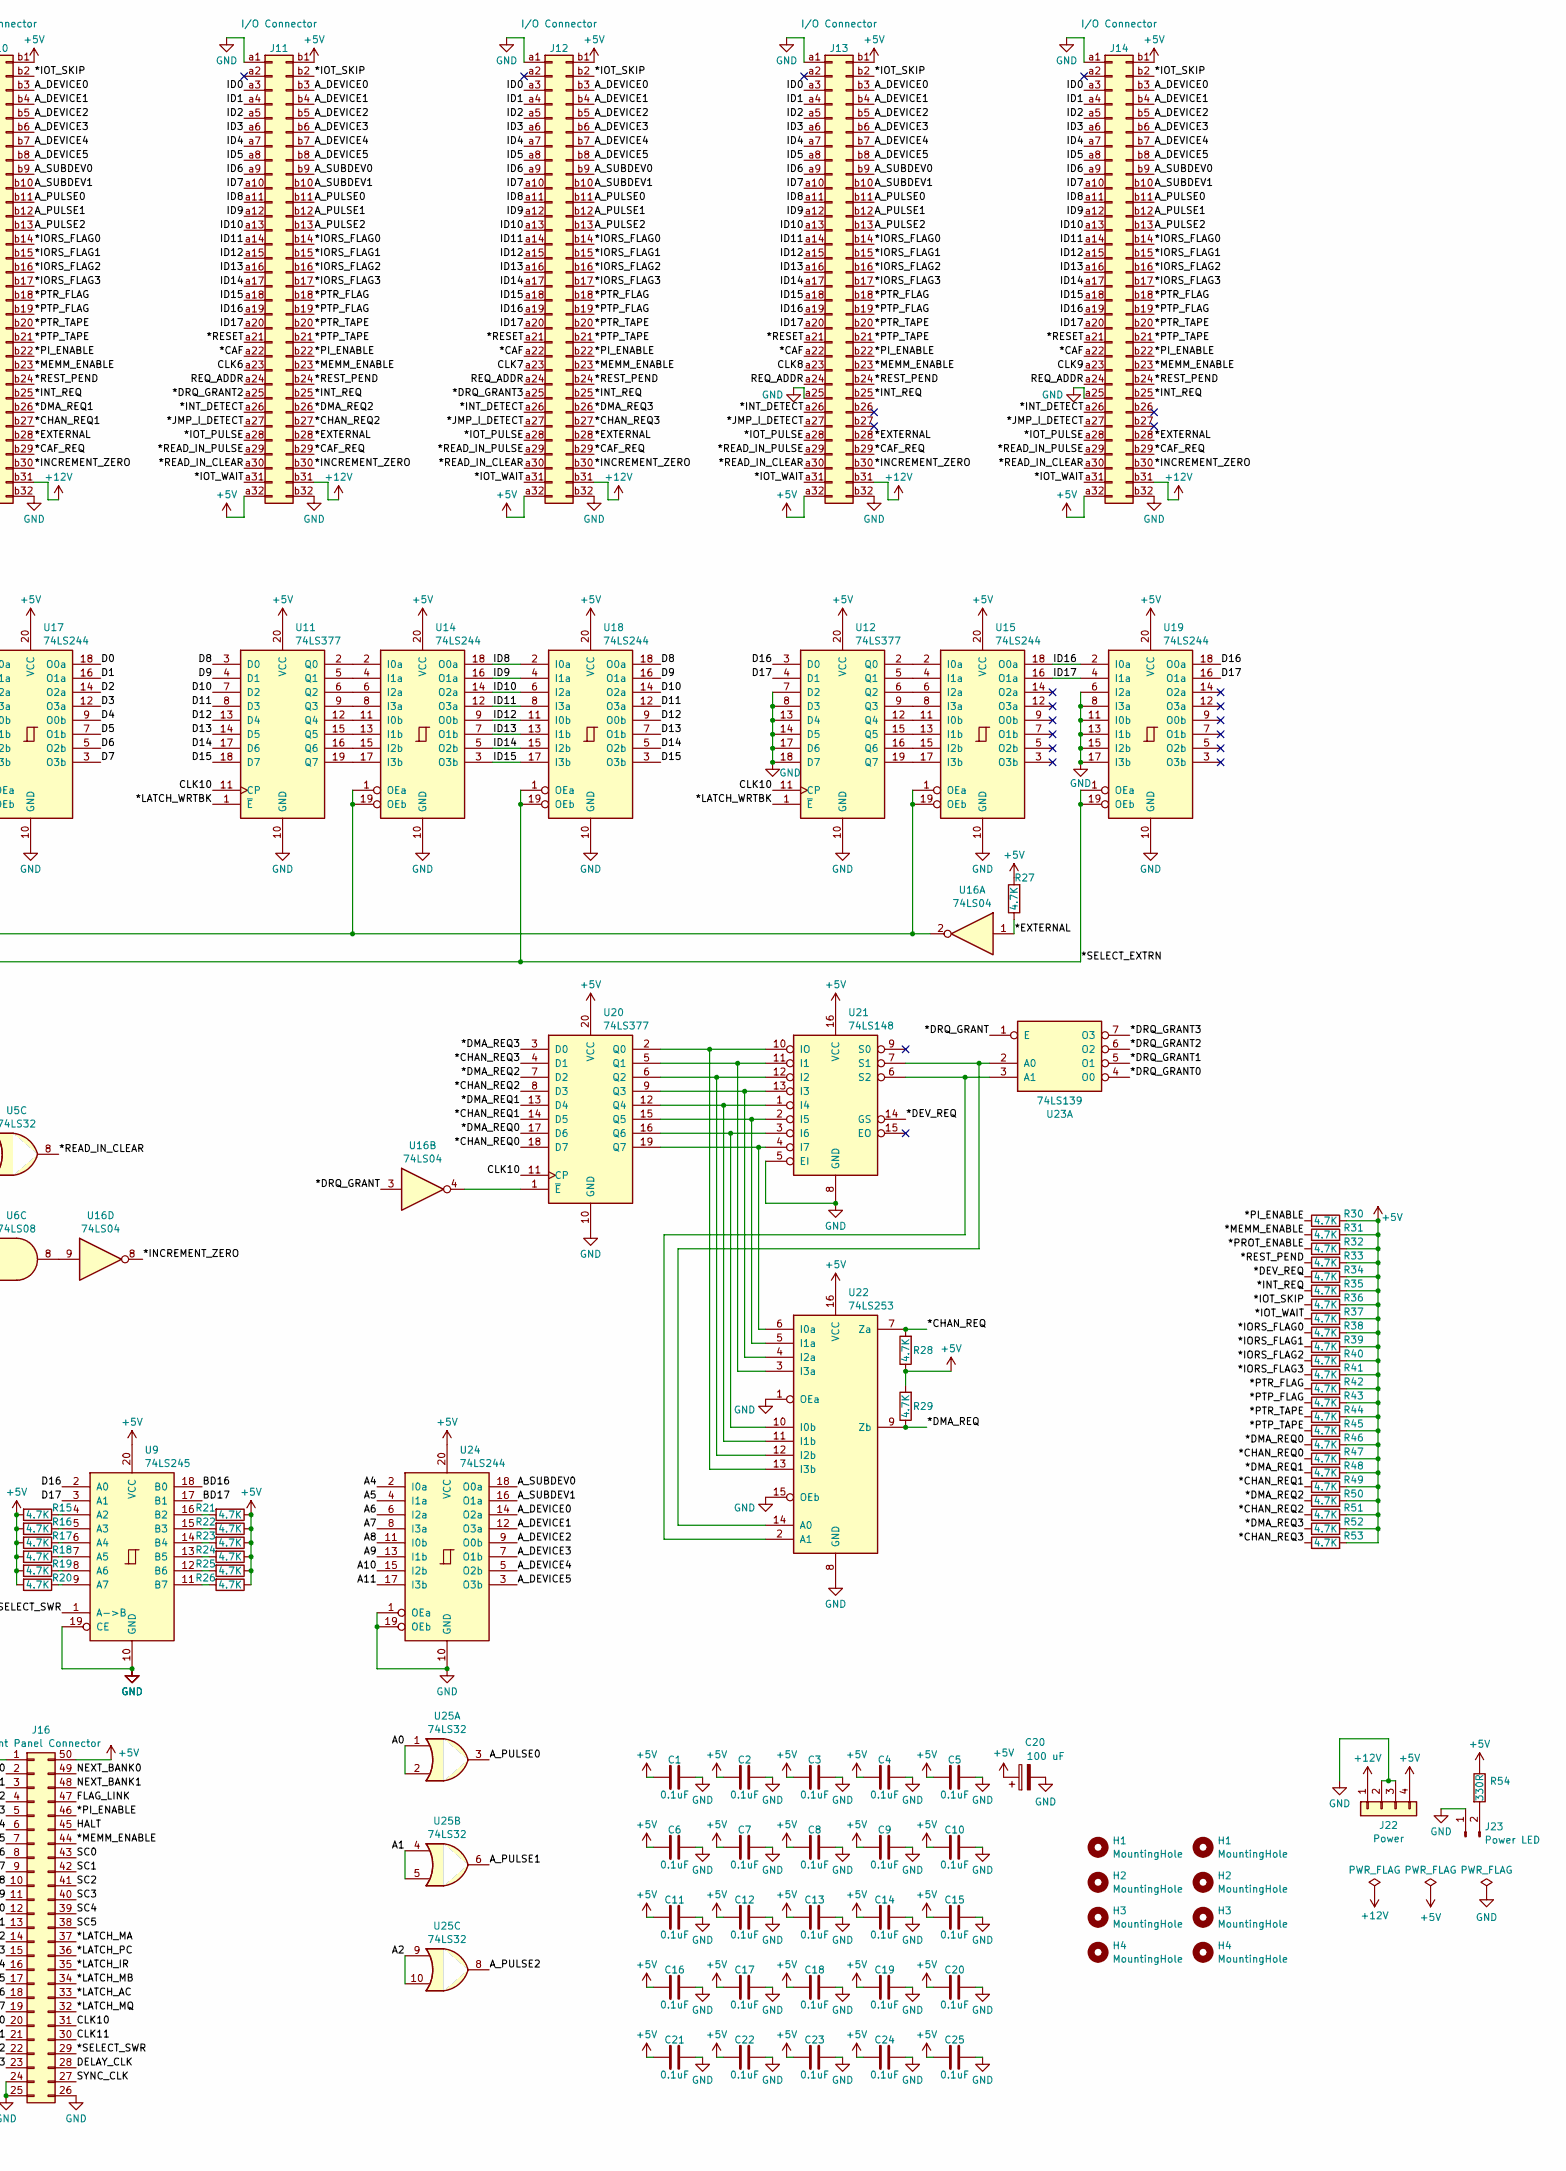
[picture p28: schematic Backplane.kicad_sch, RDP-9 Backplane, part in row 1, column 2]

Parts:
C1, C2, C3, C4, C5, C6, C7, C8, C9, C10, C11, C12, C13, C14, C15, C16, C17, C18, C19, C20, C21, C22, C23, C24, C25: 0.1uF; C_Disc_D5.0mm_W2.5mm_P5.00mm
H1, H2, H3, H4: MountingHole; MountingHole_2.2mm_M2_Pad
J1, J3, J5, J7: Control Connector; DIN41612_B_2x32_Female_Vertical_THT
J2, J4, J6, J8: Data Connector; DIN41612_B_2x32_Female_Vertical_THT
J9, J10, J11, J12, J13, J14: I/O Connector; DIN41612_B_2x32_Female_Vertical_THT
J15, J16: Front Panel Connector; IDC-Header_2x25_P2.54mm_Vertical
J17: Run; PinHeader_1x02_P2.54mm_Vertical
J18: Clock; PinHeader_1x02_P2.54mm_Vertical
J19: Rept; PinHeader_1x02_P2.54mm_Vertical
J20: Reset; PinHeader_1x02_P2.54mm_Vertical
J21: I/O Reset; PinHeader_1x02_P2.54mm_Vertical
J22: Power; TE_MATE-N-LOK_350211-1_1x04_P5.08mm_Vertical
J23: Power LED; PinHeader_1x02_P2.54mm_Vertical
R1, R2, R3, R4, R5, R6, R7, R8, R9, R10, R11, R12, R13, R14, R15, R16, R17, R18, R19, R20, R21, R22, R23, R24, R25, R26, R27, R28, R29, R30, R31, R32, R33, R34, R35, R36, R37, R38, R39, R40, R41, R42, R43, R44, R45, R46, R47, R48, R49, R50, R51, R52, R53: 4.7K; R_Axial_DIN0207_L6.3mm_D2.5mm_P7.62mm_Horizontal
R54: 330R; R_Axial_DIN0207_L6.3mm_D2.5mm_P7.62mm_Horizontal
U1, U2, U13, U14, U15, U17, U18, U19, U24: 74LS244; DIP-20_W7.62mm
U3, U4: 74LS74; DIP-14_W7.62mm
U5, U25: 74LS32; DIP-14_W7.62mm
U6: 74LS08; DIP-14_W7.62mm
U7, U8, U9: 74LS245; DIP-20_W7.62mm
U10, U11, U12, U20: 74LS377; DIP-20_W7.62mm
U16: 74LS04; DIP-14_W7.62mm
U21: 74LS148; DIP-16_W7.62mm
U22: 74LS253; DIP-16_W7.62mm
U23: 74LS139; DIP-16_W7.62mm
X1: 4 Mhz Oscillator; Oscillator_DIP-14

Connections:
+5V: C1.1, C2.1, C3.1, C4.1, C5.1, C6.1, C7.1, C8.1, C9.1, C10.1, C11.1, C12.1, C13.1, C14.1, C15.1, C16.1, C17.1, C18.1, C19.1, C20.1, C21.1, C22.1, C23.1, C24.1, C25.1, J1.a32, J1.b1, J2.a32, J2.b1, J3.a32, J3.b1, J4.a32, J4.b1, J5.a32, J5.b1, J6.a32, J6.b1, J7.a32, J7.b1, J8.a32, J8.b1, J9.a32, J9.b1, J10.a32, J10.b1, J11.a32, J11.b1, J12.a32, J12.b1, J13.a32, J13.b1, J14.a32, J14.b1, J15.1, J15.50, J16.1, J16.50, J22.4, R1.2, R2.2, R3.2, R4.2, R5.2, R6.2, R7.1, R8.2, R9.1, R10.2, R11.1, R12.2, R13.1, R14.2, R15.2, R16.2, R17.2, R18.2, R19.2, R20.2, R21.1, R22.1, R23.1, R24.1, R25.1, R26.1, R27.2, R28.1, R29.2, R30.2, R31.2, R32.2, R33.2, R34.2, R35.2, R36.2, R37.2, R38.2, R39.2, R40.2, R41.2, R42.2, R43.2, R44.2, R45.2, R46.2, R47.2, R48.2, R49.2, R50.2, R51.2, R52.2, R53.2, R54.1, U1.20 (VCC), U2.20 (VCC), U3.14 (VCC), U4.14 (VCC), U5.14 (VCC), U6.14 (VCC), U7.20 (VCC), U8.20 (VCC), U9.20 (VCC), U10.20 (VCC), U11.20 (VCC), U12.20 (VCC), U13.20 (VCC), U14.20 (VCC), U15.20 (VCC), U16.14 (VCC), U17.20 (VCC), U18.20 (VCC), U19.20 (VCC), U20.20 (VCC), U21.16 (VCC), U22.16 (VCC), U23.16 (VCC), U24.20 (VCC), U25.14 (VCC), X1.14 (Vcc); also elsewhere on the board
+12V: J9.b31, J10.b31, J11.b31, J12.b31, J13.b31, J14.b31, J22.1
/*CAF: J2.a22, J4.a22, J6.a22, J8.a22, J9.a22, J10.a22, J11.a22, J12.a22, J13.a22, J14.a22, U6.11
/*CAF_REQ: J9.b29, J10.b29, J11.b29, J12.b29, J13.b29, J14.b29, R14.1, U6.13
/*CHAN_REQ: J1.a7, J3.a7, J5.a7, J7.a7, R28.2, U22.7 (Za)
/*CHAN_REQ0: J9.b27, R47.1, U20.18 (D7)
/*CHAN_REQ1: J10.b27, R49.1, U20.14 (D5)
/*CHAN_REQ2: J11.b27, R51.1, U20.8 (D3)
/*CHAN_REQ3: J12.b27, R53.1, U20.4 (D1)
/*DEV_REQ: J1.a8, J3.a8, J5.a8, J7.a8, R34.1, U21.14 (GS)
/*DMA_REQ: J1.a6, J3.a6, J5.a6, J7.a6, R29.1, U22.9 (Zb)
/*DMA_REQ0: J9.b26, R46.1, U20.17 (D6)
/*DMA_REQ1: J10.b26, R48.1, U20.13 (D4)
/*DMA_REQ2: J11.b26, R50.1, U20.7 (D2)
/*DMA_REQ3: J12.b26, R52.1, U20.3 (D0)
/*DRQ_GRANT: J1.b21, J3.b21, J5.b21, J7.b21, U16.3, U23.1 (E)
/*DRQ_GRANT0: J9.a25, U23.4 (O0)
/*DRQ_GRANT1: J10.a25, U23.5 (O1)
/*DRQ_GRANT2: J11.a25, U23.6 (O2)
/*DRQ_GRANT3: J12.a25, U23.7 (O3)
/*EXTERNAL: J9.b28, J10.b28, J11.b28, J12.b28, J13.b28, J14.b28, R27.1, U16.1
/*INCREMENT_ZERO: J9.b30, J10.b30, J11.b30, J12.b30, J13.b30, J14.b30, U16.8
/*INT_DETECT: J1.b24, J3.b24, J5.b24, J7.b24, J9.a26, J10.a26, J11.a26, J12.a26, J13.a26, J14.a26
/*INT_REQ: J1.a9, J3.a9, J5.a9, J7.a9, J9.b25, J10.b25, J11.b25, J12.b25, J13.b25, J14.b25, R35.1
/*IORS_FLAG0: J9.b14, J10.b14, J11.b14, J12.b14, J13.b14, J14.b14, R38.1
/*IORS_FLAG1: J9.b15, J10.b15, J11.b15, J12.b15, J13.b15, J14.b15, R39.1
/*IORS_FLAG2: J9.b16, J10.b16, J11.b16, J12.b16, J13.b16, J14.b16, R40.1
/*IORS_FLAG3: J9.b17, J10.b17, J11.b17, J12.b17, J13.b17, J14.b17, R41.1
/*IOT_PULSE: J1.b20, J3.b20, J5.b20, J7.b20, J9.a28, J10.a28, J11.a28, J12.a28, J13.a28, J14.a28
/*IOT_SKIP: J1.a10, J3.a10, J5.a10, J7.a10, J9.b2, J10.b2, J11.b2, J12.b2, J13.b2, J14.b2, R36.1
/*IOT_SKIP_L: J1.a12, J3.a12, J5.a12, J7.a12
/*IOT_WAIT: J1.a11, J3.a11, J5.a11, J7.a11, J9.a31, J10.a31, J11.a31, J12.a31, J13.a31, J14.a31, R37.1
/*JMP_I_DETECT: J1.b23, J3.b23, J5.b23, J7.b23, J9.a27, J10.a27, J11.a27, J12.a27, J13.a27, J14.a27
/*LATCH_AC: J1.a16, J3.a16, J5.a16, J7.a16, J15.33, J16.33
/*LATCH_IR: J1.a13, J3.a13, J5.a13, J7.a13, J15.35, J16.35
/*LATCH_MA: J1.a14, J3.a14, J5.a14, J7.a14, J15.37, J16.37
/*LATCH_MB: J1.a19, J3.a19, J5.a19, J7.a19, J15.34, J16.34
/*LATCH_MQ: J1.a18, J3.a18, J5.a18, J7.a18, J15.32, J16.32
/*LATCH_OB: J1.a21, J3.a21, J5.a21, J7.a21
/*LATCH_PC: J1.a15, J3.a15, J5.a15, J7.a15, J15.36, J16.36
/*LATCH_STEP: J1.a17, J3.a17, J5.a17, J7.a17
/*LATCH_WRTBK: J1.a20, J3.a20, J5.a20, J7.a20, U10.1 (~E), U11.1 (~E), U12.1 (~E)
/*MEMM_ENABLE: J1.a4, J3.a4, J5.a4, J7.a4, J9.b23, J10.b23, J11.b23, J12.b23, J13.b23, J14.b23, J15.44, J16.44, R31.1
/*PI_ENABLE: J1.a3, J3.a3, J5.a3, J7.a3, J9.b22, J10.b22, J11.b22, J12.b22, J13.b22, J14.b22, J15.46, J16.46, R30.1
/*PROT_ENABLE: J1.a5, J3.a5, J5.a5, J7.a5, R32.1
/*PTP_FLAG: J9.b19, J10.b19, J11.b19, J12.b19, J13.b19, J14.b19, R43.1
/*PTP_TAPE: J9.b21, J10.b21, J11.b21, J12.b21, J13.b21, J14.b21, R45.1
/*PTR_FLAG: J9.b18, J10.b18, J11.b18, J12.b18, J13.b18, J14.b18, R42.1
/*PTR_TAPE: J9.b20, J10.b20, J11.b20, J12.b20, J13.b20, J14.b20, R44.1
/*READ_IN_CLEAR: J9.a30, J10.a30, J11.a30, J12.a30, J13.a30, J14.a30, U5.8
/*READ_IN_PULSE: J1.b25, J3.b25, J5.b25, J7.b25, J9.a29, J10.a29, J11.a29, J12.a29, J13.a29, J14.a29, U5.10
/*RESET: J2.a21, J4.a21, J6.a21, J8.a21, J9.a21, J10.a21, J11.a21, J12.a21, J13.a21, J14.a21, U5.11
/*REST_PEND: J2.a28, J4.a28, J6.a28, J8.a28, J9.b24, J10.b24, J11.b24, J12.b24, J13.b24, J14.b24, R33.1
/*SELECT_AC: J1.b12, J3.b12, J5.b12, J7.b12
/*SELECT_ALU: J1.b16, J3.b16, J5.b16, J7.b16
/*SELECT_CORE: J1.b17, J3.b17, J5.b17, J7.b17
/*SELECT_CROSS: J1.b15, J3.b15, J5.b15, J7.b15
/*SELECT_EXTRN: J1.b19, J3.b19, J5.b19, J7.b19, U17.1 (OEa), U17.19 (OEb), U18.1 (OEa), U18.19 (OEb), U19.1 (OEa), U19.19 (OEb)
/*SELECT_MQ: J1.b14, J3.b14, J5.b14, J7.b14
/*SELECT_STEP: J1.b13, J3.b13, J5.b13, J7.b13
/*SELECT_SWR: J1.b18, J3.b18, J5.b18, J7.b18, J15.29, J16.29, U7.1 (A->B), U8.1 (A->B), U9.1 (A->B)
/*WRITE_CORE: J1.a22, J3.a22, J5.a22, J7.a22
/A0: J2.b3, J4.b3, J6.b3, J8.b3, U25.1, U25.2
/A1: J2.b4, J4.b4, J6.b4, J8.b4, U25.4, U25.5
/A2: J2.b5, J4.b5, J6.b5, J8.b5, U25.9, U25.10
/A3: J2.b6, J4.b6, J6.b6, J8.b6
/A4: J2.b7, J4.b7, J6.b7, J8.b7, U24.2 (I0a)
/A5: J2.b8, J4.b8, J6.b8, J8.b8, U24.4 (I1a)
/A6: J2.b9, J4.b9, J6.b9, J8.b9, U24.6 (I2a)
/A7: J2.b10, J4.b10, J6.b10, J8.b10, U24.8 (I3a)
/A8: J2.b11, J4.b11, J6.b11, J8.b11, U24.11 (I0b)
/A9: J2.b12, J4.b12, J6.b12, J8.b12, U24.13 (I1b)
/A10: J2.b13, J4.b13, J6.b13, J8.b13, U24.15 (I2b)
/A11: J2.b14, J4.b14, J6.b14, J8.b14, U24.17 (I3b)
/A12: J2.b15, J4.b15, J6.b15, J8.b15
/A13: J2.b16, J4.b16, J6.b16, J8.b16
/A14: J2.b17, J4.b17, J6.b17, J8.b17
/ADDR_MODE0: J1.b27, J3.b27, J5.b27, J7.b27
/ADDR_MODE1: J1.b28, J3.b28, J5.b28, J7.b28
/ALUO0: J1.a24, J3.a24, J5.a24, J7.a24
/ALUO1: J1.a25, J3.a25, J5.a25, J7.a25
/ALUO2: J1.a26, J3.a26, J5.a26, J7.a26
/ALU_ONES: J1.a30, J3.a30, J5.a30, J7.a30
/ALU_SHIFT: J1.a29, J3.a29, J5.a29, J7.a29
/A_DEVICE0: J9.b3, J10.b3, J11.b3, J12.b3, J13.b3, J14.b3, U24.14 (O2a)
/A_DEVICE1: J9.b4, J10.b4, J11.b4, J12.b4, J13.b4, J14.b4, U24.12 (O3a)
/A_DEVICE2: J9.b5, J10.b5, J11.b5, J12.b5, J13.b5, J14.b5, U24.9 (O0b)
/A_DEVICE3: J9.b6, J10.b6, J11.b6, J12.b6, J13.b6, J14.b6, U24.7 (O1b)
/A_DEVICE4: J9.b7, J10.b7, J11.b7, J12.b7, J13.b7, J14.b7, U24.5 (O2b)
/A_DEVICE5: J9.b8, J10.b8, J11.b8, J12.b8, J13.b8, J14.b8, U24.3 (O3b)
/A_PULSE0: J9.b11, J10.b11, J11.b11, J12.b11, J13.b11, J14.b11, U25.3
/A_PULSE1: J9.b12, J10.b12, J11.b12, J12.b12, J13.b12, J14.b12, U25.6
/A_PULSE2: J9.b13, J10.b13, J11.b13, J12.b13, J13.b13, J14.b13, U25.8
/A_SUBDEV0: J9.b9, J10.b9, J11.b9, J12.b9, J13.b9, J14.b9, U24.18 (O0a)
/A_SUBDEV1: J9.b10, J10.b10, J11.b10, J12.b10, J13.b10, J14.b10, U24.16 (O1a)
/BD0: J15.2, J16.2, U7.18 (B0)
/BD1: J15.3, J16.3, U7.17 (B1)
/BD2: J15.4, J16.4, U7.16 (B2)
/BD3: J15.5, J16.5, U7.15 (B3)
/BD4: J15.6, J16.6, U7.14 (B4)
/BD5: J15.7, J16.7, U7.13 (B5)
/BD6: J15.8, J16.8, U7.12 (B6)
/BD7: J15.9, J16.9, U7.11 (B7)
/BD8: J15.10, J16.10, U8.18 (B0)
/BD9: J15.11, J16.11, U8.17 (B1)
/BD10: J15.12, J16.12, U8.16 (B2)
/BD11: J15.13, J16.13, U8.15 (B3)
/BD12: J15.14, J16.14, U8.14 (B4)
/BD13: J15.15, J16.15, U8.13 (B5)
/BD14: J15.16, J16.16, U8.12 (B6)
/BD15: J15.17, J16.17, U8.11 (B7)
/BD16: J15.18, J16.18, U9.18 (B0)
/BD17: J15.19, J16.19, U9.17 (B1)
/BUS_SELECT0: J1.b9, J3.b9, J5.b9, J7.b9
/BUS_SELECT1: J1.b10, J3.b10, J5.b10, J7.b10
/BUS_SELECT2: J1.b11, J3.b11, J5.b11, J7.b11
/CLK0: J2.a23, U1.9 (O0b)
/CLK1: J4.a23, U1.7 (O1b)
/CLK2: J6.a23, U1.5 (O2b)
/CLK3: J8.a23, U1.3 (O3b)
/CLK4: J9.a23, U2.18 (O0a)
/CLK5: J10.a23, U2.16 (O1a)
/CLK6: J11.a23, U2.14 (O2a)
/CLK7: J12.a23, U2.12 (O3a)
/CLK8: J13.a23, U2.9 (O0b)
/CLK9: J14.a23, U2.7 (O1b)
/CLK10: J15.31, J16.31, U2.5 (O2b), U10.11 (CP), U11.11 (CP), U12.11 (CP), U20.11 (CP)
/CLK11: J15.30, J16.30, U2.3 (O3b)
/CLKSRC: U1.12 (O3a)
/CTL_CONST: J1.b29, J3.b29, J5.b29, J7.b29, U6.9, U16.5
/D0: J2.a3, J4.a3, J6.a3, J8.a3, U7.2 (A0), U10.3 (D0), U17.18 (O0a)
/D1: J2.a4, J4.a4, J6.a4, J8.a4, U7.3 (A1), U10.4 (D1), U17.16 (O1a)
/D2: J2.a5, J4.a5, J6.a5, J8.a5, U7.4 (A2), U10.7 (D2), U17.14 (O2a)
/D3: J2.a6, J4.a6, J6.a6, J8.a6, U7.5 (A3), U10.8 (D3), U17.12 (O3a)
/D4: J2.a7, J4.a7, J6.a7, J8.a7, U7.6 (A4), U10.13 (D4), U17.9 (O0b)
/D5: J2.a8, J4.a8, J6.a8, J8.a8, U7.7 (A5), U10.14 (D5), U17.7 (O1b)
/D6: J2.a9, J4.a9, J6.a9, J8.a9, U7.8 (A6), U10.17 (D6), U17.5 (O2b)
/D7: J2.a10, J4.a10, J6.a10, J8.a10, U7.9 (A7), U10.18 (D7), U17.3 (O3b)
/D8: J2.a11, J4.a11, J6.a11, J8.a11, U8.2 (A0), U11.3 (D0), U18.18 (O0a)
/D9: J2.a12, J4.a12, J6.a12, J8.a12, U8.3 (A1), U11.4 (D1), U18.16 (O1a)
/D10: J2.a13, J4.a13, J6.a13, J8.a13, U8.4 (A2), U11.7 (D2), U18.14 (O2a)
/D11: J2.a14, J4.a14, J6.a14, J8.a14, U8.5 (A3), U11.8 (D3), U18.12 (O3a)
/D12: J2.a15, J4.a15, J6.a15, J8.a15, U8.6 (A4), U11.13 (D4), U18.9 (O0b)
/D13: J2.a16, J4.a16, J6.a16, J8.a16, U8.7 (A5), U11.14 (D5), U18.7 (O1b)
/D14: J2.a17, J4.a17, J6.a17, J8.a17, U8.8 (A6), U11.17 (D6), U18.5 (O2b)
/D15: J2.a18, J4.a18, J6.a18, J8.a18, U8.9 (A7), U11.18 (D7), U18.3 (O3b)
/D16: J2.a19, J4.a19, J6.a19, J8.a19, U9.2 (A0), U12.3 (D0), U19.18 (O0a)
/D17: J2.a20, J4.a20, J6.a20, J8.a20, U9.3 (A1), U12.4 (D1), U19.16 (O1a)
/DELAY_CLK: J15.28, J16.28, U3.3 (C), U3.11 (C), U4.3 (C), U4.11 (C), U5.5
/EXTRA0: J1.b30, J3.b30, J5.b30, J7.b30
/EXTRA1: J2.a24, J4.a24, J6.a24, J8.a24
/EXTRA2: J2.b24, J4.b24, J6.b24, J8.b24
/EXTRA3: J2.a25, J4.a25, J6.a25, J8.a25
/EXTRA4: J2.b25, J4.b25, J6.b25, J8.b25
/EXTRA5: J2.a26, J4.a26, J6.a26, J8.a26
/EXTRA6: J2.b26, J4.b26, J6.b26, J8.b26
/FLAG_AC_SIGN: J1.b8, J3.b8, J5.b8, J7.b8
/FLAG_LINK: J1.b6, J3.b6, J5.b6, J7.b6, J15.47, J16.47
/FLAG_LINK_INIT: J1.b7, J3.b7, J5.b7, J7.b7
/FLAG_SIGN: J1.b5, J3.b5, J5.b5, J7.b5
/FLAG_ZERO: J1.b4, J3.b4, J5.b4, J7.b4, U6.10
/FP0: J2.a29, J4.a29, J6.a29, J8.a29, J15.20, J16.20
/FP1: J2.b29, J4.b29, J6.b29, J8.b29, J15.21, J16.21
/FP2: J2.a30, J4.a30, J6.a30, J8.a30, J15.22, J16.22
/FP3: J2.b30, J4.b30, J6.b30, J8.b30, J15.23, J16.23
/HALT: J1.b26, J3.b26, J5.b26, J7.b26, J15.45, J16.45
/ID0: J9.a3, J10.a3, J11.a3, J12.a3, J13.a3, J14.a3, U13.18 (O0a), U17.2 (I0a)
/ID1: J9.a4, J10.a4, J11.a4, J12.a4, J13.a4, J14.a4, U13.16 (O1a), U17.4 (I1a)
/ID2: J9.a5, J10.a5, J11.a5, J12.a5, J13.a5, J14.a5, U13.14 (O2a), U17.6 (I2a)
/ID3: J9.a6, J10.a6, J11.a6, J12.a6, J13.a6, J14.a6, U13.12 (O3a), U17.8 (I3a)
/ID4: J9.a7, J10.a7, J11.a7, J12.a7, J13.a7, J14.a7, U13.9 (O0b), U17.11 (I0b)
/ID5: J9.a8, J10.a8, J11.a8, J12.a8, J13.a8, J14.a8, U13.7 (O1b), U17.13 (I1b)
/ID6: J9.a9, J10.a9, J11.a9, J12.a9, J13.a9, J14.a9, U13.5 (O2b), U17.15 (I2b)
/ID7: J9.a10, J10.a10, J11.a10, J12.a10, J13.a10, J14.a10, U13.3 (O3b), U17.17 (I3b)
/ID8: J9.a11, J10.a11, J11.a11, J12.a11, J13.a11, J14.a11, U14.18 (O0a), U18.2 (I0a)
/ID9: J9.a12, J10.a12, J11.a12, J12.a12, J13.a12, J14.a12, U14.16 (O1a), U18.4 (I1a)
/ID10: J9.a13, J10.a13, J11.a13, J12.a13, J13.a13, J14.a13, U14.14 (O2a), U18.6 (I2a)
/ID11: J9.a14, J10.a14, J11.a14, J12.a14, J13.a14, J14.a14, U14.12 (O3a), U18.8 (I3a)
/ID12: J9.a15, J10.a15, J11.a15, J12.a15, J13.a15, J14.a15, U14.9 (O0b), U18.11 (I0b)
/ID13: J9.a16, J10.a16, J11.a16, J12.a16, J13.a16, J14.a16, U14.7 (O1b), U18.13 (I1b)
/ID14: J9.a17, J10.a17, J11.a17, J12.a17, J13.a17, J14.a17, U14.5 (O2b), U18.15 (I2b)
/ID15: J9.a18, J10.a18, J11.a18, J12.a18, J13.a18, J14.a18, U14.3 (O3b), U18.17 (I3b)
/ID16: J9.a19, J10.a19, J11.a19, J12.a19, J13.a19, J14.a19, U15.18 (O0a), U19.2 (I0a)
/ID17: J9.a20, J10.a20, J11.a20, J12.a20, J13.a20, J14.a20, U15.16 (O1a), U19.4 (I1a)
/LINKS0: J1.a27, J3.a27, J5.a27, J7.a27
/LINKS1: J1.a28, J3.a28, J5.a28, J7.a28
/MA_AUTO_INX: J2.b28, J4.b28, J6.b28, J8.b28
/NEXT_BANK0: J2.a27, J4.a27, J6.a27, J8.a27, J15.49, J16.49
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

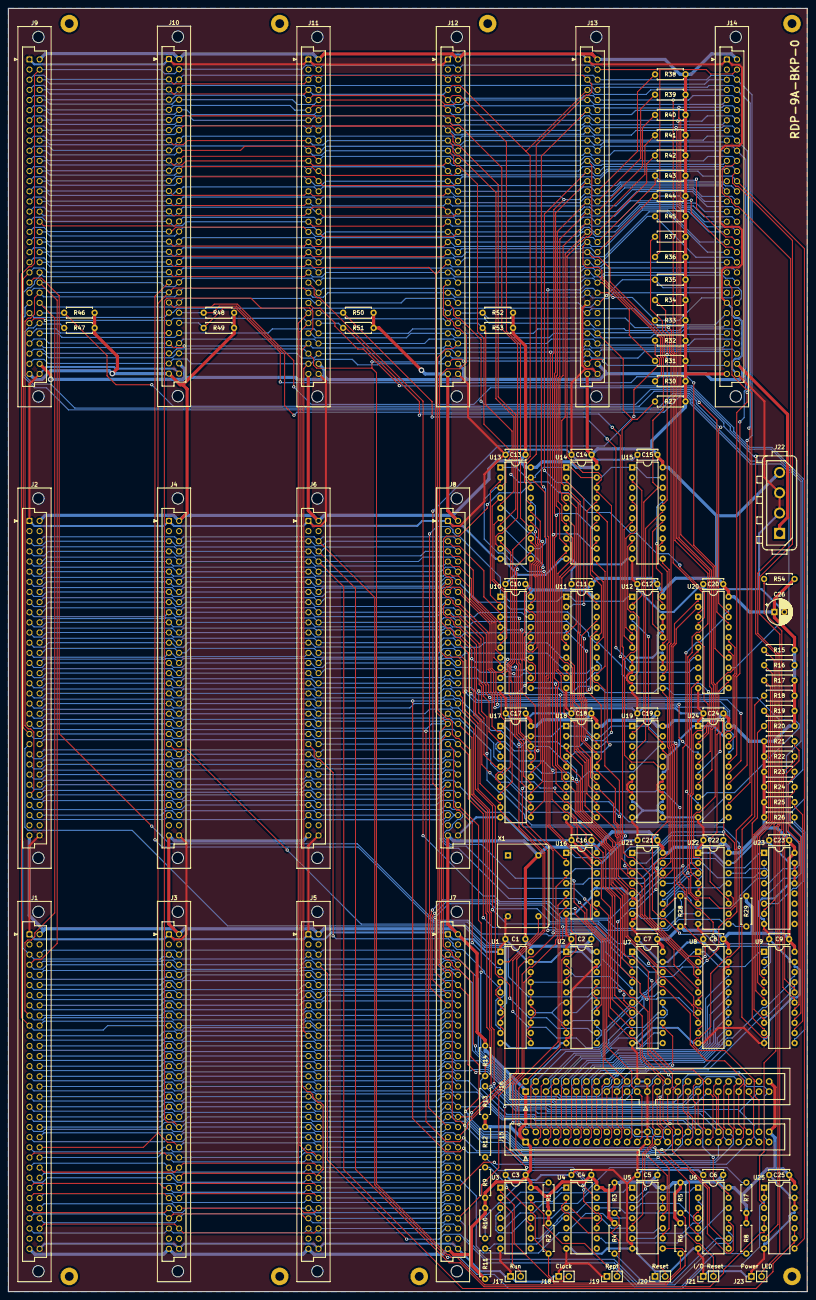
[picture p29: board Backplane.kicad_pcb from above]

Board: 2 copper layers, 200.0 x 321.3 mm, 137 parts (0 on the bottom side), 274 nets.

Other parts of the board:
C26: 100 uF; CP_Radial_D6.3mm_P2.50mm
H5, H6, H7, H8: MountingHole; MountingHole_2.2mm_M2_Pad

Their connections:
+5V: C26.1; also elsewhere on the board
GND: C26.2; also elsewhere on the board

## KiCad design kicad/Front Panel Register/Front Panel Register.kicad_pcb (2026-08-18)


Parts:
C1, C2, C3, C4, C5, C6, C7, C8, C9, C10, C11, C12: 0.1uF; C_Disc_D5.0mm_W2.5mm_P5.00mm
C20: 100 uF; CP_Radial_D6.3mm_P2.50mm
D1: MB0; LED_D5.0mm
D2: MB1; LED_D5.0mm
D3: MB2; LED_D5.0mm
D4: MB4; LED_D5.0mm
D5: MB3; LED_D5.0mm
D6: MB6; LED_D5.0mm
D7: MB5; LED_D5.0mm
D8: MB8; LED_D5.0mm
D9: MB7; LED_D5.0mm
D10: MB9; LED_D5.0mm
D11: MB10; LED_D5.0mm
D12: MB11; LED_D5.0mm
D13: MB12; LED_D5.0mm
D14: MB13; LED_D5.0mm
D15: MB14; LED_D5.0mm
D16: MB15; LED_D5.0mm
D17: MB16; LED_D5.0mm
D18: MB17; LED_D5.0mm
D19: AC0; LED_D5.0mm
D20: AC1; LED_D5.0mm
D21: AC2; LED_D5.0mm
D22: AC3; LED_D5.0mm
D23: AC4; LED_D5.0mm
D24: AC5; LED_D5.0mm
D25: AC6; LED_D5.0mm
D26: AC7; LED_D5.0mm
D27: AC8; LED_D5.0mm
D28: AC9; LED_D5.0mm
D29: AC10; LED_D5.0mm
D30: AC11; LED_D5.0mm
D31: AC12; LED_D5.0mm
D32: AC13; LED_D5.0mm
D33: AC14; LED_D5.0mm
D34: AC15; LED_D5.0mm
D35: AC16; LED_D5.0mm
D36: AC17; LED_D5.0mm
D37: MQ0; LED_D5.0mm
D38: MQ1; LED_D5.0mm
D39: MQ2; LED_D5.0mm
D40: MQ3; LED_D5.0mm
D41: MQ4; LED_D5.0mm
D42: MQ5; LED_D5.0mm
D43: MQ6; LED_D5.0mm
D44: MQ7; LED_D5.0mm
D45: MQ8; LED_D5.0mm
D46: MQ9; LED_D5.0mm
D47: MQ10; LED_D5.0mm
D48: MQ11; LED_D5.0mm
D49: MQ12; LED_D5.0mm
D50: MQ13; LED_D5.0mm
D51: MQ14; LED_D5.0mm
D52: MQ15; LED_D5.0mm
D53: MQ16; LED_D5.0mm
D54: MQ17; LED_D5.0mm
H1, H2, H3, H4: MountingHole; MountingHole_2.2mm_M2_Pad
J1: Front Panel Connector; IDC-Header_2x25_P2.54mm_Vertical
R1, R2, R3, R4, R5, R6, R7, R8, R9, R10, R11, R12, R13, R14, R15, R16, R17, R18: 4.7K; R_Axial_DIN0207_L6.3mm_D2.5mm_P7.62mm_Horizontal
RN1, RN2, RN3, RN4, RN5, RN6, RN7, RN8, RN9, RN10, RN11: 330R; R_Array_SIP6
SW1: SWR0; MTS-102
SW2: SWR1; MTS-102
SW3: SWR2; MTS-102
SW4: SWR3; MTS-102
SW5: SWR4; MTS-102
SW6: SWR5; MTS-102
SW7: SWR6; MTS-102
SW8: SWR7; MTS-102
SW9: SWR8; MTS-102
SW10: SWR9; MTS-102
SW11: SWR10; MTS-102
SW12: SWR11; MTS-102
SW13: SWR12; MTS-102
SW14: SWR13; MTS-102
SW15: SWR14; MTS-102
SW16: SWR15; MTS-102
SW17: SWR16; MTS-102
SW18: SWR17; MTS-102
U1, U2, U3: 74LS244; DIP-20_W7.62mm
U4, U5, U6, U7, U8, U9, U10, U11, U12: 74LS377; DIP-20_W7.62mm

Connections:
+5V: C1.1, C2.1, C3.1, C4.1, C5.1, C6.1, C7.1, C8.1, C9.1, C10.1, C11.1, C12.1, J1.1, J1.50, R1.2, R2.2, R3.2, R4.2, R5.2, R6.2, R7.2, R8.2, R9.2, R10.2, R11.2, R12.2, R13.2, R14.2, R15.2, R16.2, R17.2, R18.2, U1.20 (VCC), U2.20 (VCC), U3.20 (VCC), U4.20 (VCC), U5.20 (VCC), U6.20 (VCC), U7.20 (VCC), U8.20 (VCC), U9.20 (VCC), U10.20 (VCC), U11.20 (VCC), U12.20 (VCC); also elsewhere on the board
/*LATCH_AC: J1.33, U7.1 (~E), U8.1 (~E), U9.1 (~E)
/*LATCH_IR: J1.35
/*LATCH_MA: J1.37
/*LATCH_MB: J1.34, U4.1 (~E), U5.1 (~E), U6.1 (~E)
/*LATCH_MQ: J1.32, U10.1 (~E), U11.1 (~E), U12.1 (~E)
/*LATCH_PC: J1.36
/*MEMM_ENABLE: J1.44
/*PI_ENABLE: J1.46
/*SELECT_SWR: J1.29, U1.1 (OEa), U1.19 (OEb), U2.1 (OEa), U2.19 (OEb), U3.1 (OEa), U3.19 (OEb)
/CLK_A: J1.31
/CLK_B: J1.30, U4.11 (CP), U5.11 (CP), U6.11 (CP), U7.11 (CP), U8.11 (CP), U9.11 (CP), U10.11 (CP), U11.11 (CP), U12.11 (CP)
/D0: J1.2, U1.18 (O0a), U4.3 (D0), U7.3 (D0), U10.3 (D0)
/D1: J1.3, U1.16 (O1a), U4.4 (D1), U7.4 (D1), U10.4 (D1)
/D2: J1.4, U1.14 (O2a), U4.7 (D2), U7.7 (D2), U10.7 (D2)
/D3: J1.5, U1.12 (O3a), U4.8 (D3), U7.8 (D3), U10.8 (D3)
/D4: J1.6, U1.9 (O0b), U4.13 (D4), U7.13 (D4), U10.13 (D4)
/D5: J1.7, U1.7 (O1b), U4.14 (D5), U7.14 (D5), U10.14 (D5)
/D6: J1.8, U1.3 (O3b), U1.5 (O2b), U4.17 (D6), U7.17 (D6), U10.17 (D6)
/D7: J1.9, U4.18 (D7), U7.18 (D7), U10.18 (D7)
/D8: J1.10, U2.18 (O0a), U5.3 (D0), U8.3 (D0), U11.3 (D0)
/D9: J1.11, U2.16 (O1a), U5.4 (D1), U8.4 (D1), U11.4 (D1)
/D10: J1.12, U2.14 (O2a), U5.7 (D2), U8.7 (D2), U11.7 (D2)
/D11: J1.13, U2.12 (O3a), U5.8 (D3), U8.8 (D3), U11.8 (D3)
/D12: J1.14, U2.9 (O0b), U5.13 (D4), U8.13 (D4), U11.13 (D4)
/D13: J1.15, U2.7 (O1b), U5.14 (D5), U8.14 (D5), U11.14 (D5)
/D14: J1.16, U2.5 (O2b), U5.17 (D6), U8.17 (D6), U11.17 (D6)
/D15: J1.17, U2.3 (O3b), U5.18 (D7), U8.18 (D7), U11.18 (D7)
/D16: J1.18, U3.18 (O0a), U6.3 (D0), U9.3 (D0), U12.3 (D0)
/D17: J1.19, U3.16 (O1a), U6.4 (D1), U9.4 (D1), U12.4 (D1)
/DELAY_CLK: J1.28
/FLAG_LINK: J1.47
/FP0: J1.20
/FP1: J1.21
/FP2: J1.22
/FP3: J1.23
/HALT: J1.45
/NEXT_BANK0: J1.49
/NEXT_BANK1: J1.48
/SC0: J1.43
/SC1: J1.42
/SC2: J1.41
/SC3: J1.40
/SC4: J1.39
/SC5: J1.38
/SYNC_CLK: J1.27
GND: C1.2, C2.2, C3.2, C4.2, C5.2, C6.2, C7.2, C8.2, C9.2, C10.2, C11.2, C12.2, J1.24, J1.25, J1.26, RN1.1 (common), RN2.1 (common), RN3.1 (common), RN4.1 (common), RN5.1 (common), RN6.1 (common), RN7.1 (common), RN8.1 (common), RN9.1 (common), RN10.1 (common), RN11.1 (common), SW1.1 (A), SW2.1 (A), SW3.1 (A), SW4.1 (A), SW5.1 (A), SW6.1 (A), SW7.1 (A), SW8.1 (A), SW9.1 (A), SW10.1 (A), SW11.1 (A), SW12.1 (A), SW13.1 (A), SW14.1 (A), SW15.1 (A), SW16.1 (A), SW17.1 (A), SW18.1 (A), U1.10 (GND), U2.10 (GND), U3.6 (I2a), U3.8 (I3a), U3.10 (GND), U3.11 (I0b), U3.13 (I1b), U3.15 (I2b), U3.17 (I3b), U4.10 (GND), U5.10 (GND), U6.7 (D2), U6.8 (D3), U6.10 (GND), U6.13 (D4), U6.14 (D5), U6.17 (D6), U6.18 (D7), U7.10 (GND), U8.10 (GND), U9.7 (D2), U9.8 (D3), U9.10 (GND), U9.13 (D4), U9.14 (D5), U9.17 (D6), U9.18 (D7), U10.10 (GND), U11.10 (GND), U12.7 (D2), U12.8 (D3), U12.10 (GND), U12.13 (D4), U12.14 (D5), U12.17 (D6), U12.18 (D7); also elsewhere on the board
unnamed: D1.2 (A), U4.2 (Q0)
unnamed: D1.1 (K), RN1.2 (R1)
unnamed: D2.2 (A), U4.5 (Q1)
unnamed: D2.1 (K), RN1.3 (R2)
unnamed: D3.2 (A), U4.6 (Q2)
unnamed: D3.1 (K), RN1.4 (R3)
unnamed: D4.2 (A), U4.12 (Q4)
unnamed: D4.1 (K), RN1.6 (R5)
unnamed: D5.2 (A), U4.9 (Q3)
unnamed: D5.1 (K), RN1.5 (R4)
unnamed: D6.2 (A), U4.16 (Q6)
unnamed: D6.1 (K), RN2.3 (R2)
unnamed: D7.2 (A), U4.15 (Q5)
unnamed: D7.1 (K), RN2.2 (R1)
unnamed: D8.2 (A), U5.2 (Q0)
unnamed: D8.1 (K), RN2.5 (R4)
unnamed: D9.2 (A), U4.19 (Q7)
unnamed: D9.1 (K), RN2.4 (R3)
unnamed: D10.2 (A), U5.5 (Q1)
unnamed: D10.1 (K), RN2.6 (R5)
unnamed: D11.2 (A), U5.6 (Q2)
unnamed: D11.1 (K), RN3.2 (R1)
unnamed: D12.2 (A), U5.9 (Q3)
unnamed: D12.1 (K), RN3.3 (R2)
unnamed: D13.2 (A), U5.12 (Q4)
unnamed: D13.1 (K), RN3.4 (R3)
unnamed: D14.2 (A), U5.15 (Q5)
unnamed: D14.1 (K), RN3.5 (R4)
unnamed: D15.2 (A), U5.16 (Q6)
unnamed: D15.1 (K), RN3.6 (R5)
unnamed: D16.2 (A), U5.19 (Q7)
unnamed: D16.1 (K), RN4.2 (R1)
unnamed: D17.2 (A), U6.2 (Q0)
unnamed: D17.1 (K), RN4.3 (R2)
unnamed: D18.2 (A), U6.5 (Q1)
unnamed: D18.1 (K), RN4.4 (R3)
unnamed: D19.2 (A), U7.2 (Q0)
unnamed: D19.1 (K), RN5.2 (R1)
unnamed: D20.2 (A), U7.5 (Q1)
unnamed: D20.1 (K), RN5.3 (R2)
unnamed: D21.2 (A), U7.6 (Q2)
unnamed: D21.1 (K), RN5.4 (R3)
unnamed: D22.2 (A), U7.9 (Q3)
unnamed: D22.1 (K), RN5.5 (R4)
unnamed: D23.2 (A), U7.12 (Q4)
unnamed: D23.1 (K), RN5.6 (R5)
unnamed: D24.2 (A), U7.15 (Q5)
unnamed: D24.1 (K), RN6.2 (R1)
unnamed: D25.2 (A), U7.16 (Q6)
unnamed: D25.1 (K), RN6.3 (R2)
unnamed: D26.2 (A), U7.19 (Q7)
unnamed: D26.1 (K), RN6.4 (R3)
unnamed: D27.2 (A), U8.2 (Q0)
unnamed: D27.1 (K), RN6.5 (R4)
unnamed: D28.2 (A), U8.5 (Q1)
unnamed: D28.1 (K), RN6.6 (R5)
unnamed: D29.2 (A), U8.6 (Q2)
unnamed: D29.1 (K), RN7.2 (R1)
unnamed: D30.2 (A), U8.9 (Q3)
unnamed: D30.1 (K), RN7.3 (R2)
unnamed: D31.2 (A), U8.12 (Q4)
unnamed: D31.1 (K), RN7.4 (R3)
unnamed: D32.2 (A), U8.15 (Q5)
unnamed: D32.1 (K), RN7.5 (R4)
unnamed: D33.2 (A), U8.16 (Q6)
unnamed: D33.1 (K), RN7.6 (R5)
unnamed: D34.2 (A), U8.19 (Q7)
unnamed: D34.1 (K), RN8.2 (R1)
unnamed: D35.2 (A), U9.2 (Q0)
unnamed: D35.1 (K), RN8.3 (R2)
unnamed: D36.2 (A), U9.5 (Q1)
unnamed: D36.1 (K), RN8.4 (R3)
unnamed: D37.2 (A), U10.2 (Q0)
unnamed: D37.1 (K), RN9.2 (R1)
unnamed: D38.2 (A), U10.5 (Q1)
unnamed: D38.1 (K), RN9.3 (R2)
unnamed: D39.2 (A), U10.6 (Q2)
unnamed: D39.1 (K), RN9.4 (R3)
unnamed: D40.2 (A), U10.9 (Q3)
unnamed: D40.1 (K), RN9.5 (R4)
unnamed: D41.2 (A), U10.12 (Q4)
unnamed: D41.1 (K), RN9.6 (R5)
unnamed: D42.2 (A), U10.15 (Q5)
unnamed: D42.1 (K), RN10.2 (R1)
unnamed: D43.2 (A), U10.16 (Q6)
unnamed: D43.1 (K), RN10.3 (R2)
unnamed: D44.2 (A), U10.19 (Q7)
unnamed: D44.1 (K), RN10.4 (R3)
unnamed: D45.2 (A), U11.2 (Q0)
unnamed: D45.1 (K), RN10.5 (R4)
unnamed: D46.2 (A), U11.5 (Q1)
unnamed: D46.1 (K), RN10.6 (R5)
unnamed: D47.2 (A), U11.6 (Q2)
unnamed: D47.1 (K), RN11.2 (R1)
unnamed: D48.2 (A), U11.9 (Q3)
unnamed: D48.1 (K), RN11.3 (R2)
unnamed: D49.2 (A), U11.12 (Q4)
unnamed: D49.1 (K), RN11.4 (R3)
unnamed: D50.2 (A), U11.15 (Q5)
unnamed: D50.1 (K), RN11.5 (R4)
unnamed: D51.2 (A), U11.16 (Q6)
unnamed: D51.1 (K), RN11.6 (R5)
unnamed: D52.2 (A), U11.19 (Q7)
unnamed: D52.1 (K), RN4.5 (R4)
unnamed: D53.2 (A), U12.2 (Q0)
unnamed: D53.1 (K), RN8.6 (R5)
unnamed: D54.2 (A), U12.5 (Q1)
unnamed: D54.1 (K), RN8.5 (R4)
unnamed: R1.1, SW1.2 (B), U1.2 (I0a)
unnamed: R2.1, SW2.2 (B), U1.4 (I1a)
unnamed: R3.1, SW3.2 (B), U1.6 (I2a)
unnamed: R4.1, SW4.2 (B), U1.8 (I3a)
unnamed: R5.1, SW5.2 (B), U1.11 (I0b)
unnamed: R6.1, SW6.2 (B), U1.13 (I1b)
unnamed: R7.1, SW7.2 (B), U1.15 (I2b)
unnamed: R8.1, SW8.2 (B), U1.17 (I3b)
unnamed: R9.1, SW9.2 (B), U2.2 (I0a)
unnamed: R10.1, SW10.2 (B), U2.4 (I1a)
unnamed: R11.1, SW11.2 (B), U2.6 (I2a)
unnamed: R12.1, SW12.2 (B), U2.8 (I3a)
unnamed: R13.1, SW13.2 (B), U2.11 (I0b)
unnamed: R14.1, SW14.2 (B), U2.13 (I1b)
unnamed: R15.1, SW15.2 (B), U2.15 (I2b)
unnamed: R16.1, SW16.2 (B), U2.17 (I3b)
unnamed: R17.1, SW17.2 (B), U3.2 (I0a)
unnamed: R18.1, SW18.2 (B), U3.4 (I1a)



Board: 2 copper layers, 204.5 x 107.3 mm, 131 parts (2 on the bottom side), 151 nets.

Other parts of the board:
C13: 100 uF; CP_Radial_D6.3mm_P2.50mm

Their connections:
+5V: C13.1; also elsewhere on the board
GND: C13.2; also elsewhere on the board

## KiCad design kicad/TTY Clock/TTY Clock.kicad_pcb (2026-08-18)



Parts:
C1, C2, C3, C4: 1.0 uF; CP_Radial_D5.0mm_P2.00mm
C5, C6, C7, C8, C9, C10, C11, C12, C13, C14, C15, C16, C17, C18, C19, C21, C22, C23, C24, C25, C26, C27, C28, C29, C30, C31, C32, C33, C34, C35, C36, C37, C38, C39, C40, C41, C43: 0.1uF; C_Disc_D5.0mm_W2.5mm_P5.00mm
C20: 100 uF; CP_Radial_D6.3mm_P2.50mm
J1: I/O Connector; DIN41612_B_2x32_Male_Horizontal_THT
J2: Custom Clock; PinHeader_1x04_P2.54mm_Horizontal
J3: TTL Serial 0; PinHeader_1x06_P2.54mm_Horizontal
J4: TTL Serial 1; PinHeader_1x06_P2.54mm_Horizontal
J5: RS232 Serial 0; IDC-Header_2x05_P2.54mm_Horizontal
J6: RS232 Serial 1; IDC-Header_2x05_P2.54mm_Horizontal
JP1: RX0 Select; PinHeader_1x03_P2.54mm_Vertical
JP2: RX1 Select; PinHeader_1x03_P2.54mm_Vertical
JP3: TRNS1 INT; PinHeader_1x03_P2.54mm_Vertical
JP4: RECV1 INT; PinHeader_1x03_P2.54mm_Vertical
R1, R2, R3, R4, R5, R6, R7, R8, R9, R10, R11, R12, R13, R14, R15, R16, R17, R18, R19: 4.7K; R_Axial_DIN0207_L6.3mm_D2.5mm_P7.62mm_Horizontal
RN1, RN2, RN3, RN4: 4.7K; R_Array_SIP9
SW1: IORS 0 Settings; SW_DIP_SPSTx08_Slide_9.78x22.5mm_W7.62mm_P2.54mm
SW2: IORS 1 Settings; SW_DIP_SPSTx08_Slide_9.78x22.5mm_W7.62mm_P2.54mm
SW3: IORS 2 Settings; SW_DIP_SPSTx08_Slide_9.78x22.5mm_W7.62mm_P2.54mm
SW4: IORS 3 Settings; SW_DIP_SPSTx08_Slide_9.78x22.5mm_W7.62mm_P2.54mm
SW5: UART 0 Settings; SW_DIP_SPSTx08_Slide_9.78x22.5mm_W7.62mm_P2.54mm
SW6: UART 1 Settings; SW_DIP_SPSTx08_Slide_9.78x22.5mm_W7.62mm_P2.54mm
U1, U6, U12, U13, U23, U25, U29: 74LS32; DIP-14_W7.62mm
U2: 74LS04; DIP-14_W7.62mm
U3, U37: 74LS08; DIP-14_W7.62mm
U4, U7, U14: 74LS240; DIP-20_W7.62mm
U5, U20: 74LS02; DIP-14_W7.62mm
U8, U9: 74LS138; DIP-16_W7.62mm
U10, U36: 74LS06; DIP-14_W7.62mm
U11: 74LS00; DIP-14_W7.62mm
U15, U17, U21, U30, U31: 74LS74; DIP-14_W7.62mm
U16, U19, U24, U26: 74LS169; DIP-16_W7.62mm
U18, U22: 74LS244; DIP-20_W7.62mm
U27, U28: 74LS151; DIP-16_W7.62mm
U32, U33: TR1863; DIP-40_W15.24mm
U34: 74LS257; DIP-16_W7.62mm
U35: MAX232; DIP-16_W7.62mm
X1: 2.4576 Mhz Oscillator; Oscillator_DIP-14

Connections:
+5V: C2.2, C5.1, C6.1, C7.1, C8.1, C9.1, C10.1, C11.1, C12.1, C13.1, C14.1, C15.1, C16.1, C17.1, C18.1, C19.1, C20.1, C21.1, C22.1, C23.1, C24.1, C25.1, C26.1, C27.1, C28.1, C29.1, C30.1, C31.1, C32.1, C33.1, C34.1, C35.1, C36.1, C37.1, C38.1, C39.1, C40.1, C41.1, C43.1, J1.a32, J1.b1, J2.1, R1.1, R2.1, R3.1, R4.1, R5.1, R6.1, R7.1, R8.1, R9.1, R10.2, R11.1, R12.1, R13.1, R14.1, R15.1, R16.1, R17.1, R18.1, R19.1, RN1.1 (common), RN2.1 (common), RN3.1 (common), RN4.1 (common), U1.14 (VCC), U2.14 (VCC), U3.14 (VCC), U4.20 (VCC), U5.14 (VCC), U6.14 (VCC), U7.20 (VCC), U8.16 (VCC), U9.16 (VCC), U10.14 (VCC), U11.14 (VCC), U12.14 (VCC), U13.14 (VCC), U14.20 (VCC), U15.14 (VCC), U16.16 (VCC), U17.14 (VCC), U18.20 (VCC), U19.16 (VCC), U20.14 (VCC), U21.14 (VCC), U22.20 (VCC), U23.14 (VCC), U24.16 (VCC), U25.14 (VCC), U26.16 (VCC), U27.16 (VCC), U28.16 (VCC), U29.14 (VCC), U30.14 (VCC), U31.14 (VCC), U32.1 (VCC), U32.34 (CRL), U33.1 (VCC), U33.34 (CRL), U34.16 (VCC), U35.16 (VCC), U36.14 (VCC), U37.14 (VCC), X1.14 (Vcc); also elsewhere on the board
/60_HZ: U11.3, U26.9 (~PE), U29.13
/*API_EN: U5.11, U12.11, U13.4, U13.9
/*A_PULSE0: U2.2, U5.3, U5.6, U5.9, U5.12, U20.3
/*A_PULSE1: U2.4, U3.9, U6.2, U6.10, U6.13, U13.5
/*A_PULSE2: U1.13, U2.6, U3.10, U6.5, U13.2, U13.10, U17.12 (D)
/*A_PULSE12: U3.8, U13.13
/*A_SUBDEV1: U1.10, U2.10, U25.9, U25.13, U29.2
/*CAF: J1.a22, U2.9, U3.2, U37.4, U37.9
/*CAF_REQ: J1.b29, U13.6
/*DRQ_GRANT: J1.a25, U1.4, U15.10 (~S), U18.1 (OEa), U18.19 (OEb), U37.1
/*EMIR_SET: U1.8, U21.4 (~S)
/*EXTERNAL: J1.b28, U10.2
/*INCREMENT_ZERO: J1.b30, U1.5
/*INT_DETECT: J1.a26, U15.1 (~R)
/*INT_REQ: J1.b25, U36.2, U36.4, U36.6, U36.8, U36.10
/*IORS_FLAG0: J1.b14, SW1.9, SW1.10, SW1.11, SW1.12, SW1.13, SW1.14, SW1.15, SW1.16
/*IORS_FLAG1: J1.b15, SW2.9, SW2.10, SW2.11, SW2.12, SW2.13, SW2.14, SW2.15, SW2.16
/*IORS_FLAG2: J1.b16, SW3.9, SW3.10, SW3.11, SW3.12, SW3.13, SW3.14, SW3.15, SW3.16
/*IORS_FLAG3: J1.b17, SW4.9, SW4.10, SW4.11, SW4.12, SW4.13, SW4.14, SW4.15, SW4.16
/*IOT_PULSE: J1.a28, U8.4 (E1), U9.4 (E1)
/*IOT_SKIP: J1.b2, U10.4, U10.6, U10.8, U10.10, U10.12
/*IOT_WAIT: J1.a31
/*JMP_I_DETECT: J1.a27, U17.3 (C), U21.3 (C), U23.1, U29.4
/*KEYBD_EN: U1.12, U5.5, U6.9, U12.6
/*KEYBD_RD: U6.8, U25.2, U25.10, U37.2
/*MEMM_ENABLE: J1.b23, U17.8 (~Q)
/*MEMM_SET: U13.11, U17.11 (C)
/*MEM_EN: U1.3, U1.9, U13.12, U20.2
/*PI_ENABLE: J1.b22, U14.4 (I1a), U15.6 (~Q)
/*PI_SET: U6.3, U15.3 (C)
/*PRINT_EN: U5.8, U6.12, U12.8, U13.1
/*PRINT_RES: U6.11, U37.5, U37.10
/*PRINT_WR: U13.3, U25.4, U25.12
/*PTP_FLAG: J1.b19, U7.17 (I3b)
/*PTP_TAPE: J1.b21, U7.2 (I0a)
/*PTR_FLAG: J1.b18, U14.2 (I0a)
/*PTR_TAPE: J1.b20, U7.4 (I1a)
/*READ_IN_CLEAR: J1.a30
/*READ_IN_PULSE: J1.a29
/*RESET: J1.a21, U31.1 (~R)
/*REST_PEND: J1.b24, U17.6 (~Q), U29.5
/*RTC_EN: U5.2, U6.1, U6.4, U12.3
/*RTC_ENABLE: U7.6 (I2a), U29.12, U31.6 (~Q)
/*RTC_FLAG: U7.8 (I3a), U31.8 (~Q)
/*RTC_PENDING: J1.b26, J1.b27, U15.9 (Q)
/*SET_RTC_EN: U3.1, U6.6, U31.3 (C)
/*TRNS_FLAG_0: U7.13 (I1b), U30.6 (~Q)
/A_DEVICE0: J1.b3, U8.1 (A0)
/A_DEVICE1: J1.b4, U8.2 (A1)
/A_DEVICE2: J1.b5, U8.3 (A2)
/A_DEVICE3: J1.b6, U9.1 (A0)
/A_DEVICE4: J1.b7, U9.2 (A1)
/A_DEVICE5: J1.b8, U9.3 (A2)
/A_PULSE0: J1.b11, U2.1
/A_PULSE1: J1.b12, U2.3
/A_PULSE2: J1.b13, U2.5
/A_SUBDEV0: J1.b9
/A_SUBDEV1: J1.b10, U2.11, U15.2 (D), U25.1, U25.5, U31.2 (D), U34.1 (S)
/CAF: U2.8, U32.21 (MR), U33.21 (MR)
/CLK: J1.a23
/D0: J1.a3, U4.18 (O0a), U18.18 (O0a), U32.12 (RR1), U32.26 (TR1), U33.12 (RR1), U33.26 (TR1)
/D1: J1.a4, U4.16 (O1a), U18.16 (O1a), U32.11 (RR2), U32.27 (TR2), U33.11 (RR2), U33.27 (TR2)
/D2: J1.a5, U4.14 (O2a), U18.14 (O2a), U32.10 (RR3), U32.28 (TR3), U33.10 (RR3), U33.28 (TR3)
/D3: J1.a6, U4.12 (O3a), U18.12 (O3a), U32.9 (RR4), U32.29 (TR4), U33.9 (RR4), U33.29 (TR4)
/D4: J1.a7, U4.9 (O0b), U18.9 (O0b), U32.8 (RR5), U32.30 (TR5), U33.8 (RR5), U33.30 (TR5)
/D5: J1.a8, U4.7 (O1b), U18.7 (O1b), U32.7 (RR6), U32.31 (TR6), U33.7 (RR6), U33.31 (TR6)
/D6: J1.a9, U4.5 (O2b), U18.5 (O2b), U32.6 (RR7), U32.32 (TR7), U33.6 (RR7), U33.32 (TR7)
/D7: J1.a10, U4.3 (O3b), U18.3 (O3b), U32.5 (RR8), U32.33 (TR8), U33.5 (RR8), U33.33 (TR8)
/D8: J1.a11, U7.18 (O0a), U22.18 (O0a)
/D9: J1.a12, U7.16 (O1a), U22.16 (O1a)
/D10: J1.a13, U7.14 (O2a), U22.14 (O2a)
/D11: J1.a14, U7.12 (O3a), U22.12 (O3a)
/D12: J1.a15, U7.9 (O0b), U22.9 (O0b)
/D13: J1.a16, U7.7 (O1b), U22.7 (O1b)
/D14: J1.a17, U7.5 (O2b), U22.5 (O2b)
/D15: J1.a18, U7.3 (O3b), U22.3 (O3b)
/D16: J1.a19, U14.9 (O0b), U14.18 (O0a), U23.12
/D17: J1.a20, U14.7 (O1b), U14.16 (O1a)
/EMIR_PEND: U20.11, U21.5 (Q)
/IORS0: RN1.9 (R8), SW1.1, SW2.1, SW3.1, SW4.1, U4.2 (I0a)
/IORS1: RN1.8 (R7), SW1.2, SW2.2, SW3.2, SW4.2, U4.4 (I1a)
/IORS2: RN1.7 (R6), SW1.3, SW2.3, SW3.3, SW4.3, U4.6 (I2a)
/IORS3: RN1.6 (R5), SW1.4, SW2.4, SW3.4, SW4.4, U4.8 (I3a)
/IORS4: RN1.5 (R4), SW1.5, SW2.5, SW3.5, SW4.5, U4.11 (I0b)
/IORS5: RN1.4 (R3), SW1.6, SW2.6, SW3.6, SW4.6, U4.13 (I1b)
/IORS6: RN1.3 (R2), SW1.7, SW2.7, SW3.7, SW4.7, U4.15 (I2b)
/IORS7: RN1.2 (R1), SW1.8, SW2.8, SW3.8, U4.17 (I3b)
/KEYBD_SKIP: U5.4, U11.5
/MEMM_ENABLE: U3.13, U17.9 (Q)
/PRINT_SKIP: U5.10, U11.13
/RECV_FLAG_0: U32.19 (DR), U34.2 (I0a), U36.5, U36.13
/RECV_FLAG_1: JP4.1 (A), U33.19 (DR), U34.3 (I1a)
/REQ_ADDR: J1.a24
/REST_PEND: U17.5 (Q), U20.12
/RTC_FLAG: U3.4, U31.9 (Q), U36.1
/TRNS_FLAG_0: U30.5 (Q), U34.5 (I0b), U36.3
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

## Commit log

2025-05-05 Add switch register logic
2025-05-11 Continue work on stage 1 of OPR
2025-05-17 Fix OPR skip conditions and add control switches
2025-05-20 Implement state logic for front panel switches
2025-05-21 Lock switch update to 60hz timer
2025-05-22 Add button press logic
2025-05-30 Start work on paper tape mounting
2025-06-01 Add run tape button
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2026-01-29 Wire IO latching and prop to CPU
2026-02-02 Fix all sorts of bugs and add back TTY printer support
2026-02-03 Start work on device request logic
2026-02-04 Continue work on device request logic
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2026-02-06 Add interrupt and memm flags to IO subsystem
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2026-02-11 Migrate IO device logic to new IOT strategy
2026-02-18 Wire in RTC to DRQ subsystem and debug
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2026-06-08 Continue work on RB emulation and fix DMA bug
2026-06-10 Start working on ALU schematic
    [ALU.kicad_pcb, ALU.kicad_sch]
2026-06-12 Continue ALU work
    [ALU.kicad_sch]
2026-06-13 Implement ALU arithmetic support logic
    [ALU.kicad_sch]
2026-06-13 Implement OB zero flag logic
    [ALU.kicad_sch]
2026-06-15 Start work on control board
    [ALU.kicad_sch, Control.kicad_pcb, Control.kicad_sch]
2026-06-16 Start migrating over to DIN41612 connectors
    [ALU.kicad_sch, Control.kicad_sch]
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2026-06-23 Continue connector migration
    [ALU.kicad_sch]
2026-06-27 Fix electrical rule issues
    [ALU.kicad_sch]
2026-06-28 Rework CAF and continue control board schematic
    [Control.kicad_pcb, Control.kicad_sch]
2026-06-28 Finish control logic
    [ALU.kicad_sch, Control.kicad_sch]
2026-06-29 Start work on register file
    [Registers.kicad_pcb, Registers.kicad_sch]
2026-06-30 Continue work on register file
    [Control.kicad_sch, Registers.kicad_sch]
2026-07-01 Finish register file
    [Registers.kicad_sch]
2026-07-02 Start work on memory / addressing board
    [ALU.kicad_sch, Control.kicad_sch, Memory.kicad_pcb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]
2026-07-03 Continue work on memory board
    [Memory.kicad_sch]
2026-07-05 Work on ALU PCB layout
    [ALU.kicad_pcb, ALU.kicad_sch]
2026-07-05 Finish pinout audit + fanout correction
    [ALU.kicad_sch, Control.kicad_sch, Memory.kicad_sch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]
2026-07-05 Start work on backplane and fix connectors
    [ALU.kicad_pcb, ALU.kicad_sch, Backplane.kicad_pcb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]
2026-07-07 Continue work on blackplane
    [Backplane.kicad_sch]
2026-07-09 Start work on front panel
    [Backplane.kicad_sch, Front Panel Address.kicad_pcb, Front Panel Address.kicad_sch]
2026-07-10 Continue work on front panel
    [Front Panel Address.kicad_sch]
2026-07-12 Finish up address front panel schematic
    [Front Panel Address.kicad_sch]
2026-07-12 Finish up front panel data schematic
    [Front Panel Address.kicad_sch, Front Panel Register.kicad_pcb, Front Panel Register.kicad_sch]
2026-07-13 Start work on front panel register layout
    [Front Panel Register.kicad_pcb, Front Panel Register.kicad_sch]
2026-07-14 Start work on front panel address layout
    [Front Panel Address.kicad_pcb, Front Panel Address.kicad_sch, Front Panel Register.kicad_pcb]
2026-07-16 Update backplane pin logic levels
    [ALU.kicad_sch, Backplane.kicad_sch, Control.kicad_sch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]
2026-07-17 Continue work on backplane
    [Backplane.kicad_sch]
2026-07-20 Switch out to 74LS253
    [Backplane.kicad_sch]
2026-07-21 Continue work on backplane schematic
    [Backplane.kicad_sch]
2026-07-22 Start laying out backplane
    [Backplane.kicad_pcb, Backplane.kicad_sch]
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2026-07-30 Adjust backplane spacing
    [Backplane.kicad_pcb]
2026-07-31 Continue backplane layout
    [Backplane.kicad_pcb]
2026-08-02 Add mounting holes
    [Backplane.kicad_pcb]
2026-08-03 Route address front panel
    [Backplane.kicad_pcb, Backplane.kicad_sch]
2026-08-04 Continue work on routing
    [ALU.kicad_pcb, Backplane.kicad_pcb, Front Panel Address.kicad_pcb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]
2026-08-05 Start work on TTY clock card
    [TTY Clock.kicad_pcb, TTY Clock.kicad_sch]
2026-08-06 Continue work on TTY clock schematic
    [TTY Clock.kicad_sch]
2026-08-07 Continue work on TTY / clock
    [TTY Clock.kicad_sch]
2026-08-08 Continue work on TTY clock card
    [TTY Clock.kicad_sch]
2026-08-09 Continue work on TTY clock
    [TTY Clock.kicad_sch]
2026-08-14 Continue work on Clock TTY card
    [TTY Clock.kicad_sch]
2026-08-16 Finish initial TTY clock schematic
    [TTY Clock.kicad_sch]
2026-08-17 The great PCB layout-athon
    [ALU.kicad_pcb, Control.kicad_pcb, Control.kicad_sch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]
2026-08-18 Gerber creation marathon
    [ALU-B_Cu.gbr, ALU-B_Mask.gbr, ALU-B_Paste.gbr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]
2026-08-19 Create gerber for register file
    [BOM.ods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]
2026-08-20 Upgrade register file
    [Registers.kicad_pcb]
2026-08-26 Start work on switch spacer
    [DSG.FCStd]
2026-08-28 Tweak DSG size
    [DSG-Part.stl, DSG.FCStd]
2026-08-29 Finish DSG
    [DSG-Part.stl, DSG.FCStd]
2026-08-30 Start work on data front panel model
    [ASG-Part.stl, ASG.FCStd, BOM.ods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]
2026-08-31 Continue work on front panel hardware
    [Data Front Panel Mount-Part.stl, Data Front Panel Mount.FCStd, Front Panel Bracket-Part.stl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]
2026-09-01 Finish address front panel and start artwork
    [Address Front Panel Mount.FCStd, Data Front Panel Mount.FCStd, Front Panel Bracket.FCStd]
2026-09-02 Finish front panel artwork
    [Address Front Panel Mount-Part.stl, Address Front Panel Mount.FCStd, Data Front Panel Mount-Part.stl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]
2026-09-03 Add front panel stand
    [Address Front Panel Mount.FCStd, BOM.ods, Front Panel Holder-Part.stl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]
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2026-09-10 Add step files for front panel mounts
    [Address Front Panel Mount-Part.step, Data Front Panel Mount-Part.step]
2026-09-10 Reduce bracket width
    [Front Panel Bracket-Part.stl]
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
